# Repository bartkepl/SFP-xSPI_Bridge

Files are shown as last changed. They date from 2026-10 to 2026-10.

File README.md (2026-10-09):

# SFP-xSPI Bridge
## Mostek OCTOSPI / QUADSPI / SPI ↔ SFP na FPGA Gowin GW1N-9

Moduł łączący dwa mikrokontrolery STM32 łączem światłowodowym punkt–punkt, bez stosu IP. Host zapisuje i odczytuje ramki przez OCTOSPI, QUADSPI lub zwykłe SPI; FPGA koduje je w 8b/10b i wysyła przez moduł SFP z prędkością 100 Mbaud, a po drugiej stronie odzyskuje zegar programowo (soft-CDR z nadpróbkowaniem). Tryb przezroczysty UART pozwala użyć pary mostków jako „przedłużacza” portu szeregowego, bez żadnego sterownika.









> **Status:** projekt FPGA ukończony i zweryfikowany w symulacji (testy modułów i testy end-to-end dwóch kompletnych mostków), biblioteka C dla STM32 gotowa i przetestowana na modelu mostka, schemat i PCB rev. A zweryfikowane ([raport](doc/pcb-rev-a.md)), pliki produkcyjne wygenerowane — przed zamówieniem prototypu. Uruchomienie sprzętowe według [planu](doc/sfp-xspi-bridge-plan.md#9-plan-uruchomienia-bring-up).

```
STM32 ══ xSPI ══ GW1N-9 ══ LVDS ══ SFP ~~~ światłowód ~~~ SFP ══ LVDS ══ GW1N-9 ══ xSPI ══ STM32
```

---

## Płytka

<!-- Rendery generuje pcb/gen_media.kicad_jobset -->

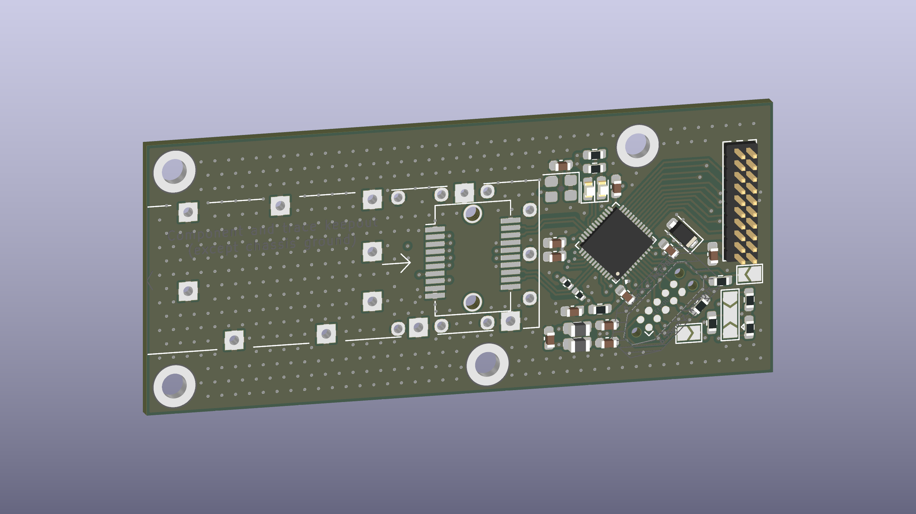
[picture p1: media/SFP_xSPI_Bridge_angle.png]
SFP-xSPI Bridge — widok pod kątem


| Góra (TOP) | Dół (BOTTOM) |
|---|---|
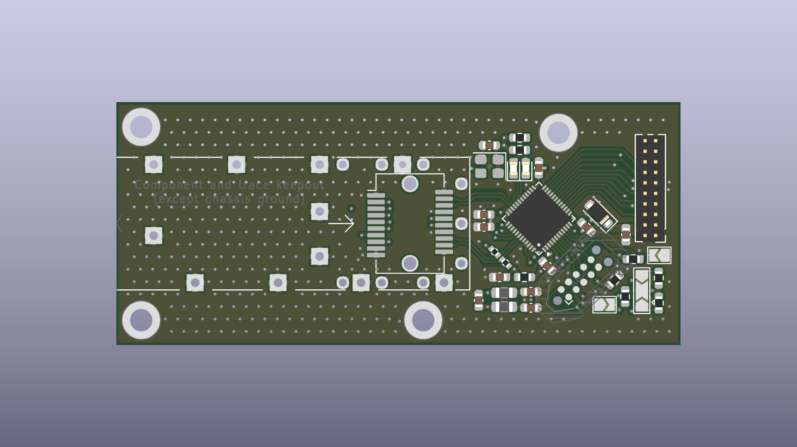
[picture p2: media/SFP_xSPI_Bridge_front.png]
TOP
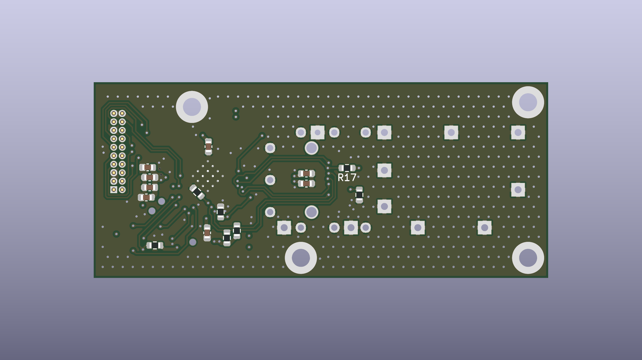
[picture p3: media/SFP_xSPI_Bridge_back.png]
BOTTOM
|  |  |

Płytka 4-warstwowa (JLC04161H-7628): pary LVDS na warstwie zewnętrznej nad ciągłą masą, płaszczyzna 3,3 V na warstwie wewnętrznej. Na płytce: klatka SFP, złącze hosta 2 × 10 (raster 1,27 mm), złącze programowania Tag-Connect TC2050 i zworka wyboru trybu. Zasilanie wyłącznie 3,3 V z hosta.

Wygenerowane PDF-y: [schemat](prod/sch/SFP_xSPI_Bridge.pdf) · [PCB](prod/pcb/SFP_xSPI_Bridge.pdf) · [interaktywny BOM](prod/ibom/SFP_xSPI_Bridge_ibom.html).

---

## Najważniejsze cechy

- **Łącze 100 Mbaud 8b/10b** przez standardowy moduł SFP bez wewnętrznego CDR (100BASE-FX / OC-3 lub 1000BASE-X, MM / SM, duplex lub BiDi).
- **Programowy odzysk zegara** — 4× nadpróbkowanie serializerami IDES8 (400 Msps), śledzenie fazy z histerezą, tolerancja odchyłki częstotliwości do ok. ±3900 ppm; oba końce na niezależnych generatorach, bez bufora elastycznego.
- **Ramki z CRC-32** (1–1024 B treści, pole TYPE do multipleksowania strumieni), kontrola przepływu XON/XOFF i gotowość odbiornika w sekwencji bezczynności — dane nie giną przy wolnym odbiorcy.
- **Interfejs hosta wzorowany na SPI NOR** — instrukcja i adres na 1 linii, dane na 1, 4 lub 8 liniach, SDR, tryb 0, SCLK do 40 MHz; współpracuje z OCTOSPI / XSPI / QUADSPI w trybie pośrednim i ze zwykłym SPI.
- **Spójne rejestry** — zatrzask przy opadnięciu CS, zapis stosowany po podniesieniu CS; FIFO TX 4 KiB i RX 8 KiB, przerwanie `HOST_IRQ_N`.
- **Tryb przezroczysty UART** — zworka lub rejestr; 8N1, 115 200 bit/s domyślnie, do ok. 3 Mbit/s, opcjonalnie RTS/CTS.
- **Zarządzanie modułem SFP** — I2C master w FPGA: pamięć A0h / A2h, automatyczny odczyt diagnostyki DDM, sygnały TX_DISABLE / TX_FAULT / LOS / MOD_ABS.
- **Diagnostyka łącza** — liczniki błędów kodu, CRC, długości, ramkowania, przepełnień i utrat synchronizacji; pętla zwrotna wewnątrz FPGA i echo ramek.
- **Biblioteka C dla STM32** konfigurowana przez `#define`, z portami HAL dla OCTOSPI, XSPI, QUADSPI i SPI.

---

## Specyfikacja

| Parametr | Wartość |
|---|---|
| FPGA | Gowin GW1N-UV9QN48C6/I5 (GW1N-9C), konfiguracja AUTOBOOT z wewnętrznej pamięci Flash |
| Łącze | 100 Mbaud, 8b/10b, ramki z CRC-32, bez retransmisji (błędy zgłaszane hostowi) |
| Przepustowość | do ok. 9,9 MB/s treści (ramki 1024 B) |
| Interfejs hosta | SPI 1-x-1, QSPI 1-0-4, OCTOSPI 1-0-8; SDR, tryb 0, SCLK ≤ 40 MHz |
| Bufory | FIFO TX 4 KiB, FIFO RX 8 KiB (BSRAM) |
| Tryb UART | 8N1, 115 200 bit/s (do ok. 3 Mbit/s), opcjonalnie RTS/CTS |
| Moduły SFP | INF-8074i, bez wewnętrznego CDR; SFP+ nieobsługiwane |
| Złącze hosta | 2 × 10, raster 1,27 mm: 3,3 V, SCLK, CS, IO0…IO7, DQS, IRQ, RST |
| Zasilanie | 3,3 V, ok. 0,45 A (moduł SFP do 300 mA) |
| PCB | 4 warstwy, 68 × 29,3 mm, 1,6 mm |
| Zajętość FPGA | 4483 LUT/ALU (52 %), 7 z 26 BSRAM; `clk_sys` 50 MHz (Fmax 56 MHz) |

---

## Architektura

```
             xSPI (SCLK ≤ 40 MHz)                                       LVDS 100 Mbaud
  STM32 ════════════════════════╗                                   ╔════════════════ SFP
                                ▼                                   │
          xspi_slave ─▶ csr_regs ─┬─▶ FIFO TX ─▶ framer + CRC ─▶ 8b/10b ─▶ OSER8 ─▶ TLVDS_OBUF ─▶ TD±
                                  │
                                  ├─◀ FIFO RX ◀─ deframer + CRC ◀─ 8b/10b ◀─ comma align ◀─ soft-CDR ◀─ IDES8 ◀─ RD±
                                  │
                                  ├─▶ I2C master + DDM ─▶ SFP SCL / SDA
                                  └─▶ sygnały SFP, LED, HOST_IRQ_N

  tryb UART:  UART_RX ─▶ pakietyzacja (ramki TYPE 0x01) ─▶ FIFO TX      FIFO RX ─▶ UART_TX
  zegary:     CLK_25M ─▶ rPLL 200 MHz (serializery) ─▶ CLKDIV /4 ─▶ clk_sys 50 MHz (logika)
```

Decyzje projektowe z uzasadnieniem: [rejestr ADR](doc/adr/README.md). Pełna koncepcja (piny, zegary, warstwa fizyczna, PCB, moduły, komendy, rejestry, uruchomienie): [`doc/sfp-xspi-bridge-plan.md`](doc/sfp-xspi-bridge-plan.md).

### Arkusze schematu

| Arkusz | Plik | Zawartość |
|---|---|---|
| root | [SFP_xSPI_Bridge.kicad_sch](pcb/SFP_xSPI_Bridge.kicad_sch) | połączenia hierarchiczne, otwory montażowe |
| EXT_IO | [ext_io.kicad_sch](pcb/ext_io.kicad_sch) | FPGA (zasilanie, konfiguracja, magistrala hosta), złącze hosta J3, Tag-Connect J2, zworki, TVS |
| SFP | [sfp.kicad_sch](pcb/sfp.kicad_sch) | klatka SFP, filtry zasilania modułu, terminacja i bias RX, generator 25 MHz, diody LED |

---

## Dokumentacja

| Dokument | Zawartość |
|---|---|
| [Interfejs hosta (datasheet)](doc/datasheet/index.md) | wyprowadzenia J3, parametry czasowe, komendy xSPI, mapa rejestrów, tryb UART, przykłady |
| [Biblioteka C (STM32)](doc/firmware.md) | konfiguracja, porty HAL, API, weryfikacja |
| [Koncepcja konstrukcji](doc/sfp-xspi-bridge-plan.md) | architektura, przydział pinów, zegary, PCB, moduły, uruchomienie |
| [Weryfikacja płytki rev. A](doc/pcb-rev-a.md) | DRC / ERC, zgodność z przydziałem pinów i INF-8074i, pary LVDS, zasilanie, pliki produkcyjne |
| [Projekt FPGA](doc/vhdl/index.md) | moduły VHDL, testbenche, symulacja, wyniki syntezy |
| [Testy end-to-end](doc/e2e/index.md) | dwa mostki połączone łączem: SPI, QSPI, OSPI, UART — z przebiegami |
| [Decyzje (ADR)](doc/adr/README.md) | kontekst, warianty i konsekwencje decyzji projektowych |

Dokumentacja jako serwis MkDocs (`mkdocs` 1.6, `mkdocs-material` 9.x):

```
python -m mkdocs serve        # podgląd: http://127.0.0.1:8000
```

---

## Szybki start

**FPGA** — Gowin EDA (projekt `vhdl/sfp_bridge/sfp_bridge.gprj`, VHDL-2008):

```
cd vhdl/sfp_bridge
gw_sh build.tcl               # synteza, PnR i bitstream
```

Bitstream: `vhdl/sfp_bridge/impl/pnr/sfp_bridge.fs`, programowanie przez JTAG (Gowin Programmer lub openFPGALoader).

**Symulacja** — GHDL 5 (VHDL-2008), na Windows w WSL; modele prymitywów z instalacji Gowin EDA:

```
$env:GOWIN_SIMLIB = "<Gowin EDA>\IDE\simlib\gw1n"   # PowerShell
cd vhdl\sim
.\run_tests.ps1               # wszystkie testbenche; .\view.ps1 <tb> — przebieg w GTKWave
```

**Firmware** — biblioteka w `firmware/sfp_bridge/`: skopiować `config/sfpb_config_template.h` jako `sfpb_config.h`, ustawić transport i uchwyt peryferium, wywołać `sfpb_init(&dev, NULL)`. Testy na PC: `make -C firmware/tests`.

**Bez hosta** — dwa mostki ze zwartą zworką `MODE_SEL` i dwa konwertery USB-UART (115 200 8N1) tworzą przezroczysty kanał szeregowy przez światłowód.

---

## Weryfikacja

| Obszar | Zakres | Wynik |
|---|---|---|
| Moduły FPGA | 24 samosprawdzające testbenche GHDL, testy mutacyjne | PASS |
| Łącze | dwa końce z odchyłką 200 ppm i jitterem, CDR do ±1000 ppm i ±0,3 UI | PASS |
| End-to-end | dwa kompletne mostki (modele prymitywów Gowin): SPI, QSPI, OSPI, UART zworką i rejestrem | PASS |
| Synteza | pełny układ, ograniczenia czasowe spełnione (`clk_sys` 56 MHz, `clk_host` 44 MHz) | OK |
| Biblioteka C | 207 sprawdzeń na modelu mostka, 17 mutacji wykrytych; kompilacja portów dla L4R5, H563, F446, L476, G0B1 | PASS |
| PCB | DRC i ERC bez błędów, przydział pinów 100 % zgodny z `.cst`, pary LVDS w regułach | OK |
| Sprzęt | uruchomienie prototypu rev. A | do wykonania |

---

## Roadmap

- [x] **Koncepcja** — architektura, dobór FPGA i modułów SFP, protokół łącza, interfejs hosta
- [x] **Schemat i PCB rev. A** w KiCad 10
- [x] **FPGA** — wszystkie moduły, integracja, ograniczenia czasowe, testy end-to-end
- [x] **Biblioteka C dla STM32** z testami na modelu mostka
- [x] **Weryfikacja płytki i pliki produkcyjne** rev. A
- [ ] **Zamówienie i montaż** prototypu
- [ ] **Uruchomienie** — konfiguracja FPGA, tryb UART przez światłowód, xSPI, I2C / DDM
- [ ] **Pomiary** — wykres oczkowy RD±, BER ≥ 10¹² bitów, różne moduły i tłumiki optyczne
- [ ] **Rozszerzenia** — 125 Mbaud, kolejna rewizja PCB z uwagami z uruchomienia

---

## Struktura repozytorium

```
.
├── doc/          # dokumentacja (MkDocs): koncepcja, datasheet, ADR, opisy modułów, testy end-to-end
├── firmware/     # biblioteka C dla STM32 (sfp_bridge), przykład, testy na PC
├── media/        # rendery 3D płytki
├── pcb/          # projekt KiCad 10 (schemat hierarchiczny, PCB, reguły DRC, biblioteka lokalna, jobsety)
├── prod/         # pliki produkcyjne: Gerbery (.zip), PDF schematu i PCB, interaktywny BOM
└── vhdl/         # projekt FPGA (Gowin EDA): źródła, ograniczenia, testbenche i skrypty symulacji
```

Pliki produkcyjne generują jobsety KiCad: [gen_prod.kicad_jobset](pcb/gen_prod.kicad_jobset) (PDF, BOM), [gen_gerber.kicad_jobset](pcb/gen_gerber.kicad_jobset) (Gerbery, wiercenia), [gen_media.kicad_jobset](pcb/gen_media.kicad_jobset) (rendery 3D).

---

## Referencje

- Gowin Semiconductor: DS100 (GW1N series), UG114 (GW1N-9 pinout), UG286 (zegary), UG289 (programowalne I/O), UG290 (programowanie i konfiguracja), UG284 (schematy), SUG935 (ograniczenia fizyczne)
- SFF Committee: INF-8074i (SFP MSA), SFF-8472 (diagnostyka modułów SFP)
- IEEE 802.3, klauzula 36 (kod 8b/10b, 1000BASE-X PCS)
- AMD/Xilinx XAPP224, XAPP523 — odzysk danych z nadpróbkowania
- STMicroelectronics: dokumentacja peryferiów OCTOSPI / XSPI / QUADSPI i sterowników HAL STM32Cube

---

## Licencja

[MIT](LICENSE) © 2026 bartkepl

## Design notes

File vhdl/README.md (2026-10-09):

# vhdl

Projekt FPGA mostka SFP-xSPI w Gowin EDA: VHDL-2008, synteza GowinSynthesis, układ GW1N-UV9QN48C6/I5 (GW1N-9C, `gw1n9c-003`).

```
constraints/
  sfp_bridge.cst           przydział pinów i standardy I/O
  sfp_bridge.sdc           ograniczenia czasowe (zegary, grupy asynchroniczne, opóźnienia xSPI)
sfp_bridge/
  sfp_bridge.gprj          projekt Gowin EDA
  build.tcl                budowa wsadowa (gw_sh)
  impl/                    wyniki syntezy i PnR (ignorowane), poza sfp_bridge_process_config.json
  src/pkg/                 bridge_pkg (stałe), code8b10b_pkg (kod 8b/10b)
  src/common/              sync_bit, reset_sync
  src/clk/                 clk_rst (rPLL, CLKDIV, resety), host_clk (DCS)
  src/fifo/                async_fifo
  src/link/                crc32, 8b/10b, tx_framer, rx_deframer, tx_gearbox, tx_phy, rx_phy,
                           cdr_os4x8, comma_align, link_ctrl
  src/uart/                uart_rx, uart_tx, uart_bridge
  src/host/                xspi_slave, csr_regs, frame_echo
  src/mgmt/                i2c_master, sfp_mgmt, leds
  src/top/                 sfp_bridge_top
sim/
  tb/                      testbenche tb_<moduł>.vhd, tb_pkg, e2e_bench (testy end-to-end)
  waves/                   widoki GTKWave (.gtkw)
  sources.txt              kolejność kompilacji do symulacji
  run_tests.ps1 / .sh      uruchamianie testów (GHDL)
  view.ps1                 podgląd przebiegu w GTKWave
  wave_svg.py              rysunki przebiegów testów end-to-end (doc/e2e/img)
  datasheet_svg.py         diagramy datasheetu (doc/datasheet/img)
```

Ustawienia projektu (`impl/sfp_bridge_process_config.json`): VHDL-2008, top `sfp_bridge_top`, piny MSPI jako GPIO (`-use_mspi_as_gpio 1`), konfiguracja AUTOBOOT.

## Budowa

```
cd sfp_bridge
gw_sh build.tcl
```

Bitstream: `sfp_bridge/impl/pnr/sfp_bridge.fs`.

## Symulacja

GHDL 5 (VHDL-2008); na Windows `run_tests.ps1` uruchamia `run_tests.sh` w WSL. Moduły z prymitywami Gowin korzystają z modeli producenta kompilowanych do biblioteki `gw1n`.

| Zmienna | Znaczenie |
|---|---|
| `GOWIN_SIMLIB` | katalog modeli symulacyjnych Gowin EDA: `<Gowin EDA>/IDE/simlib/gw1n` (wymagana) |
| `GHDL_WSL_DISTRO` | dystrybucja WSL z GHDL (domyślnie dystrybucja domyślna) |
| `GTKWAVE` | ścieżka do `gtkwave.exe` dla `view.ps1` (domyślnie `gtkwave` z `PATH`) |

```
cd sim
.\run_tests.ps1               # wszystkie testbenche
.\run_tests.ps1 tb_crc32      # wybrany testbench
.\view.ps1 tb_crc32           # przebieg w GTKWave
```

Opis modułów, wyniki testów i syntezy: [`../doc/vhdl/index.md`](../doc/vhdl/index.md); testy end-to-end: [`../doc/e2e/index.md`](../doc/e2e/index.md).

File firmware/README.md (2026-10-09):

# firmware

Biblioteka C `sfp_bridge` dla STM32 — host mostka SFP-xSPI. C11, bez dynamicznej alokacji, konfiguracja przez `#define` w `sfpb_config.h`, porty HAL dla OCTOSPI, XSPI, QUADSPI i SPI (opcjonalnie DMA) oraz własny transport.

```
sfp_bridge/include/   API (sfp_bridge.h), komendy i rejestry, interfejs transportu
sfp_bridge/config/    szablon sfpb_config.h
sfp_bridge/src/       implementacja
sfp_bridge/port/      porty STM32 HAL
examples/             przykład użycia
tests/                testy na PC z modelem mostka
```

Szybki start:

1. Dodać `sfp_bridge/src/*.c`, `sfp_bridge/port/*.c` i ścieżki `include/`, `src/`, `port/`.
2. Skopiować `sfp_bridge/config/sfpb_config_template.h` jako `sfpb_config.h`, ustawić `SFPB_TRANSPORT` i uchwyt peryferium.
3. `sfpb_init(&dev, NULL)`, w obsłudze EXTI `HOST_IRQ_N` — `sfpb_irq_notify(&dev)`, w pętli głównej — `sfpb_process(&dev, 0)`.

Testy: `make -C tests` (gcc).

Dokumentacja: [`../doc/firmware.md`](../doc/firmware.md); protokół i rejestry: [`../doc/datasheet/index.md`](../doc/datasheet/index.md).

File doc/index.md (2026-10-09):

# SFP-xSPI Bridge

Moduł mostka **OCTOSPI / QUADSPI / SPI ↔ SFP** łączący dwa mikrokontrolery STM32 łączem światłowodowym punkt–punkt, bez stosu IP. Transmisja odbywa się własnym protokołem ramkowym z kodowaniem 8b/10b i programowym odzyskiem zegara (soft-CDR) w FPGA Gowin GW1N-UV9QN48C6/I5. Tryb przezroczysty UART przenosi strumień bajtów między dwoma portami szeregowymi bez sterownika.

```
STM32 <== xSPI ==> GW1N-9 <== LVDS ==> SFP ~~~ światłowód ~~~ SFP <==> GW1N-9 <==> STM32
```

## Dokumentacja

| Część | Zawartość |
|---|---|
| [Koncepcja konstrukcji](sfp-xspi-bridge-plan.md) | architektura, przydział pinów, zegary, warstwa fizyczna i PCB, moduły FPGA, komendy xSPI, rejestry, plan uruchomienia |
| [Interfejs hosta (datasheet)](datasheet/index.md) | wyprowadzenia, parametry czasowe, komendy xSPI, mapa rejestrów, tryb UART |
| [Biblioteka C (STM32)](firmware.md) | konfiguracja, porty HAL, API, weryfikacja |
| [Weryfikacja płytki rev. A](pcb-rev-a.md) | reguły projektowe, zgodność połączeń, pary LVDS, zasilanie, pliki produkcyjne |
| [Projekt FPGA](vhdl/index.md) | struktura projektu, konwencje kodu, symulacja, opisy modułów, wyniki syntezy |
| [Testy end-to-end](e2e/index.md) | dwa kompletne mostki połączone łączem, z przebiegami |
| [Decyzje (ADR)](adr/README.md) | rejestr decyzji projektowych z uzasadnieniem |

## Budowa dokumentacji

```
python -m mkdocs serve     # podgląd: http://127.0.0.1:8000
python -m mkdocs build     # statyczny serwis w site/
```

Wymagania: `mkdocs` 1.6 i `mkdocs-material` 9.x.

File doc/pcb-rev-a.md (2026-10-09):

# Płytka rev. A — weryfikacja projektu

Raport z weryfikacji schematu i PCB rev. A przed wykonaniem prototypu. Zakres: zgodność połączeń z przydziałem pinów FPGA i dokumentacją elementów, reguły projektowe (DRC, ERC), prowadzenie par LVDS, zasilanie i odsprzęganie, wykonalność produkcyjna oraz komplet plików produkcyjnych.

## 1 Opis płytki

| Parametr | Wartość |
|---|---|
| Wymiary | 68,0 × 29,3 mm, 4 otwory montażowe M2,5 (GND) |
| Stos | 4 warstwy, 1,6 mm, JLC04161H-7628: L1 sygnały i pary LVDS, L2 GND, L3 +3V3, L4 sygnały i wylewka GND |
| Schemat | 3 arkusze: główny, `EXT_IO` (FPGA, złącze hosta, programowanie), `SFP` (klatka, filtry, terminacja RX, generator, diody) |
| Elementy | 53: U1 GW1N-UV9QN48C6/I5, J1 klatka SFP, J2 TC2050, J3 2 × 10 / 1,27 mm, Y1 25 MHz, L1/L2 1 µH, D1 TVS, D2/D3 LED, JP1–JP3, 17 rezystorów, 19 kondensatorów, H1–H4 |
| Zasilanie | 3,3 V z hosta (J3, piny 1–2), bez stabilizatora; TVS D1 przy złączu |
| Montaż | ręczny; elementy na obu stronach (na dolnej: 15 elementów pasywnych 0603 — kondensatory odsprzęgające i filtra SFP, część rezystorów) |

## 2 Reguły projektowe

**DRC** (wszystkie poziomy, z ponownym wypełnieniem stref i kontrolą zgodności ze schematem): 0 błędów, 0 niepołączonych elementów, 0 rozbieżności schemat–PCB. Ostrzeżenia:

| Ostrzeżenie | Liczba | Ocena |
|---|---|---|
| `silk_overlap` — nakładające się opisy D2/D3 i R1/JP2 | 6 | kosmetyka nadruku |
| `silk_edge_clearance` — obrys J1 przycięty krawędzią płytki | 3 | wynika z wysięgu klatki poza krawędź; bez wpływu |
| `lib_footprint_mismatch` — U1 | 1 | zamierzone: pole EPAD z przelotkami 0,3 mm zamiast 0,2 mm z biblioteki |

**ERC:** 0 błędów; 3 ostrzeżenia `lib_symbol_mismatch` (symbole zworek lutowanych różnią się od biblioteki) i 1 `multiple_net_names` (GND i EPAD U1 na jednym węźle — zamierzone, EPAD jest masą).

## 3 Połączenia

### 3.1 FPGA

Wszystkie przydziały `IO_LOC` z `vhdl/constraints/sfp_bridge.cst` porównano z sieciami padów U1 w PCB: 25 portów (pary różnicowe po pinie A), **zgodność 100 %**, w tym odwrócona para RD (`sfp_rd_n` na pinie 43, `sfp_rd_p` na 42, kompensowana w `rx_phy`). Bitstream jest budowany z tego samego pliku `.cst`.

| Obszar | Podstawa | Wynik |
|---|---|---|
| Zasilanie U1: VCC 12, 37; VCCX 36; VCCIO 1, 25; VSS 2, 26, EPAD | UG114 (QN48) | zgodne |
| Konfiguracja: MODE (48) 1 kΩ do GND (AUTOBOOT); JTAGSEL_N, RECONFIG_N, DONE — 10 kΩ do 3,3 V; TCK 4,7 kΩ do GND | UG290 (rys. 7-1, tab. 7-3) | zgodne |
| `CLK_25M` na dedykowanym wejściu PLL (35) | UG114, UG286 | zgodne |
| `MODE_SEL` (10): 10 kΩ do 3,3 V (R16), JP3 do GND | [ADR 0006](adr/0006-tryb-uart-przezroczysty.md) | zgodne |

### 3.2 Moduł SFP

| Obszar | Podstawa | Wynik |
|---|---|---|
| Złącze J1, 20 pinów: VeeT 1/17/20, VeeR 9/10/11/14, TD± 18/19, RD± 13/12, VccT 16, VccR 15, sygnały 2–8 | INF-8074i, rys. 3 | zgodne |
| Filtr zasilania: 2 × 1 µH, 0,1 µF przy VccT i VccR, 10 µF na VccR, 10 µF + 0,1 µF po stronie 3,3 V | INF-8074i, rys. 2A | zgodne |
| `SFP_TX_DIS`: pull-up 4,7 kΩ do 3,3 V (R17) — laser wyłączony w czasie konfiguracji FPGA | INF-8074i, rys. 2B | zgodne |
| `SFP_SCL`, `SFP_SDA`: pull-up 10 kΩ (R4, R3) | INF-8074i (4,7–10 kΩ) | zgodne |
| `RATE_SELECT`: 10 kΩ do GND (R8) | [koncepcja](sfp-xspi-bridge-plan.md), 5.1 | zgodne |
| `SFP_TX_FAULT`, `SFP_LOS`, `SFP_MOD_ABS`: wewnętrzne pull-upy FPGA zamiast 4,7–10 kΩ na płytce | INF-8074i, rys. 2B | odstępstwo rev. A — sygnały wolne i filtrowane (50 µs / 10 ms); rezystory w kolejnej rewizji |
| Terminacja RX: R9/R10 49,9 Ω przy pinach 42/43, Vbias 1,20 V (R11 2,1 kΩ / R12 1,2 kΩ, C6) | [ADR 0002](adr/0002-terminacja-rx-zewnetrzna.md) | zgodne; odcinek do odbiornika ok. 3,7 mm (wartość projektowa ≤ 2 mm) — pomijalne przy 100 Mbaud |

### 3.3 Złącza hosta i programowania

- J3 (2 × 10, 1,27 mm): 3,3 V na pinach 1–2, GND 3/5/15/19/20, magistrala xSPI, `HOST_IRQ_N`, `HOST_RST_N` — zgodnie z [koncepcją](sfp-xspi-bridge-plan.md), 5.5.
- J2 (TC2050): układ ARM Cortex 10-pin; AUX przez R7 1 kΩ i JP2 na `JTAGSEL_N` lub `DONE`; nRESET przez JP1 (domyślnie rozwarta) na `RECONFIG_N` — zgodnie z 5.6.

Elementy, dla których pinout oceniono według konwencji obudowy (bez porównania z kartą katalogową w tej weryfikacji): Y1 (generator 3225: 1 EN, 2 GND, 3 OUT, 4 VDD), D1 (SOD-123FL, katoda do 3,3 V), D2/D3 (anoda przez 1 kΩ do 3,3 V, ok. 1,3 mA).

## 4 Pary LVDS

| Para | Długość ścieżek P / N | Różnica | Szerokość / odstęp | Warstwa |
|---|---|---|---|---|
| TD (U1 34/33 → J1 18/19) | 9,43 / 9,76 mm | 0,33 mm | 0,20 / 0,20 mm | F.Cu, bez przelotek |
| RD (J1 13/12 → U1 42/43) | 11,37 / 11,71 mm | 0,33 mm | 0,20 / 0,20 mm | F.Cu, bez przelotek |

Obie pary w całości nad ciągłą płaszczyzną GND (L2). Różnica długości mieści się w regule 0,5 mm (`pcb/SFP_xSPI_Bridge.kicad_dru`, liczona wewnątrz pary); przy UI = 10 ns odpowiada ok. 2 ps i jest pomijalna. Odstęp od innych sieci i wylewek zgodny z regułą 0,5 mm; odcinki niesprzężone przy padach U1, J1 i rezystorach terminacji mieszczą się w limicie 2 mm.

## 5 Zasilanie i odsprzęganie

- Tor 3,3 V: J3 → ścieżka 1,0 mm (F.Cu) i 0,6–0,8 mm (B.Cu) → przelotki do płaszczyzny L3. Pobór szacowany 0,45 A (moduł SFP do 300 mA) — zapas kilkukrotny.
- Każdy pin zasilania U1 ma kondensator 100 nF w odległości 1,5–2,3 mm (C1, C2, C4, C5, C19); Y1 — C12 (3,4 mm); VccT / VccR — C7 / C8 (2,6 mm).
- Płaszczyzna L2 (GND) ciągła poza otworami przelotek. W L3 (+3V3) ścieżki VccR/VccT tworzą szczelinę pod obszarem złącza SFP; nad nią przebiegają wyłącznie wolne sygnały (I2C, LOS, MOD_ABS).
- Przelotki: 494 (490 × 0,6/0,3 mm, 4 × 0,45/0,3 mm), w tym 437 GND — zszycie wylewek L1/L4 z płaszczyzną L2 na całej powierzchni płytki i wzdłuż par LVDS.
- EPAD U1: 16 przelotek 0,3 mm do GND; moc FPGA < 0,5 W, brak innych źródeł ciepła.
- `CLK_25M` (9,7 mm): jedna para przelotek, odcinek na B.Cu; ścieżka powrotna przez płaszczyznę +3V3 odsprzęganą w pobliżu. Przy 25 MHz bez wpływu na działanie.

## 6 Wykonalność produkcyjna

| Parametr | Wartość | Próg technologii (JLCPCB, 4 warstwy) |
|---|---|---|
| Ścieżka / odstęp min. | 0,20 / 0,20 mm | 0,09 / 0,09 mm |
| Otwór min. | 0,30 mm | 0,30 mm bez dopłaty |
| Przelotka min. | 0,45 / 0,30 mm | 0,4–0,45 / 0,3 mm bez dopłaty |
| Via-in-pad | EPAD, bez wypełniania | bez opcji płatnych |
| Odstęp miedzi od krawędzi | ≥ 0,5 mm | 0,2–0,3 mm |

- Klatka J1 wystaje poza krawędź płytki (montaż klatki do panelu urządzenia); wysięg należy porównać z rysunkiem zamawianej klatki ([koncepcja](sfp-xspi-bridge-plan.md), rozdz. 10).
- Brak fiducjali i punktów testowych — zbędne przy montażu ręcznym.

## 7 Pliki produkcyjne

| Plik | Zawartość |
|---|---|
| `prod/SFP_xSPI_Bridge.zip` | Gerbery 4 warstw miedzi, maski, pasty, nadruki, obrys; wiercenia PTH i NPTH (13 plików) |
| `prod/sch/SFP_xSPI_Bridge.pdf` | schemat |
| `prod/pcb/SFP_xSPI_Bridge.pdf` | rysunek PCB |
| `prod/ibom/SFP_xSPI_Bridge_ibom.html` | interaktywny BOM do montażu ręcznego |
| `media/SFP_xSPI_Bridge_{angle,front,back}.png` | rendery 3D |

Pliki generują jobsety KiCad (`pcb/gen_gerber.kicad_jobset`, `gen_prod.kicad_jobset`, `gen_media.kicad_jobset`) z bieżącej wersji schematu i PCB.

## 8 Wynik

Płytka rev. A jest gotowa do wykonania. Połączenia FPGA są zgodne z plikiem ograniczeń bitstreamu, połączenia modułu SFP i filtr zasilania — z INF-8074i; pary LVDS spełniają reguły projektowe; DRC i ERC nie zgłaszają błędów.

Uwagi do kolejnej rewizji (nie blokują rev. A):

1. Pull-upy 4,7–10 kΩ na `SFP_TX_FAULT`, `SFP_LOS`, `SFP_MOD_ABS`.
2. Uporządkowanie nadruku (D2/D3, R1/JP2); nazwa i rewizja płytki na nadruku oraz w tabliczkach arkuszy.
3. Model 3D klatki SFP i numery katalogowe (MPN) w polach symboli.
4. Złącze hosta z kluczem (box header 1,27 mm) albo wyraźne oznaczenie pinu 1.
5. Terminacja RX bliżej pinów 42/43, `CLK_25M` w całości na F.Cu.

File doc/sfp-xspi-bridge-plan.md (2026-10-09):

# SFP-xSPI Bridge — koncepcja konstrukcji

Moduł mostka **OCTOSPI / QUADSPI / SPI ↔ SFP (światłowód)** do łączenia dwóch mikrokontrolerów (STM32) łączem optycznym punkt–punkt, bez stosu IP. Własny, lekki protokół ramkowy z kodowaniem 8b/10b i programowym odzyskiem zegara (soft-CDR) w małym FPGA Gowin. Tryb przezroczysty UART pozwala użyć mostka bez hosta SPI.

| Element | Wybór |
|---|---|
| FPGA | Gowin **GW1N-UV9QN48C6/I5** (GW1N-9, wersja C) — wybór uzasadnia [ADR 0001](adr/0001-fpga-gw1n-9.md) |
| Narzędzia | KiCad 10 (PCB), Gowin EDA (VHDL-2008), GHDL + GTKWave (symulacja, [ADR 0003](adr/0003-weryfikacja-ghdl.md)), C11 (biblioteka STM32) |
| Prędkość linii | **100 Mbaud** (8b/10b → 80 Mbit/s → ok. 9 MB/s danych użytecznych) |
| Interfejs hosta | SPI (1-x-1), QSPI (1-0-4), OCTOSPI (1-0-8), SDR, tryb 0, SCLK ≤ 40 MHz ([ADR 0009](adr/0009-interfejs-hosta.md)) — albo tryb przezroczysty UART ([ADR 0006](adr/0006-tryb-uart-przezroczysty.md)) |
| Protokół łącza | ramki z CRC-32 bez retransmisji, gotowość odbiornika i XON/XOFF w sekwencji bezczynności ([ADR 0005](adr/0005-protokol-lacza.md), [ADR 0008](adr/0008-stan-lacza.md)) |
| Zegar logiki | `clk_sys` = 50 MHz, serializery IDES8/OSER8 przy 200 MHz ([ADR 0007](adr/0007-zegar-systemowy-50mhz.md)) |
| Strona optyczna | moduł SFP (INF-8074i) bez wewnętrznego CDR: 100BASE-FX / OC-3 lub 1000BASE-X (MM/SM, duplex lub BiDi); SFP+ nieobsługiwane |
| Zasilanie | jedno **3,3 V** (wersja UV FPGA, moduł SFP) |

Dokument opisuje przyjęte rozwiązania konstrukcyjne: architekturę, przydział pinów, zegary, warstwę fizyczną i płytkę, projekt FPGA, interfejs hosta, bibliotekę STM32 oraz plan uruchomienia. Uzasadnienia decyzji zawiera [rejestr ADR](adr/README.md), szczegóły programowania — [datasheet interfejsu hosta](datasheet/index.md). Pozycje oznaczone **[DO WERYFIKACJI]** wymagają potwierdzenia na prototypie lub w dokumentacji wybranych elementów (rozdział 10).

---

## 1. Architektura

```
            OCTOSPI/QSPI/SPI                       LVDS 100 Mbaud
  STM32  <=====================>  GW1N-9    <=====================>  SFP  ~~~ światłowód ~~~  SFP <=> GW1N <=> STM32
  (master)   CLK, CS, IO0..7,      (FPGA)     TD±  -> moduł SFP
             DQS, IRQ, RST                   RD±  <- moduł SFP
                                   I2C master ---> SFP EEPROM/DDM (0x50/0x51)
                                   GPIO ---------> TX_DISABLE, TX_FAULT, LOS, MOD_ABS

  tryb UART (zworka MODE_SEL):  urządzenie UART <== RX/TX (IO0/IO1), opcj. RTS/CTS ==> GW1N-9 <== LVDS ==> ...
```

Wewnątrz FPGA:

```
 xSPI slave ─> rejestry/CSR ─┬─> TX FIFO ─> framer ─> CRC32 ─> enc 8b/10b ─> serializer ─> TLVDS_OBUF ─> SFP TD±
  (domena SCLK)              │
                             ├─< RX FIFO <─ deframer <─ CRC check <─ dec 8b/10b <─ comma align <─ soft-CDR <─ IDES8 <─ TLVDS_IBUF <─ SFP RD±
                             │
                             ├─> I2C master + mailbox + autopolling DDM ─> SFP SCL/SDA
                             └─> GPIO SFP, LED, IRQ

 tryb UART: uart_rx ─> pakietyzator (ramki TYPE 0x01) ─> TX FIFO ;  RX FIFO ─> depakietyzator ─> uart_tx
```

Domeny zegarowe:

| Domena | Źródło | Częstotliwość | Co pracuje |
|---|---|---|---|
| `clk_spi` / `clk_host` | pin SCLK od MCU (przez `DCS`; w trybach UART i echa `clk_sys`) | ≤ 40 MHz | slave xSPI, strona hosta FIFO |
| `clk_fast` | PLL | 200 MHz | FCLK serializerów IDES8 / OSER8 |
| `clk_sys` | CLKDIV(/4) z `clk_fast` | 50 MHz | całe łącze: CDR, 8b/10b, framer, CRC, FIFO (strona łącza), I2C, UART, CSR — [ADR 0007](adr/0007-zegar-systemowy-50mhz.md) |

Przejścia między domenami: asynchroniczne FIFO (BSRAM w trybie semi-dual port; wskaźnik odczytu w kodzie Graya, zatwierdzony wskaźnik zapisu przez handshake — [`async_fifo`](vhdl/async_fifo.md)) oraz synchronizatory 2-FF dla pojedynczych bitów ([`sync_bit`](vhdl/sync.md)). Reset: [ADR 0004](adr/0004-strategia-resetu.md).

---

## 2. Kluczowe parametry układu (z DS100, wersja 3.3.3E)

Kolumna GW1N-4 pozostaje dla porównania; układem docelowym jest GW1N-9 ([ADR 0001](adr/0001-fpga-gw1n-9.md)).

| Parametr | GW1N-4 | GW1N-9 | Uwagi |
|---|---|---|---|
| LUT4 / FF | 4608 / 3456 | 8640 / 6480 | |
| BSRAM | 10 × 18 kbit (180 kbit) | 26 × 18 kbit (468 kbit) | |
| PLL | 2 | 2 | |
| User Flash | 256 kbit | 608 kbit | wewnętrzny Flash konfiguracji + user Flash |
| QN48: I/O użytkownika (pary true LVDS) | **40 (9)** | **40 (12)** | QN48F dla GW1N-9: 40 (11) |
| IDES4, max szybkość szeregowa (C6/I5) | 750 Mbps | 750 Mbps | |
| IDES8/10, max (C6/I5) | 1000 Mbps | 1000 Mbps | IDES8/OSER8 pracują przy 400 Msps |
| PLL FIN | 3–400 MHz | 3–400 MHz | |
| PLL VCO (C6/I5) | 400–1000 MHz | 400–1200 MHz | |
| PLL FOUT max (C6/I5) | 500 MHz | 600 MHz | |
| LVDS wyjście VOD / VOS | 250–450 mV / 1,125–1,375 V | jw. | przy RT = 100 Ω |
| LVDS wejście VCM / VTHD | 0,05–2,1 V / ±100 mV | jw. | |
| Oscylator wewnętrzny | 105 MHz (ok. ±7%) | 125 MHz (±5%) | **nie** do łącza |

Ważne ograniczenia z DS100:

- **GW1N-9 wersja C** (GW1N-UV9QN48C6/I5): BSRAM obsługuje tryb dual-port, lecz nie obsługuje szerokości danych 1 i 2 bit. FIFO pozostaje w trybie **semi-dual port** (zapis port A, odczyt port B, osobne zegary).
- **GW1N-9 wersja C:** ograniczenia VCCIO dla Bank0/1/3 nie obowiązują. Wszystkie banki pracują przy 3,3 V.
- Ograniczenie GW1N-4 (piny `IOL10x`/`IOR10x` bez IO logic) nie dotyczy GW1N-9 (UG289, rozdz. 4).
- **UV:** jeżeli w obudowie VCC i VCCX dzielą pin, VCC musi wynosić 2,5–3,3 V. Przy jednym 3,3 V spełnione.
- **True LVDS input** wymaga terminacji 100 Ω. W GW1N-9 wewnętrzna programowalna terminacja 100 Ω jest dostępna **wyłącznie w banku 0** (UG289, rozdz. 3.3.2; atrybut `.cst`: `DIFF_RESISTOR=ON`). Wariantem podstawowym jest terminacja zewnętrzna (5.2, [ADR 0002](adr/0002-terminacja-rx-zewnetrzna.md)); wewnętrzna pozostaje opcją awaryjną.
- Wejście różnicowe (`TLVDS_IBUF`) obsługują wszystkie banki. Wyjście true LVDS (`TLVDS_OBUF`) wyłącznie pary oznaczone w UG114 jako *TRUE*. Prąd wyjścia LVDS25 w GW1N-9: 1,25 / 2 / 2,5 / 3,5 mA (DS100, tab. 2-1).
- Podczas konfiguracji wszystkie GPIO są w stanie wysokiej impedancji ze słabym pull-upem. Uwzględnić w sterowaniu `TX_DISABLE` (pull-up = laser wyłączony, to dobrze).
- **QN48, tryb konfiguracji:** MODE0 jest wewnętrznie zwarty do masy, MODE1 i MODE2 są połączone na pinie 48. Pin 48 w stanie niskim daje `000` = AUTOBOOT, w stanie wysokim `110` = DUAL BOOT (UG290, tab. 5-1). Ze względu na wewnętrzny pull-up pin 48 wymaga **zewnętrznego rezystora do masy**.

---

## 3. Przydział pinów

Numery pinów pochodzą z UG114 (GW1N-9 Pinout, kolumna QN48). Przydział, wszystkie alternatywy z tabeli 3.3 oraz warianty negatywne są sprawdzone syntezą i PnR w Gowin EDA 1.9.11.03 (projekt próbny z rPLL, CLKDIV, serializerami i kompletem portów). Plik ograniczeń: `vhdl/constraints/sfp_bridge.cst`.

Bilans: 41 wyprowadzeń I/O w QN48, z czego 8 to piny konfiguracyjne (3–9, 48), 27 jest przydzielonych (w tym `MODE_SEL`, [ADR 0006](adr/0006-tryb-uart-przezroczysty.md)), 6 pozostaje w zapasie.

Rozkład na obudowie (numeracja przeciwnie do ruchu wskazówek zegara od lewego górnego narożnika): lewa krawędź 1–12, dolna 13–24, prawa 25–36, górna 37–48. Wynikający z tego układ płytki: **złącze hosta przy dolnej krawędzi, klatka SFP przy prawym górnym narożniku, JTAG przy lewej krawędzi**.

```
                   48   47  46  45  44  43  42  41  40  39  38  37
                  MODE SDA SCL  -   -  RDN RDP ABS LOS FLT DIS VCC
     VCCIO0/3  1                                                    36  VCCX
          VSS  2                                                    35  CLK_25M
    JTAGSEL_N  3                                                    34  TD_P
          TMS  4                                                    33  TD_N
          TCK  5                                                    32  LED_ACT
          TDI  6                    GW1N-UV9QN48                    31  LED_LINK
          TDO  7                                                    30  -
   RECONFIG_N  8                                                    29  -
         DONE  9                                                    28  -
     MODE_SEL 10                                                    27  -
   HOST_RST_N 11                                                    26  VSS
          VCC 12                                                    25  VCCIO1/2
                  IRQ  CS  IO0 IO1 IO2 IO3 SCLK DQS IO4 IO5 IO6 IO7
                   13   14  15  16  17  18  19  20  21  22  23  24
```

### 3.1 Tabela sygnałów

Nazwy sieci w schemacie pisane są wielkimi literami, porty VHDL małymi (`SFP_TD_P` ↔ `sfp_td_p`).

| Sygnał | Kier. | Standard I/O | Pin | Bank | Miejsce w UG114 | Uwagi |
|---|---|---|---|---|---|---|
| `SFP_TD_P` | out | LVDS25, DRIVE=3.5 | **34** | 1 | IOR11A (MI/D7) | para z wyjściem true LVDS; funkcja MSPI nieużywana w AUTOBOOT |
| `SFP_TD_N` | out | LVDS25 | **33** | 1 | IOR11B (MO/D6) | |
| `SFP_RD_P` | in | LVDS25 | **42** | 0 | IOT32B | IDES8; terminacja zewnętrzna (5.2), wewnętrzna jako opcja awaryjna; **polaryzacja odwrócona** (3.2, reguła 9) |
| `SFP_RD_N` | in | LVDS25 | **43** | 0 | IOT32A | wejście `I` bufora `TLVDS_IBUF` |
| `CLK_25M` | in | LVCMOS33 | **35** | 1 | IOR5A (RPLL_T_in) | dedykowane wejście prawego PLL |
| `XSPI_SCLK` | in | LVCMOS33 | **19** | 2 | IOB29A (GCLKT_4) | wejście zegara globalnego, środek magistrali; ≤ 40 MHz ([ADR 0009](adr/0009-interfejs-hosta.md)) |
| `XSPI_CS_N` | in | LVCMOS33, pull-up | **14** | 2 | IOB8B | |
| `XSPI_IO0` | inout | LVCMOS33 | **15** | 2 | IOB17A | |
| `XSPI_IO1` | inout | LVCMOS33 | **16** | 2 | IOB17B | |
| `XSPI_IO2` | inout | LVCMOS33 | **17** | 2 | IOB27A | |
| `XSPI_IO3` | inout | LVCMOS33 | **18** | 2 | IOB27B | |
| `XSPI_DQS` | out | LVCMOS33 | **20** | 2 | IOB29B (GCLKC_4) | nieużywany (SDR), stan wysokiej impedancji; rezerwa na tryb DTR |
| `XSPI_IO4` | inout | LVCMOS33 | **21** | 2 | IOB35A | |
| `XSPI_IO5` | inout | LVCMOS33 | **22** | 2 | IOB35B | |
| `XSPI_IO6` | inout | LVCMOS33 | **23** | 2 | IOB39A | |
| `XSPI_IO7` | inout | LVCMOS33 | **24** | 2 | IOB39B | |
| `HOST_IRQ_N` | out | LVCMOS33 | **13** | 2 | IOB8A | open-drain lub push-pull |
| `HOST_RST_N` | in | LVCMOS33, pull-up | **11** | 3 | IOL15B (GCLKC_6) | reset logiki, nie rekonfiguracja |
| `SFP_TX_DIS` | out | LVCMOS33 | **38** | 1 | IOT42B | pull-up wewnątrz modułu (laser wyłączony, dopóki FPGA nie wystawi 0) |
| `SFP_TX_FAULT` | in | LVCMOS33, PULL_MODE=UP | **39** | 1 | IOT42A | brak zewnętrznego pull-upu (rev. A) — wewnętrzny pull-up FPGA |
| `SFP_LOS` | in | LVCMOS33, PULL_MODE=UP | **40** | 1 | IOT37B | jw. |
| `SFP_MOD_ABS` | in | LVCMOS33, PULL_MODE=UP | **41** | 1 | IOT37A | MOD_DEF0; jw. |
| `SFP_SCL` | inout (OD) | LVCMOS33, OPEN_DRAIN | **46** | 3 | IOT12B | MOD_DEF1; pull-up 4,7 kΩ |
| `SFP_SDA` | inout (OD) | LVCMOS33, OPEN_DRAIN | **47** | 3 | IOT12A | MOD_DEF2; pull-up 4,7 kΩ |
| `MODE_SEL` | in | LVCMOS33, PULL_MODE=UP | **10** | 3 | IOL15A (GCLKT_6) | wybór trybu ([ADR 0006](adr/0006-tryb-uart-przezroczysty.md)): otwarta zworka = xSPI, zwarta do masy = UART; pull-up 10 kΩ |
| `LED_LINK` | out | LVCMOS33 | **31** | 1 | IOR12B (MCLK/D4) | aktywny stanem niskim (3V3 → 1 kΩ → LED → pin) |
| `LED_ACT` | out | LVCMOS33 | **32** | 1 | IOR12A (MCS_N/D5) | aktywny stanem niskim |

Piny zapasowe: **27/28** (IOR24, para z wyjściem true LVDS), **29/30** (IOR17, para z wyjściem true LVDS, GCLKT_3), **44/45** (IOT22, bank 0, para z opcją terminacji wewnętrznej); w rev. A niepodłączone (znaczniki no-connect).

Piny konfiguracyjne i zasilania, **nieużywane jako GPIO**:

| Pin | Sygnał | Połączenie |
|---|---|---|
| 3 | `JTAGSEL_N` (także LPLL_T_in) | pull-up 4,7–10 kΩ; AUX programatora przez JP2 (5.6); opcja „Use JTAG as regular IO” wyłączona |
| 4, 5, 6, 7 | `TMS`, `TCK`, `TDI`, `TDO` | złącze TC2050 (5.6); TCK z pull-downem 4,7 kΩ (UG290, tab. 7-3) |
| 8 | `RECONFIG_N` | pull-up 10 kΩ; nRESET programatora przez JP1, domyślnie rozwartą (5.6) |
| 9 | `DONE` | pull-up 10 kΩ (R6); opcjonalnie AUX programatora przez JP2; bez diody LED; `READY` nie jest wyprowadzony w QN48 |
| 48 | `MODE2` + `MODE1` (MODE0 wewnętrznie do masy) | **1 kΩ do masy** (UG290, Figure 7-1) → `000` = AUTOBOOT. Wewnętrzny pull-up do 150 µA (DS100, IPU): 10 kΩ dałoby do 1,5 V, czyli ryzyko odczytu stanu wysokiego i DUAL BOOT |
| 12, 37 | `VCC` | 3,3 V (wersja UV, wewnętrzny stabilizator rdzenia) |
| 36 | `VCCX` | 3,3 V |
| 1 | `VCCIO0` / `VCCIO3` | 3,3 V |
| 25 | `VCCIO1` / `VCCIO2` | 3,3 V |
| 2, 26, EPAD (49) | `VSS` | masa; **EPAD obowiązkowo do masy** — symbol nie ma pinu EPAD, połączenie wykonuje się ręcznie w PCB (5.3.5) |

### 3.2 Reguły przydziału

1. **Wszystkie banki VCCIO = 3,3 V.** LVDS25 (TLVDS) działa przy VCCIO 2,5/3,3 V jako wejście i wyjście (DS100, tab. 2-1, 2-2).
2. **TD wyłącznie na parze z wyjściem true LVDS** (kolumna „LVDS” = TRUE w UG114). Umieszczenie `TLVDS_OBUF` na parze bez tej cechy (np. 45/44, 39/38) kończy się błędem CT1005.
3. **RD na dowolnej parze różnicowej** — wejście `TLVDS_IBUF` obsługują wszystkie banki. Atrybut `DIFF_RESISTOR` jest akceptowany wyłącznie w banku 0 (poza nim błąd CT1118, także przy wartości `OFF`); po przeniesieniu RD poza bank 0 atrybut należy usunąć.
4. **IDES8/OSER8:** HCLK z PLL obejmuje wszystkie banki (PnR: `BANK0_BANK1_HCLK0`, `BANK2_BANK3_HCLK0`); w GW1N-9 nie ma pinów bez IO logic.
5. **`XSPI_SCLK` na pinie GCLKT.** SCLK do 40 MHz nie da się nadpróbkować zegarem `clk_sys`, więc taktuje on bezpośrednio stronę hosta. Pin GCLKC tej samej pary pozostaje zwykłym I/O.
6. **Magistrala xSPI w jednym banku** (bank 2, dolna krawędź) z krótkimi i równymi ścieżkami.
7. **`CLK_25M` na dedykowanym wejściu PLL.** Wejście przez sieć globalną (pin GCLKT) działa, ale dodaje jitter na wejściu PLL.
8. **Piny MSPI (31–34)** pracują jako GPIO dzięki opcji `-use_mspi_as_gpio 1`; wymaga to trybu AUTOBOOT (pin 48 do masy).
9. **Polaryzacja par LVDS może być odwrócona na płytce**, jeśli upraszcza to prowadzenie pary (bez skrzyżowania i bez przelotek). Pin A pary (true) jest zawsze wejściem `I` bufora `TLVDS_IBUF` lub wyjściem `O` bufora `TLVDS_OBUF`; port VHDL przypisany do tego pinu w `.cst` (`IO_LOC "<port>" A,B`) nosi nazwę sieci, która jest do niego podłączona. Odwrócenie kompensuje generyk `INVERT` modułu `rx_phy` / `tx_phy`. Stan w rev. A: **RD odwrócona** (`SFP_RD_N` na pinie A 43, `SFP_RD_P` na pinie B 42, `rx_phy` z `INVERT => true`), **TD bez zmian** (`SFP_TD_P` na pinie A 34).

### 3.3 Alternatywy przydziału

Warianty na wypadek trudności w schemacie lub prowadzeniu ścieżek. Wariant oznaczony „PnR OK” przeszedł syntezę, PnR i generację bitstreamu przy pozostałych pinach bez zmian, o ile w kolumnie warunków nie podano inaczej.

| Sygnał | Podstawowy | Alternatywa | Warunki / koszt | Weryfikacja |
|---|---|---|---|---|
| `SFP_TD_P/N` | 34/33 | **28/27** (IOR24) | prawa krawędź niżej, dalej od SFP | PnR OK |
| | | **30/29** (IOR17) | zajmuje GCLKT_3 | PnR OK |
| | | **11/10** (IOL15) | lewa krawędź; `HOST_RST_N` → np. 28; zajmuje GCLKT_6 | PnR OK |
| | | 13–24 (bank 2) | pary TRUE, ale kolidują z magistralą xSPI | nie zalecane |
| `SFP_RD_N/P` (odwrócona, reguła 9) | 43/42 | **45/44** (IOT22, bank 0) | zachowuje opcję terminacji wewnętrznej | PnR OK (z `DIFF_RESISTOR=ON`) |
| | | **39/38** (IOT42, bank 1) | najbliżej narożnika SFP; tylko terminacja zewnętrzna; `SFP_TX_DIS`/`SFP_TX_FAULT` → 44/45 | PnR OK |
| | | **41/40** (IOT37, bank 1) | tylko terminacja zewnętrzna; `SFP_LOS`/`SFP_MOD_ABS` → 44/45 | PnR OK |
| | | **28/27**, **30/29** (bank 1) | tylko terminacja zewnętrzna | PnR OK |
| `CLK_25M` | 35 | **30** (GCLKT_3) lub **10** (GCLKT_6) | wejście PLL przez sieć globalną, większy jitter | PnR OK (30) |
| | | 3 (LPLL_T_in) | koliduje z `JTAGSEL_N` | nie zalecane |
| `XSPI_SCLK` | 19 | **10** (GCLKT_6) lub **30** (GCLKT_3) | 19 staje się zwykłym I/O banku 2 | PnR OK (oba) |
| `XSPI_IO0..7`, `XSPI_CS_N`, `XSPI_DQS`, `HOST_IRQ_N` | 13–18, 20–24 | **dowolna permutacja** w obrębie 13–24 (poza pinem SCLK) | kolejność bitów ustala `.cst`; logika bez zmian | — |
| Wolne sygnały SFP, LED, `HOST_RST_N` | jak w 3.1 | dowolny pin zapasowy: 10, 27–30, 44, 45 | `OPEN_DRAIN=ON` dla SCL/SDA działa na każdym pinie | — |

Jako alternatyw **nie** wolno użyć pinów 3–9 i 48 (konfiguracja) ani 1, 2, 12, 25, 26, 36, 37 (zasilanie).

---

## 4. Zegary i PLL

```
CLK_25M (25 MHz, ±25 ppm, CMOS 3,3 V)
   └─> rPLL: IDIV=1, FBDIV=8, ODIV=4  → VCO = 800 MHz, CLKOUT = 200 MHz  (clk_fast, HCLK)
          └─> CLKDIV (DIV_MODE="4")   → 50 MHz                            (clk_sys)
```

- 200 MHz FCLK × DDR daje **400 Msps**, czyli dokładnie **4× nadpróbkowanie przy 100 Mbaud**. IDES8 oddaje 8 próbek (2 bity) co takt `clk_sys` (50 MHz) — [ADR 0007](adr/0007-zegar-systemowy-50mhz.md).
- VCO 800 MHz mieści się w zakresie 400–1200 MHz (GW1N-9 C6/I5).
- `CLKDIV` zamiast drugiego wyjścia PLL, żeby `clk_sys` był fazowo powiązany z FCLK gearboxa (wymagane przez IDES/OSER).
- Oba końce łącza pracują na niezależnych generatorach. Różnicę ppm absorbuje sam CDR z nadpróbkowaniem (wydaje 1, 2 lub 3 bity na takt, nominalnie 2), więc **bufor elastyczny nie jest potrzebny**.
- Rozszerzenie do 125 Mbaud: `clk_fast` = 250 MHz, `clk_sys` = 62,5 MHz (VCO 1000 MHz, w zakresie GW1N-9 do 1200 MHz). Prędkość linii jest parametrem pakietu `bridge_pkg` (`LINE_BAUD`), z którego wynikają nastawy PLL.

---

## 5. Warstwa fizyczna (PCB)

### 5.1 SFP

Moduł i złącze zgodne z SFP MSA (INF-8074i). SFF-8431 opisuje elektrykę SFP+ (10 Gb/s) i nie jest podstawą tego projektu. Klatka i złącze 20-pinowe są wspólne dla SFP i SFP+.

**Klasa modułów.** Obsługiwane są moduły SFP bez wewnętrznego CDR: 100BASE-FX / OC-3 (125–155 Mb/s, zakres zgodny z linią 100–125 Mbaud) oraz 1000BASE-X (1,25 Gb/s). Moduły SFP+ (10G) nie są obsługiwane: zwykle zawierają CDR zablokowany na ok. 10 Gbaud i nie są specyfikowane dla 100 Mbaud.

Przyporządkowanie pinów złącza (INF-8074i, Table 1; numeracja zgodna z symbolem `Connector_SFP_and_Cage`):

| Pin SFP | Nazwa (INF-8074i) | Sieć / FPGA | Połączenie |
|---|---|---|---|
| 1, 17, 20 | VeeT | GND | masa nadajnika |
| 2 | TX Fault | `SFP_TX_FAULT` → pin 39 | wyjście OC/OD modułu; w rev. A wewnętrzny pull-up FPGA (`PULL_MODE=UP`), INF-8074i zaleca 4,7–10 kΩ |
| 3 | TX Disable | `SFP_TX_DIS` ← pin 38 | wejście modułu z wewnętrznym pull-upem 4,7–10 kΩ (stan wysoki lub rozwarty = laser wyłączony); pull-up 4,7 kΩ na płytce (R17) utrzymuje laser wyłączony także w czasie konfiguracji FPGA |
| 4 | MOD-DEF2 | `SFP_SDA` ↔ pin 47 | SDA interfejsu 2-wire (EEPROM A0h, DDM A2h); pull-up 4,7–10 kΩ |
| 5 | MOD-DEF1 | `SFP_SCL` ← pin 46 | SCL, maks. 100 kHz; pull-up 4,7–10 kΩ |
| 6 | MOD-DEF0 | `SFP_MOD_ABS` → pin 41 | zwarte do masy w module = moduł obecny; pull-up jak TX Fault |
| 7 | Rate Select | — | **jeden pin**; opcjonalne wejście modułu z wewnętrznym pull-downem > 30 kΩ (niski lub rozwarty = pasmo zmniejszone, wysoki = pełne); 10 kΩ do masy. W SFP+ ten pin nazywa się RS0 |
| 8 | LOS | `SFP_LOS` → pin 40 | wyjście OC/OD modułu; pull-up jak TX Fault |
| 9, 10, 11, 14 | VeeR | GND | masa odbiornika. W SFP+ pin 9 to wejście RS1 — połączenie z masą jest dla modułu SFP+ stanem niskim, więc pozostaje poprawne |
| 12 | RD− | → `SFP_RD_N` (pin 43) | połączenie bezpośrednie; terminacja i bias przy FPGA (5.2) |
| 13 | RD+ | → `SFP_RD_P` (pin 42) | jw.; polaryzacja odwrócona względem pinów A/B pary (3.2, reguła 9) |
| 15 | VccR | 3,3 V przez filtr | filtr odbiornika (poniżej) |
| 16 | VccT | 3,3 V przez filtr | filtr nadajnika (poniżej) |
| 18 | TD+ | ← `SFP_TD_P` (pin 34) | połączenie bezpośrednie |
| 19 | TD− | ← `SFP_TD_N` (pin 33) | jw. |
| — | klatka (cage) | masa obudowy | zgodnie z wytycznymi producenta klatki |

Napięcia pull-upów sygnałów sterujących: 2,0 V … VccT/VccR + 0,3 V; przy zasilaniu 3,3 V pull-upy do szyny 3,3 V spełniają wymaganie.

**Sprzężenie AC.** Sprzężenie AC jest realizowane wewnątrz modułu na TD± i RD±, a kondensatory na płytce hosta nie są wymagane (INF-8074i, Table 1, uwagi 7 i 9). Pary TD i RD łączą się z FPGA bezpośrednio. Ponieważ wyjście RD± modułu jest odcięte stałoprądowo, napięcie wspólne po stronie FPGA ustala dzielnik Vbias (5.2); bez niego wejście LVDS nie ma określonego punktu pracy. Wyjście TD FPGA (VOS ok. 1,2 V) podaje się wprost na wewnętrzne kondensatory modułu.

**Filtr zasilania** (INF-8074i, Figure 2A):

```
                  ┌──[1 µH]──┬──────────── VccT (16)
                  │        0,1 µF
3,3 V ──┬──────┬──┤
      10 µF  0,1 µF
                  └──[1 µH]──┬───────┬──── VccR (15)
                           0,1 µF  10 µF
```

- Dławiki 1 µH, DCR < 1 Ω (spadek napięcia przy 300 mA), prąd znamionowy ≥ 0,5 A.
- Kondensatory 0,1 µF przy pinach VccT i VccR; 10 µF na gałęzi VccR; 10 µF + 0,1 µF po stronie szyny 3,3 V.
- Przy tym filtrze prąd udarowy przy wpięciu modułu na gorąco nie przekracza prądu ustalonego o więcej niż 30 mA. Maksymalny prąd modułu: 300 mA.

**Poziomy sygnałów:**

- TX: GW1N-9 daje VOD 250–450 mV, czyli **500–900 mVppd**. Wejście TD± modułu przyjmuje 500–2400 mVppd, zalecane 500–1200 mVppd (INF-8074i, uwaga 9). Margines przy dolnej granicy jest minimalny, dlatego obowiązuje **DRIVE=3.5** (maksymalny prąd wyjścia LVDS25). Wymaganie minimalnej amplitudy wybranego modułu **[DO WERYFIKACJI]** w jego datasheecie.
- RX: wyjście RD± modułu 370–2000 mVppd przy terminacji 100 Ω (INF-8074i, uwaga 7). VTHD FPGA ±100 mV daje duży zapas. Bias ok. 1,2 V mieści się w VCM 0,05–2,1 V.

### 5.2 Terminacja i bias toru RX

Wariant podstawowy: **terminacja zewnętrzna** ([ADR 0002](adr/0002-terminacja-rx-zewnetrzna.md)).

```
RD+ (SFP 13) ───┬──────────────── FPGA RD_P (pin 42, IOT32B)
              R9 49,9 Ω 1% 0402
                ├── Vbias 1,2 V (R11 2,1 kΩ z 3,3 V / R12 1,2 kΩ do masy, C6 100 nF do masy)
              R10 49,9 Ω 1% 0402
RD− (SFP 12) ───┴──────────────── FPGA RD_N (pin 43, IOT32A)
```

- R9 i R10 umieszcza się bezpośrednio przy pinach 42/43 (odcinek do odbiornika ≤ 2 mm). C6 w węźle Vbias zwiera do masy zakłócenia wspólne.
- Sprzężenie AC jest wewnątrz modułu, więc linie RD± nie mają po stronie płytki określonego napięcia stałego; dzielnik Vbias jest wymagany niezależnie od wariantu terminacji.
- Wariant awaryjny: w miejsce R9/R10 montuje się 10 kΩ (te same footprinty 0402), w `.cst` `DIFF_RESISTOR=ON` (tylko bank 0). Dodatkowe footprinty nie są potrzebne.
- Obie terminacje jednocześnie (49,9 Ω i `DIFF_RESISTOR=ON`) dają ok. 50 Ω i są niedopuszczalne; domyślnie `DIFF_RESISTOR=OFF`.

### 5.3 Płytka drukowana: stackup, reguły i prowadzenie ścieżek

#### 5.3.1 Technologia (JLCPCB, najniższy próg cenowy 4 warstw)

| Parametr | Wartość |
|---|---|
| Liczba warstw / grubość | 4 / 1,6 mm |
| Stackup | **JLC04161H-7628** |
| Miedź zewnętrzna / wewnętrzna | 1 oz (35 µm) / 0,5 oz (15,2 µm) |
| Wykończenie | HASL (bezołowiowy lub ołowiowy) — bez ENIG |
| Przelotki | „Min via hole size/diameter: **0,3 mm / (0,4/0,45 mm)**” (opcja domyślna, bez dopłaty); pokrycie: tented |
| Via-in-pad | bez wypełniania i zaślepiania (bez opcji „Epoxy Filled & Capped”) |
| Kontrola impedancji | nie zamawia się; geometrię wyznacza się obliczeniowo (5.3.3), tolerancja ±10–15% jest bez znaczenia przy 100 Mbaud |

#### 5.3.2 Stackup do wpisania w KiCad

`Board Setup → Board Stackup → Physical Stackup` (warstwy miedzi: 4, grubość płytki 1,6 mm):

| Warstwa | Materiał | Grubość | εr | Przeznaczenie |
|---|---|---|---|---|
| F.Mask | soldermaska | 0,010 mm | 3,8 | |
| **F.Cu (L1)** | miedź 1 oz | 0,035 mm | — | sygnały, **pary LVDS**, elementy |
| Dielectric 1 | prepreg 7628 | 0,2104 mm | 4,4 | |
| **In1.Cu (L2)** | miedź 0,5 oz | 0,0152 mm | — | **GND — płaszczyzna ciągła, bez podziałów** |
| Dielectric 2 | rdzeń FR-4 | 1,065 mm | 4,6 | |
| **In2.Cu (L3)** | miedź 0,5 oz | 0,0152 mm | — | 3V3 — płaszczyzna |
| Dielectric 3 | prepreg 7628 | 0,2104 mm | 4,4 | |
| **B.Cu (L4)** | miedź 1 oz | 0,035 mm | — | sygnały wolne, wylewka GND |
| B.Mask | soldermaska | 0,010 mm | 3,8 | |

Wartości grubości i εr należy potwierdzić w kalkulatorze impedancji JLCPCB dla JLC04161H-7628 przed zamówieniem **[DO WERYFIKACJI]**.

#### 5.3.3 Geometria linii (L1 nad L2 GND)

Obliczenia: solver 2D równania Laplace'a (metoda różnic skończonych), przekrój prostokątny, soldermaska 10–15 µm, εr = 4,4, h = 0,2104 mm, t = 35 µm. Kontrola: linia 50 Ω wychodzi przy szerokości ok. 0,36 mm, zgodnie z danymi publikowanymi dla tego stackupu.

| Linia | Szerokość | Odstęp w parze | Impedancja |
|---|---|---|---|
| **LVDS TD±, RD± — podstawowa** | **0,22 mm** | **0,20 mm** | **ok. 101 Ω różnicowo** |
| LVDS — zwężenie przy U1 (raster 0,4 mm) i J1 | 0,20 mm | 0,20 mm | ok. 105 Ω, odcinek ≤ 1–2 mm |
| sygnał pojedynczy 0,20 mm (xSPI, zegar, sterowanie) | 0,20 mm | — | ok. 66 Ω (niekontrolowana) |
| sygnał pojedynczy 50 Ω (tylko dla odniesienia) | 0,36 mm | — | ok. 50 Ω |

Wrażliwość: zmiana odstępu o ±0,05 mm zmienia impedancję różnicową o ok. ±7 Ω; zmiana szerokości o ±0,02 mm — o ok. ∓3,5 Ω.

#### 5.3.4 Ustawienia w KiCad

**Board Setup → Design Rules → Constraints** (zgodne z JLCPCB, z zapasem):

| Parametr | Wartość |
|---|---|
| Minimalna szerokość ścieżki | 0,20 mm (technologicznie 0,09 mm; 0,20 mm wystarcza wszędzie) |
| Minimalny odstęp (clearance) | 0,20 mm (pady QN48: 0,2 mm przy rastrze 0,4 mm) |
| Minimalny otwór (PTH i przelotka) | **0,30 mm** |
| Minimalna średnica przelotki | 0,45 mm (zalecane 0,6 mm) |
| Minimalny pierścień przelotki | 0,10 mm (0,6/0,3 → 0,15 mm) |
| Odstęp miedzi od krawędzi | 0,5 mm (JLCPCB min. 0,2–0,3 mm) |
| Otwór–otwór | 0,25 mm |
| Soldermaska: poszerzenie / minimalny mostek | 0,05 mm / 0,10 mm |
| Nadruk: grubość linii / wysokość tekstu | ≥ 0,15 mm / ≥ 1,0 mm |

**Board Setup → Net Classes:**

| Klasa | Ścieżka | Clearance | Przelotka | Para różnicowa (szer./odstęp) | Przypisanie sieci |
|---|---|---|---|---|---|
| Default | 0,20 mm | 0,20 mm | 0,6 / 0,3 mm | — | wszystkie pozostałe |
| LVDS | 0,22 mm | 0,20 mm | 0,6 / 0,3 mm (nieużywane) | **0,22 / 0,20 mm** | `/SFP/SFP_TD_*`, `/SFP/SFP_RD_*` |
| PWR | 0,50 mm | 0,20 mm | 0,6 / 0,3 mm | — | `+3V3`, `Net-(J1-VccT)`, `Net-(J1-VccR)` |

**Board Setup → Pre-defined Sizes:** ścieżki 0,20 / 0,22 / 0,30 / 0,50 / 0,80 mm; przelotki 0,6/0,3 i 0,45/0,3 mm; para różnicowa 0,22/0,20 mm.

**Reguły dodatkowe:** plik `pcb/SFP_xSPI_Bridge.kicad_dru`, wczytywany automatycznie obok `.kicad_pcb` (podgląd i edycja: `Board Setup → Design Rules → Custom Rules`). Zawiera:

- przelotki: otwór ≥ 0,3 mm, średnica ≥ 0,45 mm (próg bez dopłaty JLCPCB),
- pary LVDS: szerokość 0,20–0,24 mm (opt. 0,22), odstęp 0,18–0,22 mm (opt. 0,20), odcinek niesprzężony ≤ 2 mm, różnica długości w parze ≤ 0,5 mm, **zakaz przelotek**,
- odstęp par LVDS od innych ścieżek, przelotek i wylewek ≥ 0,5 mm (wylewka GND bliżej pary obniża jej impedancję przez sprzężenie z masą w tej samej warstwie),
- zwężenie przy U1 i J1 (w obrębie courtyardu): szerokość 0,20 mm, odstęp do 0,60 mm.

#### 5.3.5 Zasady prowadzenia

**Pary LVDS (TD: U1 33/34 ↔ J1 19/18; RD: U1 42/43 ↔ J1 12/13):**

- W całości na L1, nad ciągłą płaszczyzną GND na L2; bez przelotek, bez przejść nad krawędzią lub przerwą w L2.
- Router par różnicowych KiCad (`6` lub `Route → Differential Pair`) rozpoznaje pary po sufiksach `_P`/`_N`.
- Dopasowanie długości w parze ≤ 0,5 mm; między parami TD i RD dopasowanie nie jest wymagane. Skew w parze przy 100 Mbaud (UI = 10 ns) jest pomijalny; reguła utrzymuje symetrię dla tłumienia zakłóceń wspólnych.
- Zakręty 45° lub łukowe; meandry wyrównujące przy końcu z krótszą linią.
- Odstęp od innych sygnałów ≥ 0,5 mm (≈ 2× szerokość pary); generator Y1 i linia `CLK_25M` jak najdalej od par.
- Terminacja RX (R9, R10) i węzeł Vbias (R11, R12, C6) bezpośrednio przy pinach 42/43.
- Para TD wychodzi z pinów 33/34 na prawej krawędzi U1, para RD z pinów 42/43 na górnej — obie w stronę klatki SFP przy prawym górnym narożniku U1.

**Magistrala xSPI (U1 13–24 ↔ J3):**

- Ścieżki 0,20 mm na L1 i/lub L4 (L4 odnosi się do płaszczyzny 3V3 — dopuszczalne dzięki odsprzęganiu).
- Wyrównanie długości ±5 mm względem `XSPI_SCLK`; przy 40 MHz i ścieżkach < 50 mm impedancja nie jest kontrolowana.
- Przelotki przy zmianie warstwy uzupełnia się przelotką GND w pobliżu (ścieżka powrotna).

**Zasilanie i odsprzęganie:**

- 3V3 rozprowadza płaszczyzna L3; od złącza J3 do płaszczyzny ścieżka ≥ 0,8 mm lub wylewka, TVS D1 przy złączu.
- Kondensatory 100 nF (C1–C5) przy pinach zasilania U1 (1, 12, 25, 36, 37), każdy z własną przelotką do L2/L3, odległość ≤ 2 mm.
- Filtry SFP (L1/C7 dla VccT, L2/C8/C9 dla VccR, C10–C12 po stronie 3V3) przy klatce J1; dławiki 0805 nieekranowane — kilka mm od par LVDS.
- Generator Y1: 100 nF przy pinie 4, wyjście `CLK_25M` krótkie do pinu 35.

**EPAD U1 (pad 49):**

- Symbol `GW1N-6&9_QN48` z biblioteki lokalnej nie ma pinu EPAD — **pad 49 musi zostać ręcznie połączony z GND** (UG114: „Exposed pad. Connect to ground.”).
- Footprint bez przelotek w padzie (`QFN-48-1EP_6x6mm_P0.4mm_EP4.2x4.2mm`); przelotki 0,3/0,5 mm dodane ręcznie w polu EPAD do L2 GND (w rev. A: 16). Wariant `…_ThermalVias` ma przelotki Ø 0,2 mm, wymagające płatnej opcji JLCPCB.
- Przelotki w padzie bez wypełnienia odprowadzają część lutu; otwór pasty w EPAD dzieli się na 4–9 okien (pokrycie ok. 50–60%). Moc rozpraszana przez FPGA (< 0,5 W) nie wymaga więcej przelotek.

**Pozostałe:**

- Wylewki GND na L1 i L4 zszywane przelotkami GND co ok. 5 mm, szczególnie wzdłuż par LVDS i krawędzi płytki.
- Klatka SFP: otwory wg rysunku producenta wybranej klatki (press-fit), sprawdzić zgodność footprintu `Connector_SFP_and_Cage` z konkretnym numerem katalogowym klatki **[DO WERYFIKACJI]**.
- Zworka lutowana `MODE_SEL`: pin 10 FPGA ↔ GND, pull-up 10 kΩ do 3,3 V ([ADR 0006](adr/0006-tryb-uart-przezroczysty.md)).

### 5.4 Zasilanie

| Odbiornik | Prąd (szac.) |
|---|---|
| Moduł SFP | do 300 mA (INF-8074i) |
| GW1N-UV9 (VCC=VCCX=VCCIO=3,3 V) | ok. 50–100 mA |
| Generator, LED, reszta | ok. 10 mA |
| **Razem** | **ok. 0,45 A → projektować na 0,6–0,8 A** |

- Wejście: J3 piny 1–2 (3V3), TVS D1 SMF3.3A (katoda do 3V3) przy złączu. Bez PTC i koralika — każdy element szeregowy zmniejsza margines napięcia modułu SFP (min. 3,135 V na pinie VccT/VccR).
- Odsprzęganie: 5 × 100 nF przy pinach zasilania FPGA, 7 × 10 µF ceramicznych na szynie 3V3 (ok. 70 µF łącznie), filtry SFP wg 5.1.
- TVS ogranicza ESD i szpilki; nie chroni przed stałym przepięciem (np. 5 V na pinie 3V3) — maksymalne napięcie GW1N-UV to 3,75 V (DS100, tab. 3-1).

### 5.5 Złącze hosta J3 (2 × 10, raster 1,27 mm)

| Pin | Sygnał | Pin | Sygnał |
|---|---|---|---|
| 1 | 3V3 | 2 | 3V3 |
| 3 | GND | 4 | XSPI_SCLK |
| 5 | GND | 6 | XSPI_CS_N |
| 7 | XSPI_IO0 | 8 | XSPI_IO1 |
| 9 | XSPI_IO2 | 10 | XSPI_IO3 |
| 11 | XSPI_IO4 | 12 | XSPI_IO5 |
| 13 | XSPI_IO6 | 14 | XSPI_IO7 |
| 15 | GND | 16 | XSPI_DQS |
| 17 | HOST_IRQ_N | 18 | HOST_RST_N |
| 19 | GND | 20 | GND |

- W trybie UART ([ADR 0006](adr/0006-tryb-uart-przezroczysty.md)) piny 7–10 pełnią funkcje: 7 `UART_RX` (wejście), 8 `UART_TX` (wyjście), 9 `UART_RTS_N` (wyjście, opcja), 10 `UART_CTS_N` (wejście, opcja); zasilanie i masa bez zmian.
- Footprint `PinHeader_2x10_P1.27mm_Vertical` nie ma klucza. Odwrócona wtyczka łączy 3V3 hosta z GND (piny 19/20) — zaleca się złącze z obudową i kluczem (box header 1,27 mm) albo wyraźne oznaczenie pinu 1 na nadruku.
- Rezystory szeregowe na liniach xSPI nie są przewidziane; ewentualne dzwonienie ogranicza się ustawieniem `DRIVE` wyjść FPGA (4/8 mA) i prędkości GPIO po stronie STM32.

### 5.6 Złącze programowania (Tag-Connect TC2050)

Footprint `Tag-Connect_TC2050-IDC-NL_2x05_P1.27mm_Vertical` (J2). Układ zgodny ze złączem ARM Cortex Debug 10-pin, z wykorzystaniem pinu 7 (w standardzie Cortex: klucz, niepodłączony) na sygnał AUX programatora.

| Pin TC2050 | Sygnał | Połączenie w FPGA |
|---|---|---|
| 1 | 3V3 (VTref) | szyna 3,3 V |
| 2 | TMS | pin 4 |
| 3 | GND | |
| 4 | TCK | pin 5; pull-down 4,7 kΩ (UG290, tab. 7-3, uwaga 2) |
| 5 | GND | |
| 6 | TDO | pin 7 |
| 7 | AUX | przez 1 kΩ (R7) na zworkę trójpozycyjną JP2: `JTAGSEL_N` (pin 3) lub `DONE` (pin 9) |
| 8 | TDI | pin 6 |
| 9 | GND (GNDDetect) | |
| 10 | nRESET | przez zworkę JP1 (domyślnie rozwartą) na `RECONFIG_N` (pin 8) |

- **nRESET → `RECONFIG_N`** przeładowuje konfigurację z Flash. `RECONFIG_N` nie może przyjąć stanu niskiego w czasie programowania Flash ani ładowania AUTOBOOT (UG290, rozdz. 7 — ryzyko trwałego uszkodzenia Flash), dlatego połączenie jest domyślnie rozwarte (JP1) i zamykane tylko dla programatora sterującego resetem wyłącznie na żądanie.
- **AUX → `JTAGSEL_N`** przywraca funkcję JTAG pinów 4–7, gdyby bitstream przełączył je na GPIO (działa przy MODE ≠ `001`). **AUX → `DONE`** pozwala programatorowi odczytać stan konfiguracji. Rezystor 1 kΩ chroni oba układy przy różnych stanach zasilania.
- Do samego programowania (SRAM i Flash) wystarczają TCK, TMS, TDI, TDO; przeładowanie po zapisie Flash odbywa się instrukcją JTAG.
- Poziomy logiczne programatora: 3,3 V (bank 3, VCCIO3 = 3,3 V).

### 5.7 Lista elementów (BOM, główne pozycje)

| Ozn. | Pozycja | Źródło / numer | Uwagi |
|---|---|---|---|
| U1 | GW1N-UV9QN48C6/I5 | Mouser | jedyny dystrybutor; dostępność sprawdzić przed zamówieniem |
| J1 | klatka SFP + złącze 20-pin | — | press-fit lub SMT; dopasować do footprintu |
| Y1 | generator 25 MHz CMOS, ±20 ppm, 3225 | LCSC C669088 (YXC OT322525MJBA4SL) | alternatywnie 7050: C669095 |
| L1, L2 | dławik 1 µH, drutowy 0805 | TME Viking NL05KTC1R0 | DCR 0,169 Ω, 1,1 A wg TME (prąd do potwierdzenia w datasheecie) |
| D1 | TVS SMF3.3A, SOD-123FL | LCSC C283866 / C37331473 / C5197392 | VRWM 3,3 V |
| D2 | LED żółtozielona 575 nm, 0603 | LCSC C965805 (XL-1608SYGC-06) | LINK |
| D3 | LED pomarańczowa 601 nm, 0603 | LCSC C965800 (XL-1608UOC-06) | ACT |
| R9, R10 | 49,9 Ω 1%, 0402 | — | terminacja RX |
| R11, R12 | 2,1 kΩ / 1,2 kΩ, 0603 | — | Vbias 1,2 V |
| R14, R15 | 1 kΩ, 0603 | — | LED, ok. 1,4 mA |
| R2 | 1 kΩ, 0603 | — | MODE → AUTOBOOT |
| R13 | 4,7 kΩ, 0603 | — | pull-down TCK |
| J3 | złącze 2 × 10, 1,27 mm | — | preferowane z kluczem |
| J2 | Tag-Connect TC2050-IDC-NL | footprint, bez elementu | kabel TC2050 po stronie programatora |
| JP1, JP2 | zworki lutowane 2- i 3-pozycyjna | — | nRESET → `RECONFIG_N`; AUX → `JTAGSEL_N` / `DONE` (5.6) |
| JP3 | zworka lutowana 2-pozycyjna | — | `MODE_SEL` (pin 10) ↔ GND: zwarta = tryb UART ([ADR 0006](adr/0006-tryb-uart-przezroczysty.md)) |
| R16 | 10 kΩ, 0603 | — | pull-up `MODE_SEL` do 3,3 V |
| R17 | 4,7 kΩ, 0603 | — | pull-up `SFP_TX_DIS` do 3,3 V (laser wyłączony w czasie konfiguracji FPGA) |

---

## 6. Konfiguracja FPGA (Gowin EDA)

| Ustawienie | Wartość |
|---|---|
| Urządzenie | GW1N-UV9QN48C6/I5 (Device: GW1N-9C, `set_device GW1N-UV9QN48C6/I5 -device_version C`) |
| Język | VHDL-2008 (synteza GowinSynthesis); prymitywy Gowin z biblioteki dostarczanej z Gowin EDA |
| Tryb konfiguracji | **AUTOBOOT** z wewnętrznego Flash; programowanie przez JTAG (Gowin Programmer lub openFPGALoader) |
| Dual-purpose pins | JTAG, JTAGSEL_N, RECONFIG_N, DONE, MODE: dedykowane; MSPI jako GPIO (`-use_mspi_as_gpio 1`) |
| Background upgrade | aktualizacja Flash przez JTAG bez przerywania pracy, aktywacja przez `RECONFIG_N` **[DO WERYFIKACJI w UG290 dla GW1N-9C]** |
| Bitstream | kompresja wł., security bit wg potrzeb |
| Constraints (.cst) | IO_TYPE: `LVDS25` dla par TD/RD, `LVCMOS33` dla reszty; DRIVE=3.5 dla TD; DIFF_RESISTOR=OFF dla RD (terminacja zewnętrzna); PULL_MODE=UP dla CS_N, RST_N; OPEN_DRAIN=ON dla SCL/SDA |
| Timing (.sdc) | `create_clock` 25 MHz (`CLK_25M`) i 40 MHz (`XSPI_SCLK`); zegary generowane: `clk_fast` (rPLL ×8), `clk_sys` (CLKDIV ÷4), `clk_host` (wyjście DCS); grupy asynchroniczne {`clk_spi`, `clk_host`} i {`clk_25m`, `clk_fast`, `clk_sys`}; opóźnienia wejść i wyjść xSPI względem zbocza opadającego SCLK ([integracja](vhdl/top.md#ograniczenia-czasowe)) |

Ograniczenia: `vhdl/constraints/sfp_bridge.cst` (piny, standardy I/O) i `vhdl/constraints/sfp_bridge.sdc` (zegary, opóźnienia).

Składnia atrybutów `DRIVE=3.5` (LVDS25) i `DIFF_RESISTOR=ON` jest potwierdzona syntezą i PnR w Gowin EDA 1.9.11.03.

---

## 7. Projekt FPGA (VHDL)

### 7.1 Struktura katalogów

Moduły, testbenche i wyniki syntezy: [projekt FPGA](vhdl/index.md).

```
vhdl/
  constraints/
    sfp_bridge.cst            -- piny, standardy I/O (wspólne dla projektów)
    sfp_bridge.sdc            -- zegary
  sfp_bridge/                 -- projekt Gowin EDA (sfp_bridge.gprj, build.tcl)
  sfp_bridge/src/
    pkg/
      bridge_pkg.vhd          -- stałe: zegary, kody K, identyfikacja
      code8b10b_pkg.vhd       -- tablice i funkcja kodu 8b/10b (jedno źródło dla kodera i dekodera)
    common/
      sync_bit.vhd            -- synchronizator bitu
      reset_sync.vhd          -- mostek resetu domeny (ADR 0004)
    top/
      sfp_bridge_top.vhd
    clk/
      clk_rst.vhd             -- rPLL + CLKDIV + mostki resetu domen
      host_clk.vhd            -- DCS: zegar strony hosta (SCLK / clk_sys)
    host/
      xspi_slave.vhd          -- SPI/QSPI/OCTOSPI slave, dekoder komend
      csr_regs.vhd            -- rejestry kontrolne/statusowe, IRQ
      frame_echo.vhd          -- echo ramek (pętla far-end)
    fifo/
      async_fifo.vhd          -- FIFO na BSRAM semi-dual port, Gray + handshake, commit/abort
    link/
      crc32.vhd               -- CRC-32 (bajtowo)
      enc_8b10b.vhd, dec_8b10b.vhd
      tx_framer.vhd           -- ramki, bezczynność /I/ /P/ /R/ (XON/XOFF, odbiornik niegotowy)
      rx_deframer.vhd         -- kontrola ramek, odrzucanie błędnych, XOFF
      tx_gearbox.vhd          -- symbol 10 bitów → 2 bity na takt, char_en co 5 taktów
      tx_phy.vhd              -- OSER8 (bity powielone 4×) + TLVDS_OBUF
      rx_phy.vhd              -- TLVDS_IBUF + IDES8
      cdr_os4x8.vhd           -- odzysk danych z 4× nadpróbkowania, 8 próbek na takt
      comma_align.vhd         -- wyrównanie do K28.5
      link_ctrl.vhd           -- stan łącza, LOS, liczniki błędów, pętle zwrotne
    uart/
      uart_rx.vhd, uart_tx.vhd
      uart_bridge.vhd         -- pakietyzacja ramek TYPE 0x01, RTS/CTS (ADR 0006)
    mgmt/
      i2c_master.vhd
      sfp_mgmt.vhd            -- skrzynka I2C, odczyt DDM, sygnały SFP
      leds.vhd
  sim/
    tb/                       -- tb_pkg, testbenche tb_<moduł>.vhd (24), e2e_bench
                              --   (testy end-to-end dwóch mostków)
    waves/                    -- widoki GTKWave (.gtkw)
    sources.txt               -- kolejność kompilacji
    run_tests.ps1 / .sh       -- uruchamianie testów (GHDL w WSL)
    view.ps1                  -- podgląd przebiegu
```

### 7.2 Moduły

**`clk_rst`** — [opis](vhdl/clk_rst.md)
- `rPLL` (25 → 200 MHz), `CLKDIV` (/4 → 50 MHz); parametry PLL wyliczane z `LINE_BAUD` w `bridge_pkg`.
- Reset globalny trzymany do `LOCK` PLL; `HOST_RST_N` z filtrem zakłóceń 640 ns; `CTRL.SOFT_RST` kończący się samoczynnie. Reset domeny `clk_sys` przez `reset_sync`; `rst_hard` bez resetu programowego (`MODE_CTRL`, `UART_DIV`), `rst_por` tylko od blokady PLL (`UART_STATUS`); żądanie `arst_n` dla mostka resetu domeny `clk_spi` (reset asynchroniczny, zwalnianie synchroniczne).

**`xspi_slave`** — [opis](vhdl/xspi_slave.md) (domena `clk_host` = SCLK w trybie xSPI, piny zatrzaskiwane na zboczu narastającym, logika na opadającym, CS_N jako asynchroniczny reset maszyny stanów; [ADR 0009](adr/0009-interfejs-hosta.md))
- Fazy: instrukcja (zawsze 1 linia) → opcjonalny adres → dummy → dane, szerokość fazy danych wynika z opkodu (tabela 7.3).
- Próbkowanie na zboczu narastającym SCLK, wystawianie na opadającym (tryb 0).
- Kierunek IO0..7 przełączany po fazie dummy przy odczycie.
- Interfejs do FIFO: zapis bajtów do TX FIFO / odczyt z RX FIFO bez udziału `clk_sys`. Rejestry CSR: zatrzask w domenie `clk_sys` przy opadnięciu CS, odczyt multiplekserem w domenie SCLK ([ADR 0009](adr/0009-interfejs-hosta.md)).

**`csr_regs`** — [opis](vhdl/csr_regs.md) (domena `clk_sys`) — mapa rejestrów w rozdziale 7.4; zatrzask przestrzeni odczytu przy opadnięciu CS, zapis po podniesieniu CS, przerwania, `MODE_CTRL` zachowywany przy resecie programowym.

**`host_clk`** — [opis](vhdl/host_clk.md) — prymityw `DCS`: zegar strony hosta FIFO = `clk_sys` w resecie oraz w trybach UART i echa ramek, SCLK w trybie xSPI; reset strony hosta zawsze na `clk_sys`.

**`frame_echo`** — [opis](vhdl/host_clk.md) — echo ramek (`MODE_CTRL.FRAME_ECHO`): kopiowanie ramek z FIFO RX do FIFO TX po stronie hosta.

**`async_fifo`** — [opis](vhdl/async_fifo.md)
- BSRAM w trybie semi-dual port (zapis port A, odczyt port B, różne zegary); wskaźnik odczytu w kodzie Graya, zatwierdzony wskaźnik zapisu przez handshake (zatwierdzenie przesuwa wskaźnik o całą ramkę).
- Zatwierdzanie i odrzucanie ramki (`commit` / `abort`).
- Flagi: pusty, pełny (dokładne); poziomy zapełnienia (informacyjne, takt opóźnienia).
- Rozmiary: TX 4 KiB (2 bloki), RX 8 KiB (4 bloki — wymagane przez progi XOFF, [ramkowanie](vhdl/framing.md)), tablica dekodera 8b/10b (1 blok). Razem 7 z 26 bloków. Bufor I2C (128 B) jest w pamięci rozproszonej (SSRAM), bo odczyt rejestrów z domeny SCLK wymaga odczytu asynchronicznego.

**`tx_framer`** — [opis](vhdl/framing.md)
- Ramka: `K27.7 (SOF) | TYPE | LEN_H | LEN_L | payload (1..1024 B) | CRC32 (4 B) | K29.7 (EOF)`; FIFO TX zawiera ramki w postaci `TYPE, LEN_H, LEN_L, payload`.
- Poza ramką ciągła bezczynność: para `K28.5 + D16.2` (/I/, XON), `K28.5 + D21.5` (/P/, XOFF) lub `K28.5 + D5.6` (/R/, własny odbiornik niezsynchronizowany — [ADR 0008](adr/0008-stan-lacza.md)).
- Ramkę zaczyna dopiero wtedy, gdy w TX FIFO jest cała (zatwierdzona) ramka i strona przeciwna nie zgłasza XOFF ani niegotowości; ramka rozpoczęta jest wysyłana do końca.

**`crc32`** — [opis](vhdl/crc32.md): CRC-32 IEEE 802.3, przetwarzanie bajtowe, jeden bajt na takt.

**`enc_8b10b` / `dec_8b10b`** — [opis](vhdl/8b10b.md)
- Standardowa tabela 5b/6b + 3b/4b z bieżącym dysparytetem; tablica dekodera wyliczana z funkcji kodera (ROM w BSRAM).
- Dekoder zgłasza flagi `code_err` i `disp_err`.

**`tx_gearbox`, `tx_phy`, `rx_phy`** — [opis](vhdl/phy.md)
- `tx_gearbox`: symbol 10-bitowy co 5 taktów `clk_sys` → 2 bity na takt; impuls `char_en` dla `tx_framer` i `enc_8b10b`.
- `tx_phy`: `OSER8` taktowany `clk_fast` (FCLK) / `clk_sys` (PCLK), każdy bit powielony 4× → `TLVDS_OBUF`.
- `rx_phy`: `TLVDS_IBUF` → `IDES8` (FCLK = 200 MHz, PCLK = 50 MHz) → 8 próbek na takt `clk_sys`.
- Generyk `INVERT` — odwrócenie polaryzacji pary. W rev. A para RD jest odwrócona na płytce (3.2, reguła 9): `rx_phy` z `INVERT => true`, wejścia bufora `rd_p => sfp_rd_n`, `rd_n => sfp_rd_p`; `tx_phy` z `INVERT => false`.

**`cdr_os4x8`** — [opis](vhdl/cdr.md)
- Wejście: 8 próbek na takt (2 bity × 4 próbki). Wykrywanie zboczy między kolejnymi próbkami (także między taktami), liczniki zboczy w czterech klasach fazowych przez okno 32 taktów.
- Decyzja raz na okno: średnie położenie granic bitów względem chwili próbkowania; krok fazy o 1/4 UI przy odchyleniu > 0,625 okresu próbkowania (strefa martwa z histerezą — jitter nie przełącza fazy); osobna reguła dla granic leżących przy chwili próbkowania.
- Śledzenie dryfu: przy zawinięciu fazy wydanie **1 albo 3 bitów** zamiast 2, co kompensuje różnicę ppm (zakres ok. 3900 ppm).
- Wyjście: liczba bitów (1–3) + `bits(2:0)`.

**`comma_align`** — [opis](vhdl/comma_align.md)
- Rejestr przesuwny 12 bitów, wykrywanie wzorca comma (`0011111` / `1100000`) w do 3 położeniach na takt i ustalenie granicy słowa 10-bit.
- Synchronizacja po 4 comma w oczekiwanej pozycji bez błędów dekodera; w synchronizacji granica nie jest przesuwana, utrata po 4 błędach (licznik maleje po 4 poprawnych symbolach) — maszyna stanów jak w 1000BASE-X PCS, ze sprzężeniem zwrotnym z `dec_8b10b`.

**`rx_deframer`** — [opis](vhdl/framing.md)
- Oczekiwanie na SOF, odczyt typu i długości, zapis do RX FIFO, liczenie CRC.
- Błąd (kod/dysparytet, długość, nieoczekiwany znak sterujący, CRC, brak miejsca) → odrzucenie ramki (`abort`) i impuls zdarzenia dla liczników.
- Odbiór stanu strony przeciwnej (gotowość /R/, XON/XOFF); generowanie własnego XOFF z progiem i histerezą (FIFO RX 8 KiB).

**`link_ctrl`** — [opis](vhdl/link_ctrl.md), [ADR 0008](adr/0008-stan-lacza.md)
- Stany: `DOWN` (LOS — o ile nie jest ignorowany, brak modułu lub brak synchronizacji) → `SYNC` (własny odbiornik zsynchronizowany, strona przeciwna nadaje /R/) → `UP`. Ramki są rozpoczynane tylko w stanie UP.
- Sterowanie `tx_framer`: `rx_ready` (gdy 0 — bezczynność /R/) i wstrzymanie nadawania (`tx_hold`).
- Liczniki 32-bit (zawijanie, `CNT_CLR`): błędy kodu i dysparytetu, CRC, długości, ramkowania, przepełnienia, ramki TX/RX, utraty synchronizacji.
- Pętle zwrotne: near-end (bity `tx_gearbox` → wejście `cdr_os4x8`, bez SFP) w `link_ctrl`; far-end jako echo ramek (FIFO RX → FIFO TX, `MODE_CTRL.FRAME_ECHO`, moduł `frame_echo`).

**`i2c_master` + `sfp_mgmt`** — [opis](vhdl/sfp_mgmt.md)
- I2C 100 kHz (INF-8074i), open-drain, wydłużanie SCL przez moduł, limit 25 ms, odblokowanie magistrali (impulsy SCL przy SDA trzymanej przez moduł).
- Skrzynka poleceń: `I2C_DEV`, `I2C_OFFSET`, `I2C_LEN` (1–128), `I2C_CMD` (READ / WRITE), `I2C_STATUS` (BUSY / NACK / TIMEOUT / BAD_CMD), bufor `I2C_BUF` 128 B w pamięci rozproszonej (odczyt asynchroniczny w domenie SCLK, jak zatrzask CSR).
- Odczyt DDM co `DDM_PERIOD` × 100 ms (domyślnie 1 s), od 300–400 ms po włożeniu modułu: bajty 96–110 z A2h w jednym poleceniu; kopia temperatury, Vcc, prądu lasera, mocy TX i RX (little-endian) oraz bajtu 110, aktualizowana w całości po udanym odczycie.
- Filtry `MOD_ABS` (10 ms), `LOS` i `TX_FAULT` (50 µs); zmiana stanu generuje przerwanie `SFP_CHG`. `SFP_TX_DIS` = 1 w czasie resetu.

**`leds`** — [opis](vhdl/top.md) — LINK: świeci przy `UP`, miga 2 Hz przy `SYNC`, zgaszona przy `DOWN`; ACT: błysk 30 ms z przerwą 30 ms przy ramce TX/RX; diody aktywne stanem niskim.

**`sfp_bridge_top`** — [opis](vhdl/top.md) — integracja wszystkich modułów, wybór trybu (UART / echo / xSPI) i multipleksowanie pinów J3, odwrócona para RD (`rx_phy` z `INVERT`), ograniczenia czasowe z zegarami generowanymi PLL / CLKDIV / DCS; testy end-to-end dwóch mostków: [wyniki](e2e/index.md).

**`uart_rx`, `uart_tx`, `uart_bridge`** — tryb przezroczysty, zob. 7.7.

### 7.3 Zestaw komend xSPI (wzorowany na SPI NOR)

Decyzja i uzasadnienie: [ADR 0009](adr/0009-interfejs-hosta.md). Instrukcja zawsze na 1 linii, adres 8-bit na 1 linii, SDR, tryb 0, najstarszy bit pierwszy; w formacie 1-x-1 dane od hosta na IO0, do hosta na IO1.

| Opkod | Nazwa | Format | Dummy | Dane |
|---|---|---|---|---|
| `0x9F` | READ_ID | 1-0-1 | 0 | 4 B: `0x5B`, `0x5F` (ID), wersja, `0x00` |
| `0x05` | READ_STATUS | 1-0-1 | 0 | rejestr `STATUS_FAST` (powtarzany) |
| `0x0B` | READ_REG | 1-1-1 | 8 | rejestry od adresu, auto-inkrementacja |
| `0x02` | WRITE_REG | 1-1-1 | 0 | do 8 bajtów od adresu, auto-inkrementacja |
| `0x12` / `0x32` / `0x82` | TX_WRITE_1 / _4 / _8 | 1-0-1 / 1-0-4 / 1-0-8 | 0 | bajty ramki do FIFO TX |
| `0x13` / `0x6B` / `0x8B` | RX_READ_1 / _4 / _8 | 1-0-1 / 1-0-4 / 1-0-8 | 8 | bajty ramek z FIFO RX |
| `0x66` | TX_ABORT | 1-0-0 | — | porzucenie niezatwierdzonej ramki |

Zasady:
- Ramki w formacie surowym FIFO: zapis `TX_WRITE_x` — bajty `TYPE, LEN_H, LEN_L, treść`, slave zatwierdza ramkę z ostatnim bajtem treści (ramka może być podzielona na kilka transakcji); odczyt `RX_READ_x` — bajty `TYPE, LEN_H, LEN_L, treść` kolejnych ramek. Przed zapisem host sprawdza `TX_SPACE` / `TX_READY`, przed odczytem `RX_AVAIL` / `RX_LEVEL`.
- Rejestry są zatrzaskiwane przy opadnięciu CS (spójny odczyt w obrębie transakcji), zapisy stosowane po podniesieniu CS. Wymagania: SCLK ≤ 40 MHz (przy odczycie zalecane przesunięcie próbkowania `SSHT`), CS w stanie wysokim ≥ 100 ns między transakcjami.
- Dummy cycles dają FPGA czas na publikację wskaźnika FIFO w domenie SCLK i pobranie pierwszego bajtu.
- Opkody `0x8x` są własne (nie z JEDEC), a STM32 OCTOSPI w trybie indirect przyjmie dowolny opkod.

### 7.4 Mapa rejestrów CSR

Adresy bajtowe, wartości wielobajtowe little-endian ([ADR 0009](adr/0009-interfejs-hosta.md)).

| Adres | Nazwa | R/W | Zawartość |
|---|---|---|---|
| 0x00–0x01 | ID | R | `0x5F5B` |
| 0x02 | VERSION | R | wersja bitstreamu |
| 0x04 | CTRL | R/W | b0 `TX_EN`, b1 `RX_EN`, b2 `LB_NEAR` (pętla near-end), b3 `SFP_TX_DIS`, b4 `LOS_IGNORE`, b6 `CNT_CLR` (zapis 1: kasowanie liczników), b7 `SOFT_RST` (zapis 1: reset mostka); po resecie `0x03` |
| 0x05 | STATUS | R | b0 `LINK_UP`, b1 `SYNC`, b2 `REMOTE_READY`, b3 `XOFF_LOCAL`, b4 `XOFF_REMOTE`, b5 `LOS`, b6 `TX_FAULT`, b7 `MOD_ABS` |
| 0x06 | STATUS_FAST | R | b0 `LINK_UP`, b1 `RX_AVAIL`, b2 `TX_READY`, b3 `TX_EMPTY`, b4 `IRQ`, b5 `MODE_SEL` (stan zworki) |
| 0x07 | IRQ_EN | R/W | maska przerwań |
| 0x08 | IRQ_STAT | R/W1C | b0 `RX_FRAME`, b1 `TX_EMPTY`, b2 `LINK_CHG`, b3 `SFP_CHG`, b4 `I2C_DONE`, b5 `ERR` |
| 0x0A–0x0B | TX_SPACE | R | wolne bajty w FIFO TX |
| 0x0C–0x0D | RX_LEVEL | R | bajty zatwierdzonych ramek w FIFO RX |
| 0x10–0x2F | CNT_* | R | liczniki 32-bit (zawijanie, kasowanie `CTRL.CNT_CLR`): CODE_ERR, CRC_ERR, LEN_ERR, FRAMING_ERR, RX_OVF, FRAMES_TX, FRAMES_RX, SYNC_LOSS |
| 0x30 | I2C_DEV | R/W | adres 7-bit urządzenia I2C; po resecie 0x50 (A0h) |
| 0x31 | I2C_OFFSET | R/W | offset w urządzeniu |
| 0x32 | I2C_LEN | R/W | liczba bajtów 1–128 |
| 0x33 | I2C_CMD | W | 0x01 READ, 0x02 WRITE (odczyt 0) |
| 0x34 | I2C_STATUS | R | b0 `BUSY` (ustawiony już w takcie przyjęcia polecenia), b1 `NACK`, b2 `TIMEOUT`, b3 `BAD_CMD` (`LEN` spoza 1–128, brak modułu, polecenie w czasie `BUSY`; do następnego przyjętego polecenia) |
| 0x40–0x49 | DDM_TEMP, DDM_VCC, DDM_TXBIAS, DDM_TXPWR, DDM_RXPWR | R | kopia A2h bajtów 96–105, wartości 16-bit little-endian |
| 0x4A | DDM_FLAGS | R | kopia A2h bajtu 110 |
| 0x4B | DDM_STAT | R | b0 `VALID` (udany odczyt od włożenia modułu), b1 `NACK`, b2 `TIMEOUT` (ostatni odczyt) |
| 0x4C | DDM_SEQ | R | licznik udanych odczytów DDM (zawijanie) |
| 0x4F | DDM_PERIOD | R/W | okres odczytu DDM × 100 ms; 0 = wyłączony; po resecie 10 |
| 0x50 | MODE_CTRL | R/W | b0 `UART_MODE`, b1 `FRAME_ECHO`, b2 `RTSCTS_EN`; zachowywany przy resecie programowym; zmiana b0 / b1 resetuje mostek |
| 0x51–0x52 | UART_DIV | R/W | takty `clk_sys` na bit UART (434 = 115 200); zachowywany przy resecie programowym (jak `MODE_CTRL`), więc prędkość ustawiona przed przejściem w tryb UART przez `MODE_CTRL` obowiązuje po resecie, który to przejście wywołuje |
| 0x53 | UART_STATUS | R/W1C | b0 `RX_OVF`, b1 `FRAME_ERR`; kasowany tylko przy włączeniu zasilania i przez W1C (przetrwa `HOST_RST_N`, którym host wraca z trybu UART do xSPI) |
| 0x80–0xFF | I2C_BUF | R/W | bufor I2C 128 B: wynik READ, dane do WRITE (od 0x80); czytany bez zatrzasku, stały przy `BUSY` = 0 |

Nieopisane adresy: odczyt 0, zapis ignorowany. `HOST_IRQ_N` = 0, gdy (`IRQ_STAT` ∧ `IRQ_EN`) ≠ 0.

### 7.5 Zasoby (GW1N-9)

Pełny układ po syntezie i PnR (Gowin EDA 1.9.11.03, ograniczenia z `sfp_bridge.sdc`):

| Zasób | Użycie |
|---|---|
| logika (LUT, ALU) | 4483 z 8640 (52 %) |
| rejestry | 2833 z 6480 (44 %) |
| BSRAM | 7 z 26 (FIFO TX 2, FIFO RX 4, tablica dekodera 8b/10b 1) |
| SSRAM (RAM16) | 40 (bufor I2C, bufor `uart_bridge`) |
| rPLL / CLKDIV / DCS | 1 / 1 / 1 |
| `clk_sys` / `clk_host` | wymaganie 50 / 40 MHz, Fmax 56 / 44 MHz |

### 7.6 Prymitywy Gowin (VHDL)

Deklaracje komponentów: `library gw1n; use gw1n.components.all;` (biblioteka z Gowin EDA). Użyte prymitywy: `rPLL`, `CLKDIV`, `DCS`, `TLVDS_IBUF`, `TLVDS_OBUF`, `IDES8`, `OSER8`; bufory trójstanowe (xSPI IO, I2C) są wnioskowane z kodu. Pamięci (FIFO — SDPB, tablica dekodera — pROM) są wnioskowane z kodu; synteza potwierdza mapowanie na BSRAM.

Weryfikacja: GHDL, samosprawdzające testbenche VHDL-2008, przebiegi w GTKWave ([ADR 0003](adr/0003-weryfikacja-ghdl.md), [symulacja](vhdl/symulacja.md)); moduły z prymitywami Gowin z modelami `prim_sim.vhd`. Testbench `tb_cdr_os4x8`: odchyłka częstotliwości do ±1000 ppm, losowy jitter do ±0,3 UI (wymaganie: ±100 ppm, ±0,2 UI).

### 7.7 Tryb przezroczysty UART

Decyzja i uzasadnienie: [ADR 0006](adr/0006-tryb-uart-przezroczysty.md).

- Wybór trybu: zworka `MODE_SEL` (pin 10) próbkowana po resecie — otwarta: xSPI, zwarta do masy: UART; w trybie xSPI dodatkowo bit `UART_MODE` w `MODE_CTRL`.
- Piny J3 w trybie UART: `XSPI_IO0` = `UART_RX` (wejście), `XSPI_IO1` = `UART_TX` (wyjście), opcjonalnie `XSPI_IO2` = `UART_RTS_N` (wyjście), `XSPI_IO3` = `UART_CTS_N` (wejście); pozostałe linie xSPI w stanie wysokiej impedancji, `HOST_IRQ_N` = stan łącza.
- 8N1, domyślnie 115200 baud; inna prędkość (do ok. 3 Mbaud) przez `UART_DIV` w trybie xSPI.
- Pakietyzacja: ramka `TYPE = 0x01` po 64 bajtach lub po przerwie > 2 czasy znaku; odbiór: treść ramek `TYPE = 0x01` na `UART_TX`.
- Moduły: `uart_rx`, `uart_tx`, `uart_bridge` — [opis](vhdl/uart.md); `UART_DIV` = liczba taktów `clk_sys` na bit (434 = 115 200, minimum 8); RTS wstrzymuje nadawcę przy zapełnieniu FIFO TX; multipleksowanie pinów J3 i zegara strony hosta FIFO w `sfp_bridge_top` ([integracja](vhdl/top.md)); RTS (IO2) jest sterowany tylko przy `RTSCTS_EN`, w przeciwnym razie IO2 pozostaje w stanie wysokiej impedancji.

---

## 8. Biblioteka C dla STM32

Biblioteka `sfp_bridge` — [opis](firmware.md). C11, bez dynamicznej alokacji, prefiks `sfpb_`, konfiguracja przez `#define` w `sfpb_config.h`.

```
firmware/
  sfp_bridge/include/   sfp_bridge.h (API), sfpb_regs.h (komendy, rejestry),
                        sfpb_port.h (transport), sfpb_config_default.h
  sfp_bridge/config/    sfpb_config_template.h
  sfp_bridge/src/       sfp_bridge.c (transakcje, rejestry, ramki, zdarzenia,
                        liczniki, UART), sfpb_sfp.c (I2C, identyfikacja, DDM)
  sfp_bridge/port/      sfpb_port_ospi.c, sfpb_port_xspi.c, sfpb_port_qspi.c,
                        sfpb_port_spi.c (HAL + GPIO CS), sfpb_port_stm32.c
  examples/             example_bridge.c
  tests/                testy na PC z modelem mostka (make)
```

- Transport: `SFPB_TRANSPORT_OSPI` / `_XSPI` / `_QSPI` / `_SPI` (porty HAL, opcjonalnie DMA) lub `_CUSTOM` (struktura `sfpb_port_t`: transakcja xSPI, `HOST_RST_N`, zegar ms, opóźnienie). Port domyślny z makr konfiguracji; kolejne mostki — porty budowane w czasie wykonania.
- Funkcje: ramki (`sfpb_send()`, `sfpb_recv()` z obsługą obcięcia), rejestry i stan, przerwania (`sfpb_irq_notify()` z EXTI, `sfpb_process()` z wywołaniami zwrotnymi), liczniki, pamięć modułu SFP i identyfikacja, DDM w jednostkach SFF-8472 z kalibracją wewnętrzną i zewnętrzną, alarmy, tryb UART (`UART_DIV`, RTS/CTS, `UART_STATUS`), echo ramek, reset programowy i sprzętowy.
- Weryfikacja: testy na PC z modelem mostka na poziomie transakcji (207 sprawdzeń, kontrola każdej transakcji z tabelą komend 7.3), test mutacyjny (17 wariantów), kompilacja portów z nagłówkami STM32Cube dla L4R5 (OSPI), H563 (XSPI), F446 / L476 (QSPI), G0B1 (SPI).

---

## 9. Plan uruchomienia (bring-up)

1. Zasilanie, konfiguracja FPGA przez JTAG, odczyt `DONE` (programator przez AUX/JP2 lub pomiar na R6).
2. Bitstream `sfp_bridge` bez modułu SFP: `LED_LINK` zgaszona (stan DOWN), `SFP_TX_DIS` = 1, odpowiedź na `READ_ID` przez SPI (1 linia, 1–5 MHz).
3. **Tryb UART** (zworka `MODE_SEL` zwarta) na dwóch płytkach połączonych patchcordem, po stronie każdej adapter USB-UART i terminal: echo i transfer plików 115200 → 3 Mbaud. Pierwszy test łącza optycznego bez sterownika OCTOSPI.
4. Near-end loopback w FPGA (bez optyki): ramki TX → RX, liczniki błędów = 0.
5. Biblioteka STM32: SPI, potem QSPI i OCTOSPI z rosnącym zegarem do 40 MHz; pomiar marginesu próbkowania (t_V z datasheetu, 4.2).
6. Odczyt identyfikacji modułu SFP przez I2C (producent, numer części) i diagnostyki DDM.
7. **Niska prędkość linii (10–25 Mbaud)** — wariant diagnostyczny: wykres oczkowy na RD±.
8. 100 Mbaud, test BER (pseudolosowe ramki, liczniki, ≥ 10¹² bitów).
9. Test z tłumikiem optycznym i różnymi modułami (MM, SM, BiDi).
10. Opcjonalnie: 125 Mbaud i wyżej.

---

## 10. Punkty do potwierdzenia

Weryfikację schematu i PCB rev. A (reguły projektowe, zgodność z przydziałem pinów i INF-8074i, pary LVDS, pliki produkcyjne) opisuje [raport weryfikacji płytki](pcb-rev-a.md).

Rozstrzygnięcia z dokumentacji producenta są podane w treści wraz ze źródłem (przydział pinów i bilans zasilania QN48 — UG114; terminacja wewnętrzna tylko w banku 0 — UG289, rozdz. 3.3.2; HCLK w GW1N-9C — UG286, rozdz. 2.2; tryb konfiguracji QN48 — UG290, tab. 5-1). Do potwierdzenia pozostają:

| Punkt | Sposób potwierdzenia |
|---|---|
| Stackup JLC04161H-7628: grubości dielektryków i εr (5.3.2) | kalkulator impedancji JLCPCB przed zamówieniem |
| Footprint klatki SFP zgodny z wybraną klatką (otwory press-fit) | rysunek producenta klatki |
| Minimalna amplituda wejścia TD wybranego modułu względem VOD FPGA (500 mVppd min wg INF-8074i) | datasheet modułu, pomiar na prototypie |
| Moduł SFP bez wewnętrznego CDR (moduły z CDR nie pracują przy 100 Mbaud) | datasheet modułu, test |
| Background upgrade Flash przez JTAG w GW1N-9C | UG290, test |
| Parametry czasowe xSPI przy 40 MHz (t_SU, t_V; datasheet 4.2) | pomiar na prototypie z OCTOSPI |
| Pull-upy 4,7–10 kΩ na `SFP_TX_FAULT`, `SFP_LOS`, `SFP_MOD_ABS` (w rev. A wewnętrzne pull-upy FPGA) | kolejna rewizja PCB |
| Zapas czasowy `clk_sys`: Fmax 56 MHz przy celu 60 MHz z [ADR 0007](adr/0007-zegar-systemowy-50mhz.md) | przy zmianach logiki; warunek konieczny dla 125 Mbaud |

## 11. Dokumentacja źródłowa

Dokumenty producentów nie są częścią repozytorium; są dostępne u wydawców.

| Dokument | Wydawca | Zawartość |
|---|---|---|
| DS100 — GW1N series of FPGA Products Data Sheet | Gowin Semiconductor | zasoby, tabela obudów, LVDS DC, gearbox, PLL |
| UG103 — GW1N series Package & Pinout | Gowin Semiconductor | obudowy, opis pinów |
| UG114 — GW1N-9 Pinout | Gowin Semiconductor | przypisanie pinów QN48, pary true LVDS |
| UG286 — Gowin Clock User Guide | Gowin Semiconductor | rPLL, CLKDIV, DCS, HCLK |
| UG289 — Gowin Programmable IO User Guide | Gowin Semiconductor | TLVDS, IDES/OSER, terminacja |
| UG290 — Gowin FPGA Products Programming and Configuration Guide | Gowin Semiconductor | tryby konfiguracji, piny dedykowane |
| UG284 — GW1N series Schematic Manual | Gowin Semiconductor | zasilanie, odsprzęganie, piny konfiguracyjne |
| UG285 — Gowin BSRAM & SSRAM User Guide | Gowin Semiconductor | SDPB, pamięć rozproszona |
| SUG935 — Gowin Design Physical Constraints User Guide | Gowin Semiconductor | składnia .cst |
| INF-8074i — SFP Transceiver | SFF Committee (SNIA) | pinout złącza, sygnały sterujące, poziomy TD/RD, filtr zasilania |
| SFF-8472 — Management Interface for SFP+ | SFF Committee (SNIA) | mapa pamięci A0h / A2h, diagnostyka DDM |
| XAPP224, XAPP523 — Data Recovery, LVDS 4x Asynchronous Oversampling | AMD (Xilinx) | odzysk danych z nadpróbkowania |

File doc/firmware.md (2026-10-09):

# Biblioteka C dla STM32

Biblioteka `sfp_bridge` obsługuje mostek SFP-xSPI z mikrokontrolera STM32: wymianę ramek, rejestry, przerwania, liczniki, pamięć i diagnostykę modułu SFP oraz przezroczysty tryb UART. Pliki: `firmware/sfp_bridge/`, przykład `firmware/examples/example_bridge.c`, testy `firmware/tests/`. Opis protokołu i rejestrów: [interfejs hosta (datasheet)](datasheet/index.md).

## 1 Cechy

- C11, bez dynamicznej alokacji; cały stan w strukturze `sfpb_t` (jedna na mostek, dowolna liczba mostków).
- Konfiguracja w czasie kompilacji przez `#define` w pliku `sfpb_config.h`: transport, liczba linii danych, uchwyty peryferiów, piny, funkcje włączane do kompilacji, limity czasu.
- Gotowe porty HAL: OCTOSPI (`HAL_OSPI`), XSPI (`HAL_XSPI`), QUADSPI (`HAL_QSPI`), SPI z programowym CS (`HAL_SPI`); opcjonalnie DMA. Własny transport przez strukturę `sfpb_port_t`.
- Obsługa wszystkich funkcji mostka: komendy `READ_ID`, `READ_STATUS`, `READ_REG`, `WRITE_REG`, `TX_WRITE_x`, `RX_READ_x`, `TX_ABORT`; rejestry `CTRL` (pętla zwrotna, wyłączenie lasera, `LOS_IGNORE`), przerwania i obsługa zdarzeń z wywołaniami zwrotnymi, liczniki błędów, polecenia I2C (odczyt i zapis pamięci A0h / A2h, identyfikacja modułu), diagnostyka DDM z przeliczeniem jednostek SFF-8472 (kalibracja wewnętrzna i zewnętrzna), progi alarmowe, `UART_DIV`, `MODE_CTRL` (tryb UART, RTS/CTS, echo ramek), `UART_STATUS`, reset programowy i sprzętowy (`HOST_RST_N`).

## 2 Struktura

```
firmware/
  sfp_bridge/
    include/sfp_bridge.h            API
    include/sfpb_regs.h             komendy xSPI, adresy i bity rejestrów
    include/sfpb_port.h             interfejs transportu (sfpb_port_t)
    include/sfpb_config_default.h   wartości domyślne konfiguracji
    config/sfpb_config_template.h   szablon sfpb_config.h
    src/sfp_bridge.c                transakcje, rejestry, ramki, zdarzenia, liczniki, UART
    src/sfpb_sfp.c                  I2C modułu, identyfikacja, DDM
    src/sfpb_internal.h             funkcje wewnętrzne
    port/sfpb_stm32.h               porty STM32 (kontekst, konstruktory)
    port/sfpb_port_stm32.c          wspólna część portów, port domyślny
    port/sfpb_port_ospi.c           HAL_OSPI
    port/sfpb_port_xspi.c           HAL_XSPI
    port/sfpb_port_qspi.c           HAL_QSPI
    port/sfpb_port_spi.c            HAL_SPI + GPIO CS
  examples/example_bridge.c         inicjalizacja, zdarzenia, DDM, sesja UART
  tests/                            testy na PC z modelem mostka
```

## 3 Włączenie do projektu

1. Dodać do projektu pliki `src/*.c` i `port/*.c` oraz ścieżki `include/`, `src/` i `port/`. Pliki portów niewybranych transportów kompilują się do pustych jednostek.
2. Skopiować `config/sfpb_config_template.h` jako `sfpb_config.h` do katalogu na ścieżce include i ustawić co najmniej `SFPB_TRANSPORT` oraz uchwyt peryferium (nazwa zmiennej globalnej z CubeMX, np. `hospi1`).
3. Skonfigurować peryferium w CubeMX zgodnie z tabelą 3.1, `HOST_IRQ_N` jako wejście EXTI (zbocze opadające, podciągnięcie), `HOST_RST_N` jako wyjście GPIO w stanie wysokim.
4. Po inicjalizacji HAL wywołać `sfpb_init(&dev, NULL)` (port domyślny z `sfpb_config.h`), w obsłudze EXTI `sfpb_irq_notify(&dev)`, w pętli głównej `sfpb_process(&dev, 0)`.

Plik konfiguracyjny jest wyszukiwany w kolejności: makro `SFPB_CONFIG_FILE` z wiersza poleceń kompilatora, `sfpb_config.h` na ścieżce include (kompilatory z `__has_include`), brak pliku — wymagane wtedy `SFPB_NO_CONFIG_FILE` (same wartości domyślne).

### 3.1 Ustawienia peryferium

| Parametr | OCTOSPI / XSPI | QUADSPI | SPI |
|---|---|---|---|
| tryb | pośredni (indirect), pamięć typu Micron / standard | pośredni (indirect) | master full-duplex, 8 bit, NSS programowy |
| zegar | ≤ 40 MHz (`ClockPrescaler`) | ≤ 40 MHz | zalecane ≤ 20 MHz |
| tryb zegara | 0 (SCLK niski w spoczynku) | 0 | CPOL = 0, CPHA = 0, MSB first |
| próbkowanie | `SampleShifting` = połowa cyklu | `SampleShifting` = połowa cyklu | zbocze narastające (stąd niższy zegar) |
| CS wysoki między transakcjami | `ChipSelectHighTime` ≥ 100 ns (4 cykle przy 40 MHz) | jw. | zapewniony przez czas wykonania kodu |
| linie IO | IO0…IO7 (`IOSelect` = IO[7:0] w XSPI) | IO0…IO3, bank 1 | MOSI = IO0, MISO = IO1 |

Przy 40 MHz próbkowanie danych mostka na zboczu narastającym ma budżet pół okresu ([datasheet, 4.2](datasheet/index.md#42-wymagania-czasowe-interfejsu-xspi)); dlatego OCTOSPI i QUADSPI pracują z przesunięciem próbkowania, a SPI — z niższym zegarem.

## 4 Konfiguracja

| Makro | Domyślnie | Znaczenie |
|---|---|---|
| `SFPB_TRANSPORT` | `SFPB_TRANSPORT_OSPI` | `_OSPI`, `_XSPI`, `_QSPI`, `_SPI` lub `_CUSTOM` (port przekazywany do `sfpb_init()`) |
| `SFPB_DATA_LINES` | 8 / 4 / 1 wg transportu | linie danych komend `TX_WRITE_x` / `RX_READ_x`; kontrola zgodności z transportem w czasie kompilacji |
| `SFPB_HAL_HEADER` | `"main.h"` | nagłówek HAL układu |
| `SFPB_OSPI_HANDLE`, `SFPB_XSPI_HANDLE`, `SFPB_QSPI_HANDLE`, `SFPB_SPI_HANDLE` | `hospi1`, `hxspi1`, `hqspi`, `hspi1` | uchwyt peryferium portu domyślnego |
| `SFPB_SPI_CS_PORT`, `SFPB_SPI_CS_PIN` | — | CS dla transportu SPI (wymagane) |
| `SFPB_RST_PORT`, `SFPB_RST_PIN` | — | `HOST_RST_N`; bez nich niedostępne `sfpb_hw_reset()` i `sfpb_mode_exit()` |
| `SFPB_USE_DMA`, `SFPB_DMA_MIN_LEN` | 0, 32 | DMA dla faz danych ≥ `SFPB_DMA_MIN_LEN` bajtów |
| `SFPB_HAL_TIMEOUT_MS` | 10 | limit czasu jednego wywołania HAL |
| `SFPB_USE_I2C` | 1 | polecenia I2C, identyfikacja modułu |
| `SFPB_USE_DDM` | 1 | rejestry DDM i przeliczenie jednostek |
| `SFPB_DDM_EXT_CAL` | 1 | kalibracja zewnętrzna SFF-8472 (arytmetyka `float`; wymaga `SFPB_USE_I2C`) |
| `SFPB_USE_FLOAT` | 1 | `sfpb_nw_to_dbm()` (`log10f`) |
| `SFPB_USE_UART` | 1 | `UART_DIV`, `MODE_CTRL`, `UART_STATUS`, echo ramek |
| `SFPB_USE_EVENTS` | 1 | `sfpb_process()` z wywołaniami zwrotnymi; bufor odbiorczy w `sfpb_t` |
| `SFPB_IRQ_MASK_DEFAULT` | `RX_FRAME` \| `LINK_CHG` \| `SFP_CHG` \| `ERR` (0 bez zdarzeń) | `IRQ_EN` po inicjalizacji |
| `SFPB_RX_BUF_SIZE` | 1024 | bufor ramki dla `sfpb_process()` |
| `SFPB_TIMEOUT_MS` | 100 | oczekiwanie na miejsce w FIFO TX w `sfpb_send()` |
| `SFPB_READY_TIMEOUT_MS` | 100 | oczekiwanie na `READ_ID` po resecie |
| `SFPB_I2C_TIMEOUT_MS` | 100 | jedno polecenie I2C |
| `SFPB_EEPROM_WRITE_MS` | 20 | ponawianie poleceń I2C zakończonych `NACK` (cykl zapisu EEPROM) |
| `SFPB_EEPROM_PAGE` | 8 | rozmiar strony EEPROM — zapis nie przekracza granicy strony |
| `SFPB_RESET_PULSE_MS` | 1 | czas impulsu `HOST_RST_N` (filtr mostka 640 ns) |

Kod biblioteki z portem (wszystkie funkcje, `-O2`, Cortex-M4): ok. 6,3 KB; bez I2C, DDM, UART i zdarzeń ok. połowy tej wartości. Pamięć RAM: `sfpb_t` ok. 1,1 KB ze zdarzeniami (bufor ramki `SFPB_RX_BUF_SIZE`), poniżej 100 B bez nich.

## 5 Warstwa portu

Port wykonuje jedną transakcję xSPI (CS niski … CS wysoki): instrukcja 8-bitowa na 1 linii, opcjonalny adres 8-bitowy na 1 linii, cykle dummy, faza danych na 1 / 4 / 8 liniach. W formatach 1-x-1 dane od hosta biegną linią IO0, do hosta — IO1.

```c
typedef struct sfpb_port {
    int      (*xfer)(void *ctx, const sfpb_cmd_t *cmd, uint8_t *data, size_t len);
    void     (*set_reset)(void *ctx, int asserted);   /* HOST_RST_N lub NULL */
    uint32_t (*get_ms)(void *ctx);
    void     (*delay_ms)(void *ctx, uint32_t ms);
    void     *ctx;
    uint8_t  max_lines;                                /* 1, 4 lub 8          */
} sfpb_port_t;
```

- `xfer` zwraca 0 albo wartość ujemną (błąd magistrali) i nie modyfikuje danych w kierunku zapisu.
- Port domyślny (`sfpb_port_default()`) powstaje z makr konfiguracji. Porty dla kolejnych mostków buduje się w czasie wykonania funkcjami `sfpb_port_ospi()`, `sfpb_port_xspi()`, `sfpb_port_qspi()`, `sfpb_port_spi()` z kontekstem `sfpb_stm32_ctx_t` (uchwyt, CS, `HOST_RST_N`); plik portu innego transportu niż `SFPB_TRANSPORT` włącza makro `SFPB_PORT_OSPI` / `_XSPI` / `_QSPI` / `_SPI` = 1.
- Własny transport (inna rodzina MCU, system operacyjny, magistrala współdzielona): `SFPB_TRANSPORT_CUSTOM` i własna struktura `sfpb_port_t`.

```c
static sfpb_stm32_ctx_t ctx_b = { &hospi2, NULL, 0, GPIOC, GPIO_PIN_3 };
sfpb_port_t port_b;
sfpb_port_ospi(&port_b, &ctx_b);
sfpb_init(&bridge_b, &port_b);
```

## 6 API

Funkcje zwracające `int` dają `SFPB_OK` (0) albo kod błędu z rozdziału 7; funkcje stanu (`sfpb_link_up()`, `sfpb_mode_sel()`, `sfpb_sfp_present()`) zwracają 1 / 0 albo kod błędu.

### 6.1 Inicjalizacja i reset

| Funkcja | Działanie |
|---|---|
| `sfpb_init(dev, port)` | inicjalizacja; `port` = NULL — port domyślny. Oczekuje na `READ_ID` (`5B 5F`), odczytuje `VERSION` (`dev->version`), zapisuje `IRQ_EN` i kasuje `IRQ_STAT` |
| `sfpb_wait_ready(dev, ms)` | ponawianie `READ_ID` do skutku lub upływu czasu |
| `sfpb_read_id(dev, &ver)` | `READ_ID` |
| `sfpb_hw_reset(dev)` | impuls `HOST_RST_N`, oczekiwanie na gotowość, odtworzenie `IRQ_EN`; powrót z trybu UART i echa |
| `sfpb_soft_reset(dev)` | `CTRL.SOFT_RST` (FIFO tracone, `MODE_CTRL` i `UART_DIV` zachowane), odtworzenie `IRQ_EN` |
| `sfpb_set_timeout(dev, ms)` | limit czasu `sfpb_send()` |
| `sfpb_set_data_lines(dev, n)` | linie danych 1 / 4 / 8 (≤ `max_lines` portu) |
| `sfpb_strerror(err)` | opis kodu błędu |

### 6.2 Rejestry i stan

| Funkcja | Działanie |
|---|---|
| `sfpb_read_regs(dev, adr, buf, n)` | `READ_REG`, 1–256 bajtów w jednej transakcji (spójny odczyt rejestrów wielobajtowych) |
| `sfpb_write_regs(dev, adr, buf, n)` | `WRITE_REG`, dzielone na transakcje po 8 bajtów |
| `sfpb_read_reg8()`, `sfpb_write_reg8()` | pojedynczy rejestr |
| `sfpb_read_status_fast(dev, &sf)` | `READ_STATUS` (`STATUS_FAST`) |
| `sfpb_get_status(dev, &st)` | `CTRL`, `STATUS`, `STATUS_FAST`, `IRQ_EN`, `IRQ_STAT`, `TX_SPACE`, `RX_LEVEL` w jednej transakcji |
| `sfpb_link_up(dev)`, `sfpb_wait_link(dev, ms)` | stan łącza `LINK_UP` |
| `sfpb_mode_sel(dev)` | stan zworki `MODE_SEL` |
| `sfpb_ctrl_update(dev, maska, wartość)` | odczyt–modyfikacja–zapis bitów 0–4 `CTRL`; skróty: `sfpb_set_tx_enable()`, `sfpb_set_rx_enable()`, `sfpb_set_loopback()`, `sfpb_set_laser_off()`, `sfpb_set_los_ignore()` |

### 6.3 Ramki

| Funkcja | Działanie |
|---|---|
| `sfpb_send(dev, type, data, len)` | ramka 1–1024 B: oczekiwanie na miejsce (`TX_READY` lub `TX_SPACE` ≥ `len` + 3) do limitu czasu urządzenia, zapis nagłówka i treści; przy błędzie transportu w fazie treści — `TX_ABORT` |
| `sfpb_send_timeout(..., ms)` | jw. z własnym limitem; 0 — bez oczekiwania |
| `sfpb_tx_space()`, `sfpb_wait_tx_empty()`, `sfpb_tx_abort()` | stan i sterowanie FIFO TX |
| `sfpb_recv(dev, &type, buf, max, &len)` | jedna ramka bez blokowania (`SFPB_ERR_EMPTY`, gdy brak); ramka dłuższa niż `max` jest odczytywana do końca, w buforze zostaje `max` bajtów, `len` = długość rzeczywista, wynik `SFPB_ERR_TRUNC` |
| `sfpb_recv_timeout(..., ms)` | jw. z oczekiwaniem |
| `sfpb_rx_level()` | `RX_LEVEL` |

Odbiór czyta `RX_LEVEL` tylko wtedy, gdy wyczerpie bajty znane z poprzedniego odczytu; ramka zajmuje dwie transakcje `RX_READ_x` (nagłówek, treść). Wysłanie ramki to `READ_STATUS` i dwie transakcje `TX_WRITE_x`.

### 6.4 Przerwania i zdarzenia

| Funkcja | Działanie |
|---|---|
| `sfpb_irq_enable(dev, maska)` | `IRQ_EN`; maska jest odtwarzana po każdym resecie |
| `sfpb_irq_read_clear(dev, &stat)` | odczyt `IRQ_STAT` i skasowanie odczytanych bitów (W1C) |
| `sfpb_irq_notify(dev)` | z obsługi EXTI `HOST_IRQ_N`; ustawia tylko znacznik |
| `sfpb_set_callbacks(dev, &cb, user)` | wywołania zwrotne: `rx_frame`, `link_change`, `sfp_change`, `tx_empty`, `i2c_done`, `error` |
| `sfpb_process(dev, poll)` | po zgłoszeniu przerwania (lub zawsze przy `poll` ≠ 0): `IRQ_STAT` + W1C, odbiór wszystkich ramek, wywołania zwrotne; zwraca obsłużone bity `IRQ_STAT` |

`sfpb_process()` po obsłudze sprawdza bit `STATUS_FAST.IRQ`: zdarzenie zgłoszone między odczytem a skasowaniem `IRQ_STAT` utrzymuje `HOST_IRQ_N` w stanie niskim bez nowego zbocza, więc znacznik jest ustawiany ponownie. Zmiana modułu SFP (`SFP_CHG`) unieważnia zapamiętane stałe kalibracji DDM. Wywołanie `error` otrzymuje `SFPB_ERR_LINK` dla bitu `ERR` (szczegóły w licznikach), `SFPB_ERR_TRUNC` i `SFPB_ERR_PROTO` z odbioru.

### 6.5 Liczniki

`sfpb_read_counters(dev, &cnt)` — osiem liczników 32-bitowych w jednej transakcji (`cnt.n.crc_err` lub `cnt.v[SFPB_CNT_CRC_ERR]`); `sfpb_clear_counters(dev)` — `CTRL.CNT_CLR` z zachowaniem pozostałych bitów `CTRL`.

### 6.6 Moduł SFP

| Funkcja | Działanie |
|---|---|
| `sfpb_sfp_read(dev, adr7, offset, buf, len)` | odczyt pamięci urządzenia I2C (`SFPB_SFP_A0` = 0x50, `SFPB_SFP_A2` = 0x51), `offset` + `len` ≤ 256, polecenia po 128 B |
| `sfpb_sfp_write(dev, adr7, offset, buf, len)` | zapis stronami `SFPB_EEPROM_PAGE`; polecenie zakończone `NACK` (cykl zapisu poprzedniej strony) ponawiane przez `SFPB_EEPROM_WRITE_MS` |
| `sfpb_sfp_info(dev, &info)` | identyfikacja A0h 0–95: typ, złącze, kodowanie, prędkość nominalna, długość fali, producent, numer części, rewizja, numer seryjny, data, typ diagnostyki, sumy kontrolne |
| `sfpb_sfp_present(dev)` | obecność modułu (`STATUS.MOD_ABS`) |
| `sfpb_ddm_raw(dev, &raw)` | rejestry DDM mostka (A2h 96–105 i 110, `DDM_STAT`, `DDM_SEQ`) |
| `sfpb_ddm_read(dev, &ddm)` | wartości w jednostkach: m°C, µV, µA, nW; `SFPB_ERR_NO_DDM` przed pierwszym odczytem modułu lub dla modułu bez diagnostyki |
| `sfpb_ddm_alarms(dev, &al)` | flagi alarmów i ostrzeżeń (A2h 112–113, 116–117) |
| `sfpb_ddm_set_period(dev, n)` | okres odczytu DDM × 100 ms (0 — wyłączony) |
| `sfpb_nw_to_dbm(nw)` | moc w dBm |

Kalibracja: przy pierwszym `sfpb_ddm_read()` po inicjalizacji, resecie lub zmianie modułu biblioteka odczytuje bajt 92 A0h. Dla kalibracji zewnętrznej (bit 4) odczytuje stałe A2h 56–91 i stosuje wzory SFF-8472: nachylenie (stałoprzecinkowe 8.8) i przesunięcie dla prądu i mocy nadajnika, temperatury i napięcia oraz wielomian 4. stopnia (`float`) dla mocy odbiornika.

### 6.7 Tryb UART i echo ramek

| Funkcja | Działanie |
|---|---|
| `sfpb_uart_div(baud)` | `UART_DIV` = zaokrąglenie 50 MHz / `baud`; 0 poza zakresem 8–65535 |
| `sfpb_uart_set_baud()`, `sfpb_uart_get_baud()` | `UART_DIV` (oba bajty w jednej transakcji) |
| `sfpb_uart_set_rtscts(dev, on)` | `MODE_CTRL.RTSCTS_EN` bez resetu mostka |
| `sfpb_uart_enter(dev, baud, rtscts)` | `UART_DIV`, potem `MODE_CTRL.UART_MODE` — mostek resetuje się i przechodzi w tryb UART z zadaną prędkością |
| `sfpb_echo_enter(dev)` | `MODE_CTRL.FRAME_ECHO` — odsyłanie odebranych ramek (test łącza z drugiej strony) |
| `sfpb_mode_exit(dev)` | powrót do trybu xSPI przez `HOST_RST_N` (`UART_DIV` wraca do 115 200 bit/s) |
| `sfpb_uart_status(dev, &st, clear)` | `UART_STATUS` z ostatniej sesji UART (`RX_OVF`, `FRAME_ERR`), opcjonalnie W1C |

W trybie UART i echa mostek nie odpowiada na komendy xSPI; biblioteka zwraca wtedy `SFPB_ERR_STATE` bez wykonywania transakcji, aż do `sfpb_mode_exit()` lub `sfpb_hw_reset()`. `UART_STATUS` przetrwa `HOST_RST_N`, więc po powrocie host odczytuje zdarzenia sesji UART.

## 7 Kody błędów

| Kod | Wartość | Znaczenie |
|---|---|---|
| `SFPB_OK` | 0 | powodzenie |
| `SFPB_ERR_IO` | −1 | błąd transportu (HAL) |
| `SFPB_ERR_TIMEOUT` | −2 | warunek nie spełniony w zadanym czasie |
| `SFPB_ERR_PARAM` | −3 | błędny argument |
| `SFPB_ERR_NO_DEVICE` | −4 | `READ_ID` nie zwraca `5B 5F` |
| `SFPB_ERR_EMPTY` | −5 | brak kompletnej ramki w FIFO RX |
| `SFPB_ERR_TRUNC` | −6 | ramka dłuższa niż bufor (reszta pominięta) |
| `SFPB_ERR_NACK` | −7 | I2C: brak potwierdzenia |
| `SFPB_ERR_BAD_CMD` | −8 | I2C: polecenie odrzucone (brak modułu, długość) |
| `SFPB_ERR_I2C_TIMEOUT` | −9 | I2C: SCL przytrzymany, magistrala zablokowana |
| `SFPB_ERR_NOT_SUPPORTED` | −10 | funkcja nieskonfigurowana (np. brak pinu `HOST_RST_N`) |
| `SFPB_ERR_STATE` | −11 | mostek w trybie UART lub echa |
| `SFPB_ERR_NO_DDM` | −12 | moduł bez diagnostyki lub brak danych |
| `SFPB_ERR_PROTO` | −13 | niepoprawny nagłówek ramki w FIFO RX (zalecany reset programowy) |
| `SFPB_ERR_LINK` | −14 | `IRQ_STAT.ERR`: błąd ramki na łączu lub bajt utracony przy pełnym FIFO TX |

## 8 Zasady użycia

- Wywołania dla jednej struktury `sfpb_t` nie mogą przebiegać współbieżnie; w systemie z wątkami dostęp chroni muteks aplikacji. Wyjątek: `sfpb_irq_notify()` (tylko znacznik, wywoływana z przerwania).
- Funkcje oczekujące (`sfpb_send()`, `sfpb_wait_*()`, polecenia I2C) odpytują mostek co 1 ms przez `delay_ms` portu; w systemie RTOS `delay_ms` portu własnego może oddawać procesor.
- Przy `SFPB_USE_DMA` = 1 bufory danych muszą być dostępne dla DMA; na rdzeniach z pamięcią podręczną danych (Cortex-M7, M55) spójność bufora zapewnia aplikacja (obszar niebuforowany lub operacje na pamięci podręcznej). Port czeka na zakończenie DMA aktywnie (stan uchwytu HAL), przerwania DMA i peryferium muszą być włączone.
- Ramki `TYPE` 0x01 są zarezerwowane dla trybu UART ([datasheet, 5.4](datasheet/index.md#54-format-ramki-w-buforach)).

## 9 Przykład

```c
#include "sfp_bridge.h"

static sfpb_t bridge;

static void on_frame(void *user, uint8_t type, const uint8_t *data, uint16_t len)
{
    /* ramka odebrana: type, data[0..len-1] */
}

static const sfpb_callbacks_t cb = { .rx_frame = on_frame };

void app_init(void)
{
    if (sfpb_init(&bridge, NULL) == SFPB_OK) {
        sfpb_set_callbacks(&bridge, &cb, NULL);
    }
}

void HAL_GPIO_EXTI_Falling_Callback(uint16_t pin)    /* HOST_IRQ_N; F4/L4: HAL_GPIO_EXTI_Callback */
{
    sfpb_irq_notify(&bridge);
}

void app_loop(void)
{
    static const char msg[] = "Hello, SFP!";
    sfpb_process(&bridge, 0);
    if (sfpb_link_up(&bridge) == 1) {
        sfpb_send(&bridge, SFPB_TYPE_DATA, msg, sizeof msg - 1);
    }
}
```

Pełny przykład (identyfikacja modułu, DDM, sesja UART z odczytem `UART_STATUS`): `firmware/examples/example_bridge.c`.

## 10 Weryfikacja

**Testy na PC** (`make -C firmware/tests`, gcc, C11, `-Wall -Wextra -Wpedantic -Wconversion -Werror`): biblioteka działa z modelem mostka na poziomie transakcji (`mock_bridge.c`). Model odwzorowuje mapę rejestrów z zatrzaskiem i W1C, FIFO TX z zatwierdzaniem ramek i `TX_ABORT`, FIFO RX, łącze między dwoma modelami i pętlę zwrotną, przerwania, liczniki, silnik I2C z pamięcią A0h / A2h, czasem zajętości i stronicowaniem EEPROM, rejestry DDM, `MODE_CTRL`, `UART_DIV`, `UART_STATUS` i `HOST_RST_N`. Każda transakcja jest sprawdzana z tabelą komend (linie danych, faza adresu, cykle dummy, kierunek, długość `WRITE_REG`). Wynik: 207 sprawdzeń, PASS.

| Grupa | Sprawdzenia |
|---|---|
| inicjalizacja | `VERSION`, `IRQ_EN`, brak mostka (`NO_DEVICE` po limicie czasu), port 4-liniowy, walidacja liczby linii, `sfpb_strerror()` |
| rejestry | zapis 16 B w dwóch transakcjach, odczyt, migawka stanu, oczekiwanie na łącze, modyfikacja bitów `CTRL` bez naruszania pozostałych |
| ramki | 1, 11, 255, 256, 1024 B na 8, 4 i 1 linii; kolejność i typ; obcięcie z zachowaniem następnej ramki; FIFO TX pełne przy braku łącza (limit czasu, granica `TX_SPACE` z nagłówkiem); opróżnienie po zestawieniu łącza; błąd transportu w treści → `TX_ABORT`; niespójny strumień RX → `PROTO` |
| zdarzenia | `LINK_CHG`, wiele ramek w jednym `sfpb_process()`, tryb odpytywania, `SFP_CHG`, `ERR`, odtworzenie `IRQ_EN` po resecie |
| SFP | identyfikacja z obcięciem spacji i sumami kontrolnymi, odczyt 256 B, zapis przez granicę strony z ponawianiem `NACK`, nieznane urządzenie, zajętość EEPROM ponad limit, zablokowany `BUSY`, brak modułu |
| DDM | jednostki przy kalibracji wewnętrznej, temperatura ujemna, kalibracja zewnętrzna (nachylenie, przesunięcie, wielomian mocy RX), moduł bez DDM, alarmy, dBm |
| UART | `UART_DIV` (zaokrąglenie, zakres), RTS/CTS bez resetu, wejście w tryb UART, blokada transakcji, powrót przez `HOST_RST_N`, `UART_STATUS` zachowany i kasowany W1C, tryb echa |
| liczniki | odczyt little-endian, `CNT_CLR` z zachowaniem `CTRL` |

**Test mutacyjny:** 17 wariantów błędów, wszystkie wykrywane — brak cykli dummy `RX_READ`, `WRITE_REG` powyżej 8 bajtów, brak `TX_ABORT`, odwrócona kolejność bajtów, brak odtworzenia `IRQ_EN`, brak rozliczania bajtów RX, sprawdzanie miejsca bez nagłówka, brak W1C, obcięcie zamiast zaokrąglenia `UART_DIV`, brak kasowania RTS/CTS, brak ponawiania `NACK`, zapis przez granicę strony, odwrócona kolejność współczynników wielomianu, zła skala temperatury, polecenie I2C ponad 128 B, pominięcie ramek w `sfpb_process()`, brak zgłoszenia obcięcia.

**Kompilacja portów** (`arm-none-eabi-gcc`, nagłówki STM32Cube, `-Wall -Wextra -Wconversion -Werror`, z DMA i bez):

| Transport | Układ | Pakiet STM32Cube |
|---|---|---|
| OCTOSPI (`HAL_OSPI`) | STM32L4R5 | FW_L4 1.18.2 |
| XSPI (`HAL_XSPI`) | STM32H563 | FW_H5 1.3.0 |
| QUADSPI (`HAL_QSPI`) | STM32F446, STM32L476 | FW_F4 1.28.3, FW_L4 1.18.2 |
| SPI (`HAL_SPI`) | STM32G0B1 | FW_G0 1.6.3 |

Konfiguracje z wyłączonymi funkcjami (`SFPB_USE_I2C`, `_DDM`, `_UART`, `_EVENTS`, `_FLOAT`, `SFPB_DDM_EXT_CAL` w różnych kombinacjach) kompilują się bez ostrzeżeń. Działanie na sprzęcie wymaga potwierdzenia na płytce rev. A.

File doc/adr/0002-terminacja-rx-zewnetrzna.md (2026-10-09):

# 0002. Terminacja toru RX zewnętrzna, wewnętrzna jako opcja awaryjna

**Stan:** przyjęta · **Data:** 2026-10-08
**Dotyczy:** pcb, vhdl

## Kontekst

Wejście true LVDS wymaga terminacji różnicowej 100 Ω. GW1N-9 ma programowalną terminację 100 Ω wyłącznie w banku 0 (UG289, rozdz. 3.3.2; atrybut `DIFF_RESISTOR`, akceptowany przez Gowin EDA tylko dla pinów banku 0).

Wyjście RD modułu SFP jest typu CML i jest sprzężone pojemnościowo. Po stronie odbiornika wymagane jest zewnętrzne ustalenie napięcia wspólnego (ok. 1,2 V, w zakresie VCM 0,05–2,1 V wejścia FPGA) niezależnie od sposobu terminacji.

## Rozważane warianty

1. **Terminacja wewnętrzna** (`DIFF_RESISTOR=ON`) i bias przez 2 × 10 kΩ do Vbias. Brak odcinka linii między terminacją a odbiornikiem. Wartość i tolerancja rezystancji wewnętrznej nie są specyfikowane w DS100. Wiąże tor RX z bankiem 0.
2. **Terminacja zewnętrzna** 2 × 49,9 Ω 1% (0402) z węzłem środkowym do Vbias i kondensatorem 100 nF do masy. Jeden układ realizuje terminację i bias; kondensator tłumi zakłócenia wspólne. Znana tolerancja. Odcinek linii od rezystorów do pinów ok. 1–2 mm, pomijalny przy czasach narastania 100–200 ps i 100 Mbaud.

## Decyzja

Wariantem podstawowym jest **terminacja zewnętrzna** (wariant 2). W `.cst` obowiązuje `DIFF_RESISTOR=OFF`.

Para RD pozostaje w banku 0 (piny 43/42), aby zachować terminację wewnętrzną jako opcję awaryjną bez zmiany płytki: rezystory 49,9 Ω niemontowane, footprinty 2 × 10 kΩ do Vbias zmontowane, `DIFF_RESISTOR=ON`.

## Konsekwencje

- Płytka zawiera 2 × 49,9 Ω (montowane) i 2 × 10 kΩ (DNP) przy pinach 42/43 oraz dzielnik Vbias z kondensatorem.
- Jednoczesne użycie obu terminacji daje ok. 50 Ω i jest niedopuszczalne.
- Tor RX może zostać przeniesiony poza bank 0 (alternatywy w [koncepcji konstrukcji](../sfp-xspi-bridge-plan.md), tabela 3.3); wtedy atrybut `DIFF_RESISTOR` musi zostać usunięty z `.cst`, a opcja awaryjna przestaje istnieć.

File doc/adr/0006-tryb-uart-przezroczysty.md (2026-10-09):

# 0006. Tryb przezroczysty UART obok trybu xSPI

**Stan:** przyjęta · **Data:** 2026-10-08
**Dotyczy:** pcb, vhdl, firmware, doc

## Kontekst

Mostek jest projektowany jako urządzenie podrzędne hosta STM32 z interfejsem SPI/QSPI/OCTOSPI, wymagające sterownika i konfiguracji. Pożądany jest dodatkowy tryb „przezroczysty”: strumień bajtów podany na UART jednego mostka pojawia się na UART drugiego, bez konfiguracji i bez wiedzy urządzeń końcowych o łączu światłowodowym.

Tryb ten upraszcza także uruchomienie sprzętu: łącze światłowodowe można sprawdzić dwoma adapterami USB-UART i terminalem, przed napisaniem sterownika OCTOSPI.

## Rozważane warianty

**Wybór trybu:** (a) zworka na PCB + rejestr; (b) rejestr z zapisem w Flash użytkownika FPGA; (c) tylko zworka.
**Prędkość UART:** (a) 115200 domyślnie + rejestr; (b) stałe 115200; (c) zworki.
**Sterowanie przepływem:** (a) opcjonalne RTS/CTS; (b) brak.

## Decyzja

- **Wybór trybu — zworka + rejestr.** Pin 10 FPGA (`MODE_SEL`, dotychczas zapasowy, IOL15A/GCLKT_6) z pull-upem: zworka otwarta → tryb xSPI, zwarta do masy → tryb UART. Stan pinu jest próbkowany po resecie. W trybie xSPI rejestr `MODE_CTRL` pozwala przełączyć mostek na UART bez restartu.
- **Prędkość — 115200 8N1 domyślnie**, bez konfiguracji. W trybie xSPI rejestr `UART_DIV` ustawia inną prędkość, do ok. 3 Mbaud.
- **RTS/CTS — opcjonalne**, domyślnie wyłączone, włączane bitem w `MODE_CTRL`.
- **Piny w trybie UART** (złącze J3, bez zmian na PCB poza `MODE_SEL`):

| Sygnał | Pin J3 | Pin FPGA | Kierunek (z punktu widzenia FPGA) |
|---|---|---|---|
| `UART_RX` | 7 (`XSPI_IO0`) | 15 | wejście — dane od urządzenia |
| `UART_TX` | 8 (`XSPI_IO1`) | 16 | wyjście — dane do urządzenia |
| `UART_RTS_N` | 9 (`XSPI_IO2`) | 17 | wyjście — FPGA może przyjmować dane (aktywny niskim) |
| `UART_CTS_N` | 10 (`XSPI_IO3`) | 18 | wejście — urządzenie może przyjmować dane (aktywny niskim) |

  Pozostałe linie xSPI są w trybie UART w stanie wysokiej impedancji; `HOST_IRQ_N` sygnalizuje stan łącza (niski = łącze nieaktywne).

- **Pakietyzacja:** bajty z UART są zbierane w ramkę łącza ([ADR 0005](0005-protokol-lacza.md)) o typie `TYPE = 0x01` (strumień UART). Ramka jest wysyłana po zebraniu 64 bajtów albo po przerwie na linii RX dłuższej niż 2 czasy znaku. Strona odbiorcza wysyła treść ramek typu `0x01` na `UART_TX` w kolejności odbioru.
- **Współpraca trybów:** mostek w trybie xSPI przekazuje ramki `TYPE = 0x01` hostowi jak inne ramki i może je wysyłać, więc host STM32 po jednej stronie może komunikować się z urządzeniem UART po drugiej.

## Konsekwencje

- PCB: zworka lutowana między pinem 10 FPGA a masą oraz rezystor pull-up 10 kΩ do 3,3 V (dodatkowo wewnętrzny pull-up FPGA `PULL_MODE=UP`). Pin 10 przestaje być zapasowy.
- `.cst`: port `mode_sel` na pinie 10.
- Nowe moduły VHDL: `uart_rx`, `uart_tx`, `uart_bridge` (pakietyzator/depakietyzator, RTS/CTS), multipleksowanie pinów J3 w topie; szacunkowo ok. 300 LUT.
- Nowe rejestry CSR: `MODE_CTRL`, `UART_DIV`, `UART_STATUS`.
- Przy różnych prędkościach UART po obu stronach i wyłączonym RTS/CTS dane mogą zostać utracone przy przepełnieniu bufora strony wolniejszej; strata jest zliczana.

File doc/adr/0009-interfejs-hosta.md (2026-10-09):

# 0009. Interfejs hosta: ramki w formacie surowym, rejestry zatrzaskiwane przy CS, zegar strony hosta przez DCS

**Stan:** przyjęta · **Data:** 2026-10-08
**Dotyczy:** vhdl, firmware, doc (zmienia wstępną mapę rejestrów, uzupełnia [ADR 0006](0006-tryb-uart-przezroczysty.md) i [ADR 0008](0008-stan-lacza.md))

## Kontekst

Slave xSPI pracuje w domenie zegara hosta (SCLK), bo przy tej częstotliwości SCLK nie da się nadpróbkować zegarem `clk_sys` ([koncepcja konstrukcji](../sfp-xspi-bridge-plan.md), rozdz. 3). SCLK biegnie wyłącznie w czasie transakcji. Strona hosta FIFO (zapis FIFO TX, odczyt FIFO RX) pracuje na tym samym zegarze, aby przepustowość OCTOSPI (do 50 MB/s) nie wymagała dodatkowego bufora.

Szkic mapy rejestrów zakładał rejestry ramek: `TX_TYPE`, `TX_LEN`, `TX_COMMIT`, `RX_TYPE`, `RX_LEN`, `RX_POP`. Wymagają one operacji na FIFO pomiędzy transakcjami, gdy zegar strony hosta stoi (np. `RX_LEN` wymaga wcześniejszego wyjęcia nagłówka z FIFO). Rejestry sterujące i stanu są natomiast potrzebne w domenie `clk_sys` (`link_ctrl`, UART, I2C), a odczyt rejestru przez xSPI ma tylko kilka taktów SCLK na przejście między domenami. Liczniki 32-bitowe wymagają spójnego odczytu wielobajtowego.

Tryb UART ([ADR 0006](0006-tryb-uart-przezroczysty.md)) i echo ramek ([ADR 0008](0008-stan-lacza.md)) obsługują stronę hosta FIFO z logiki w domenie `clk_sys` — zegar strony hosta zależy więc od trybu.
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

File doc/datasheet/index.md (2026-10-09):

# SFP-xSPI Bridge — interfejs hosta

**Rozdział dokumentacji technicznej: komunikacja SPI / QSPI / OSPI, tryb przezroczysty UART, mapa rejestrów**

Wersja bitstreamu: `VERSION` = 0x01 · płytka rev. A · źródło: kod VHDL `vhdl/sfp_bridge/src` (commit z etapem 10)

---

## 1 Cechy
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

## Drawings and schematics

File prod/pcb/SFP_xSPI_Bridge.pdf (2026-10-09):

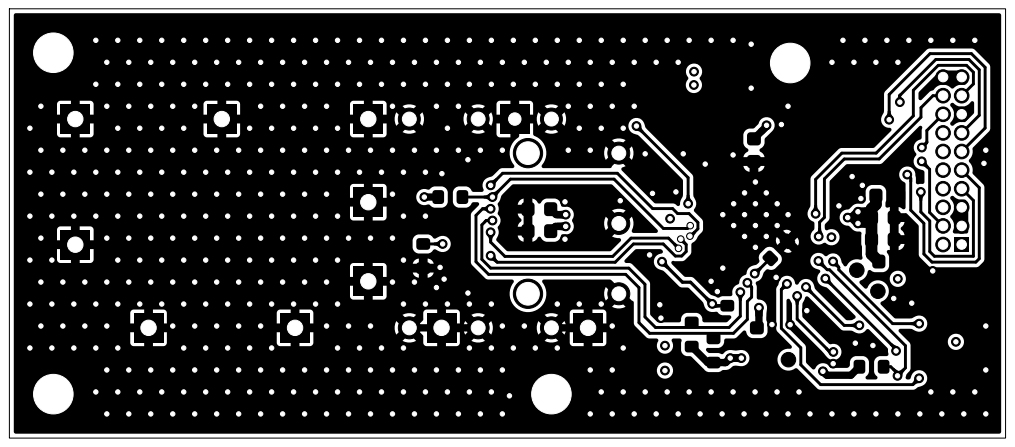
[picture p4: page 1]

Size: A4 | Rev:
KiCad E.D.A. 10.0.7 | Id: 1/6

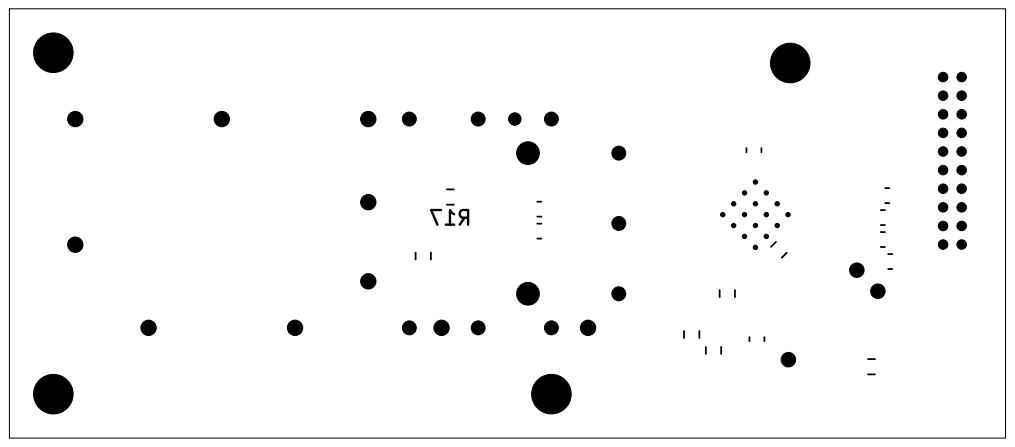
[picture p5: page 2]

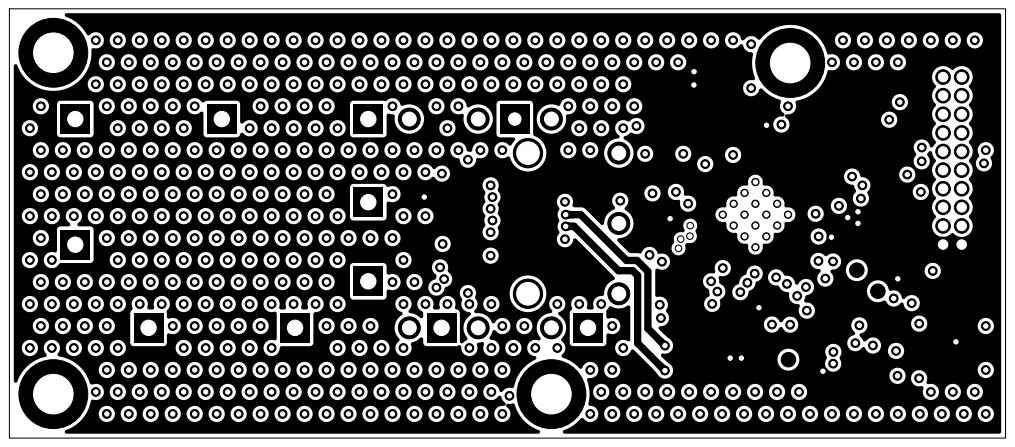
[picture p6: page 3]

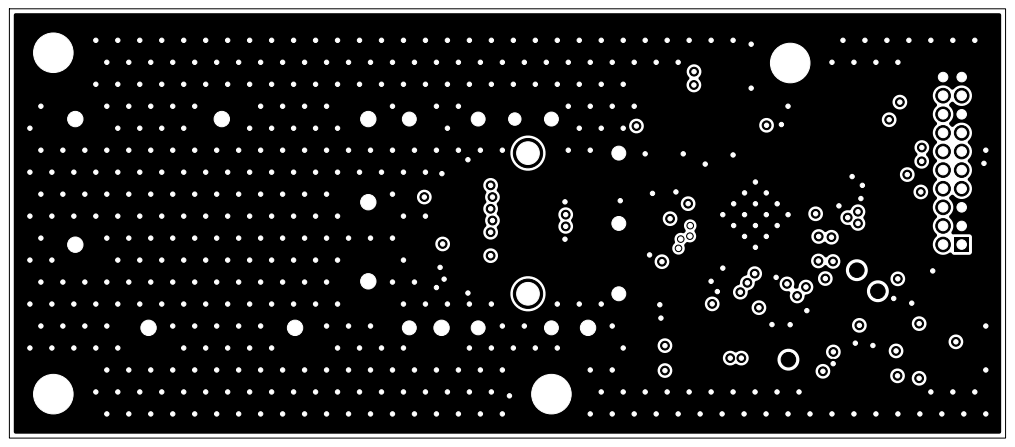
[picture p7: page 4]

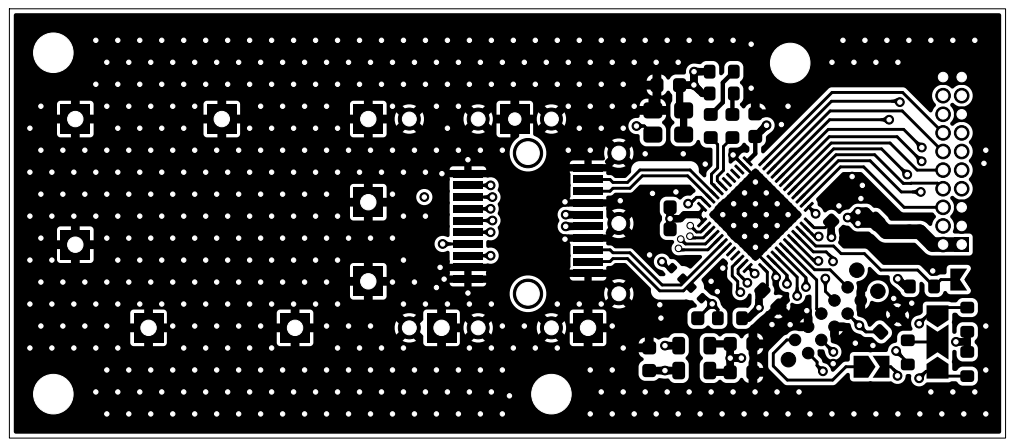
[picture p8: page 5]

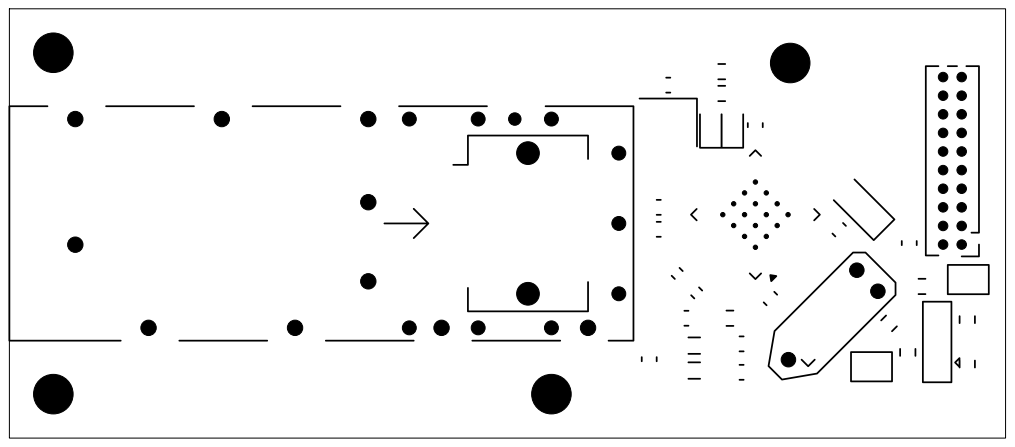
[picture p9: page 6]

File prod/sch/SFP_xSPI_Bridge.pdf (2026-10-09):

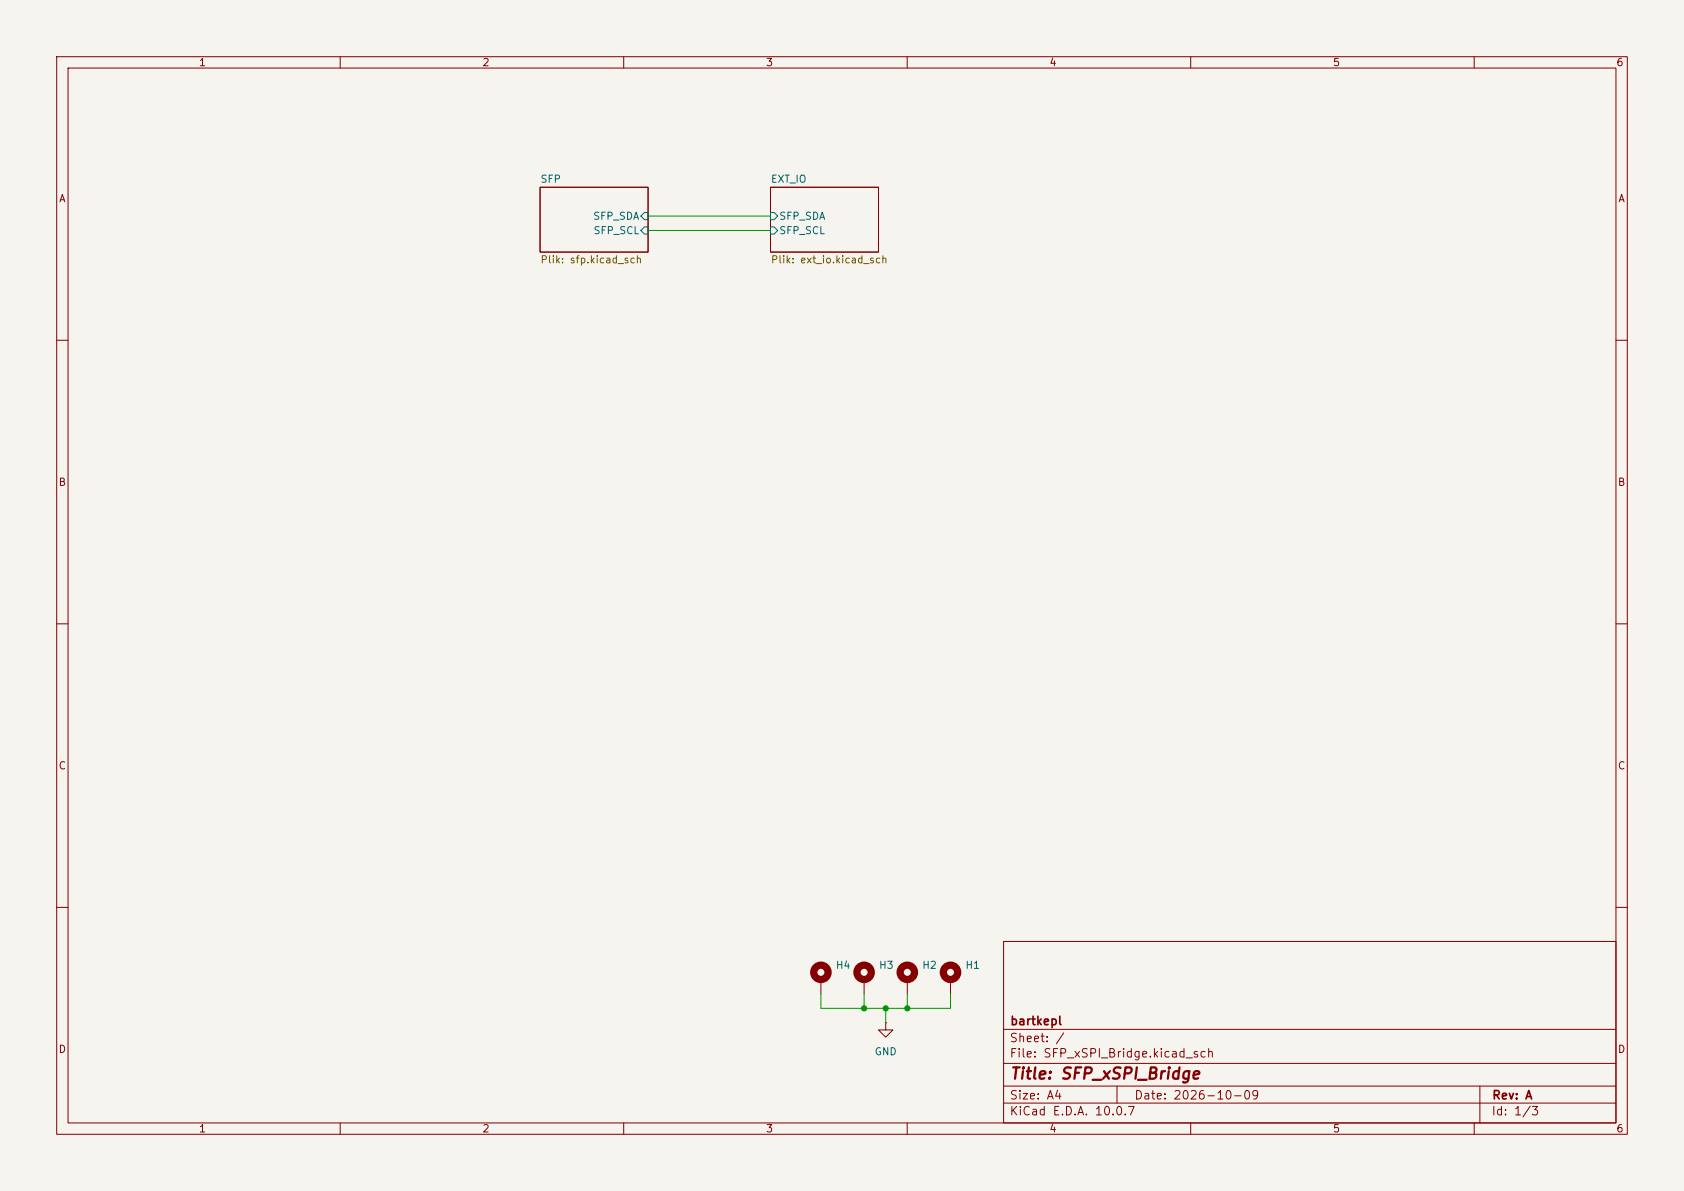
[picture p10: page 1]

Size: A4 | Rev: A
KiCad E.D.A. 10.0.7 | Id: 1/3

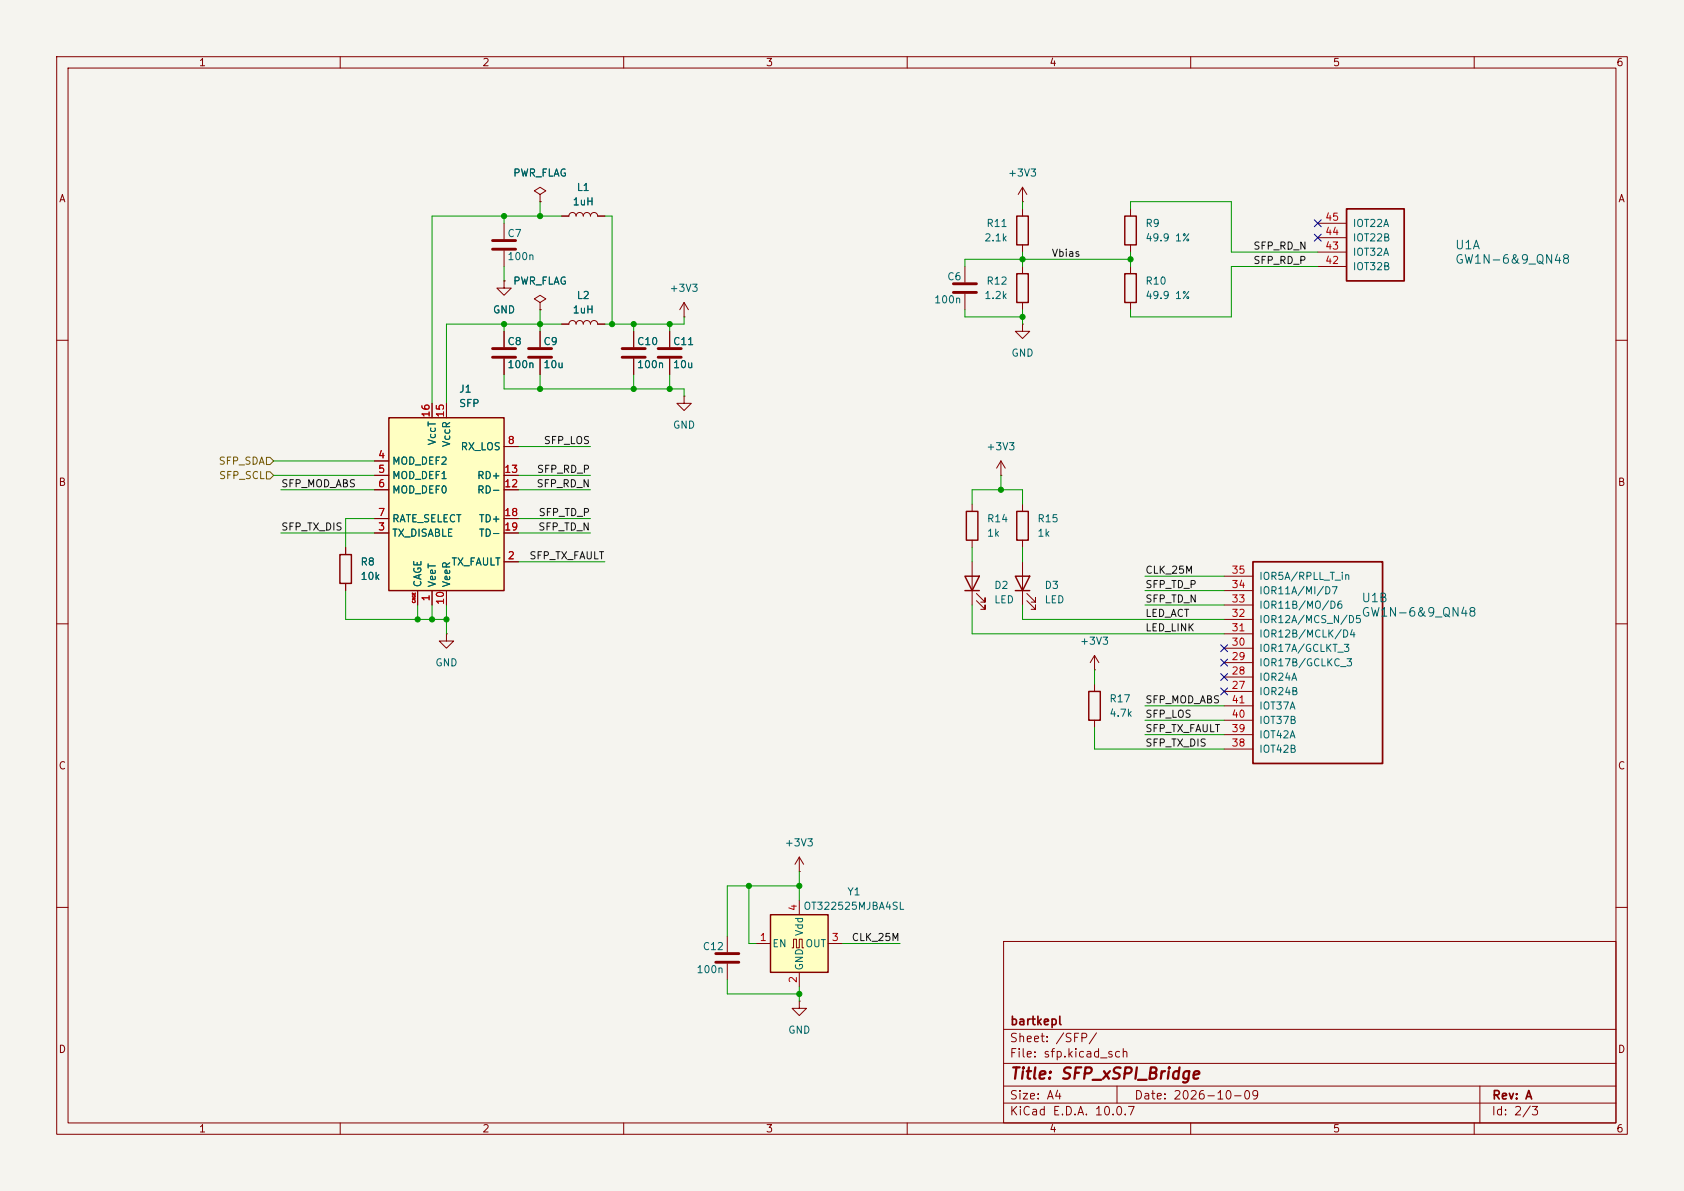
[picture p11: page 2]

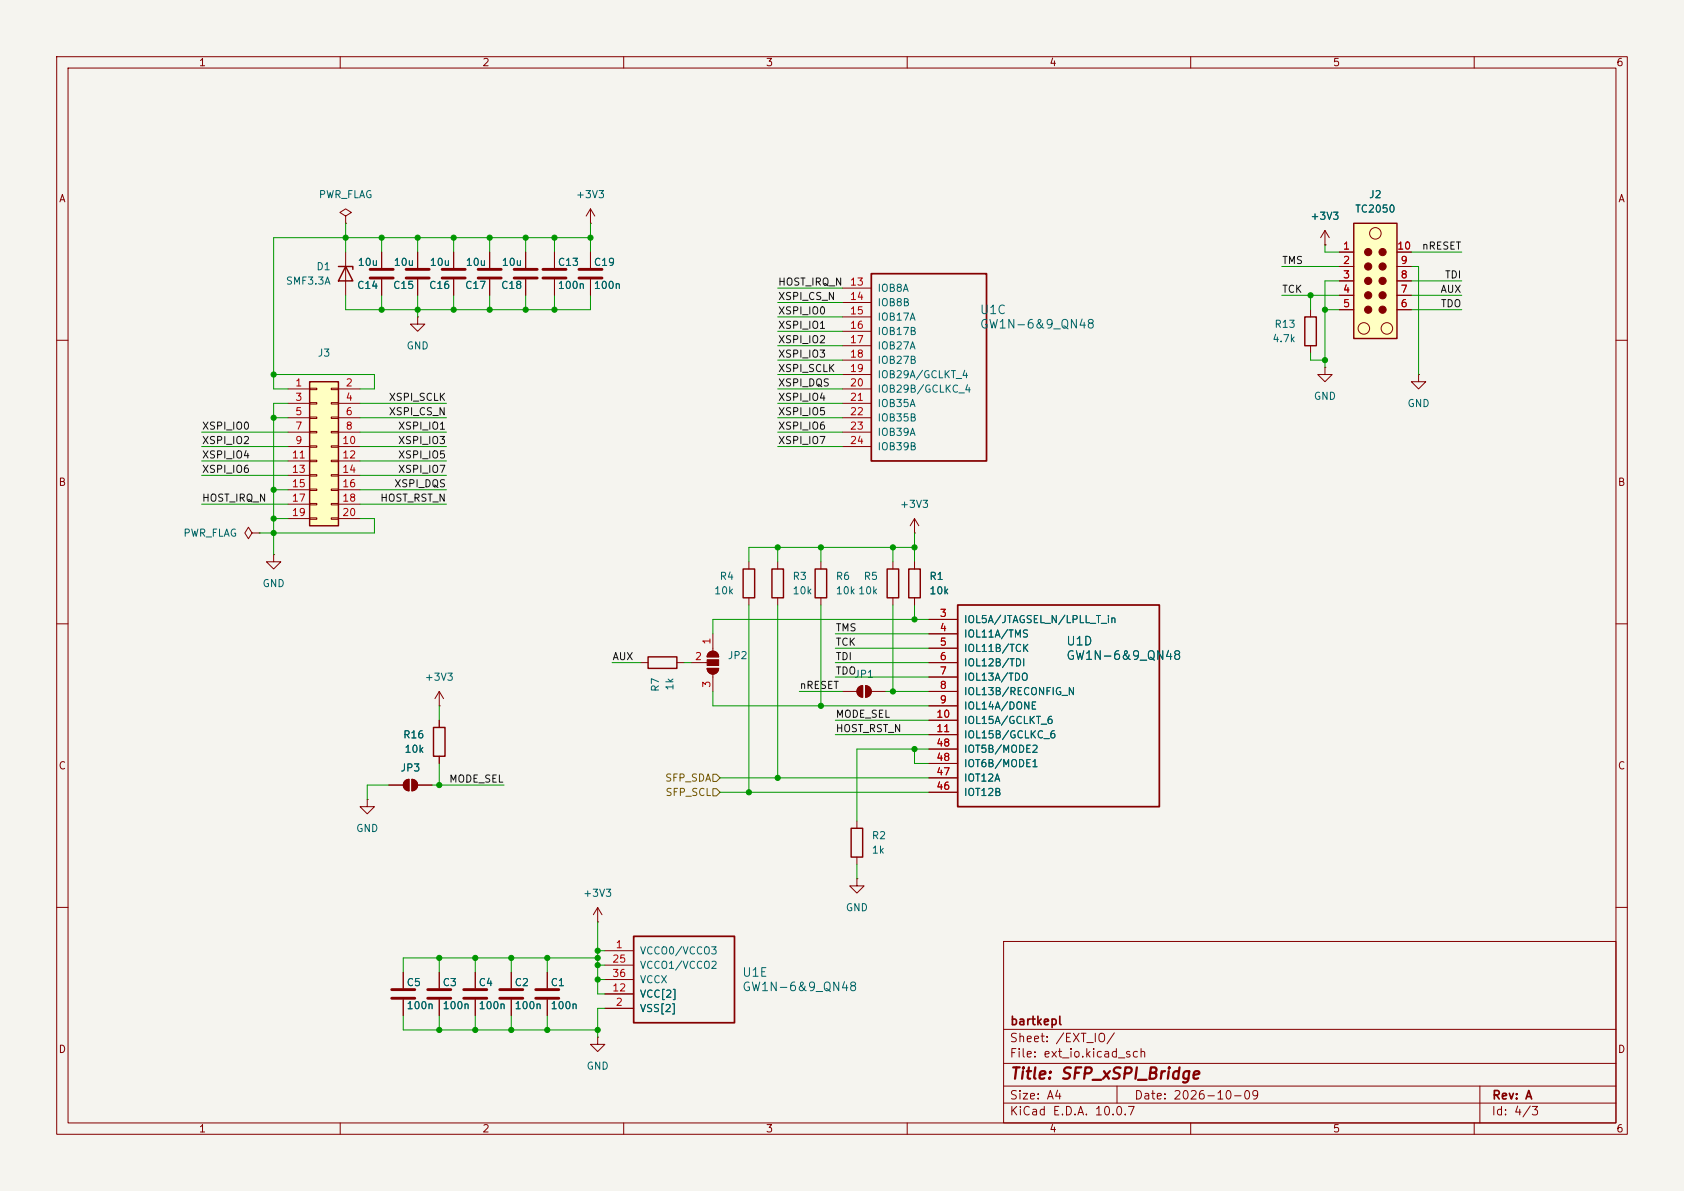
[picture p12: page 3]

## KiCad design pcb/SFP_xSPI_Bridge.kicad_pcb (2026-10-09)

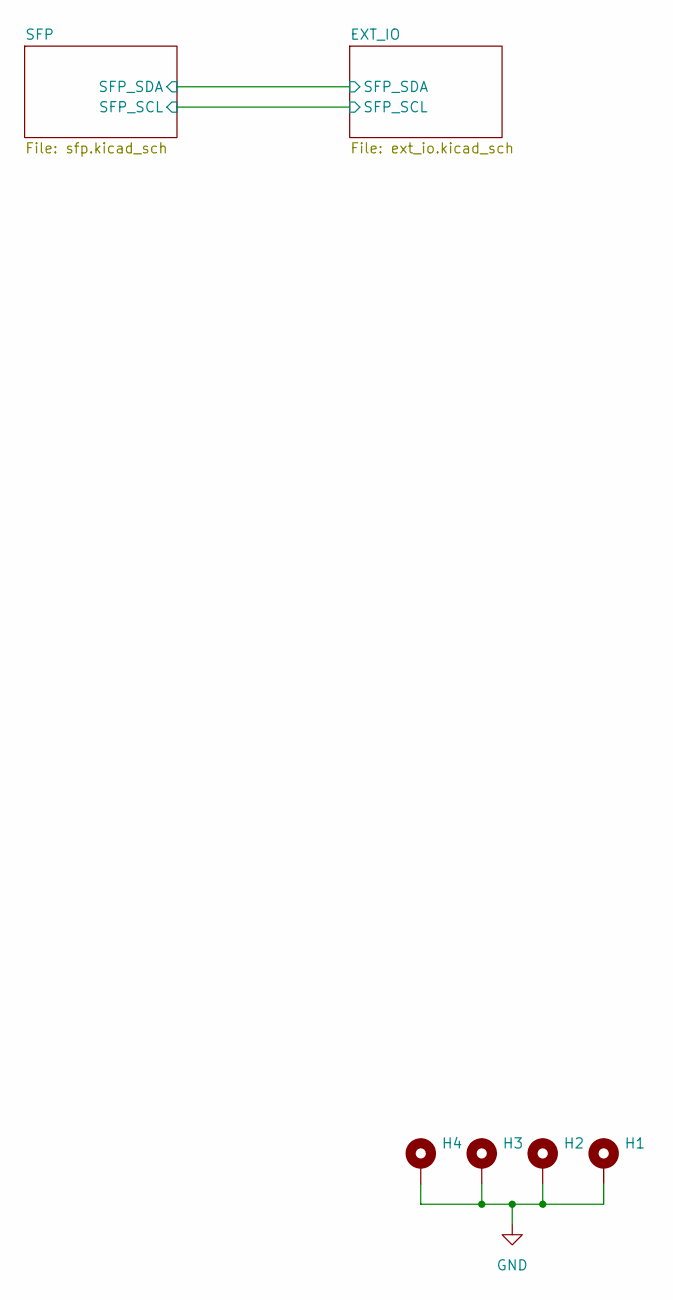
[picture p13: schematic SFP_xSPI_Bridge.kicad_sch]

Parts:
H1, H2, H3, H4: MountingHole_Pad; MountingHole_2.7mm_M2.5_DIN965_Pad

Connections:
GND: H1.1 (1_1), H2.1 (1_1), H3.1 (1_1), H4.1 (1_1); also elsewhere on the board

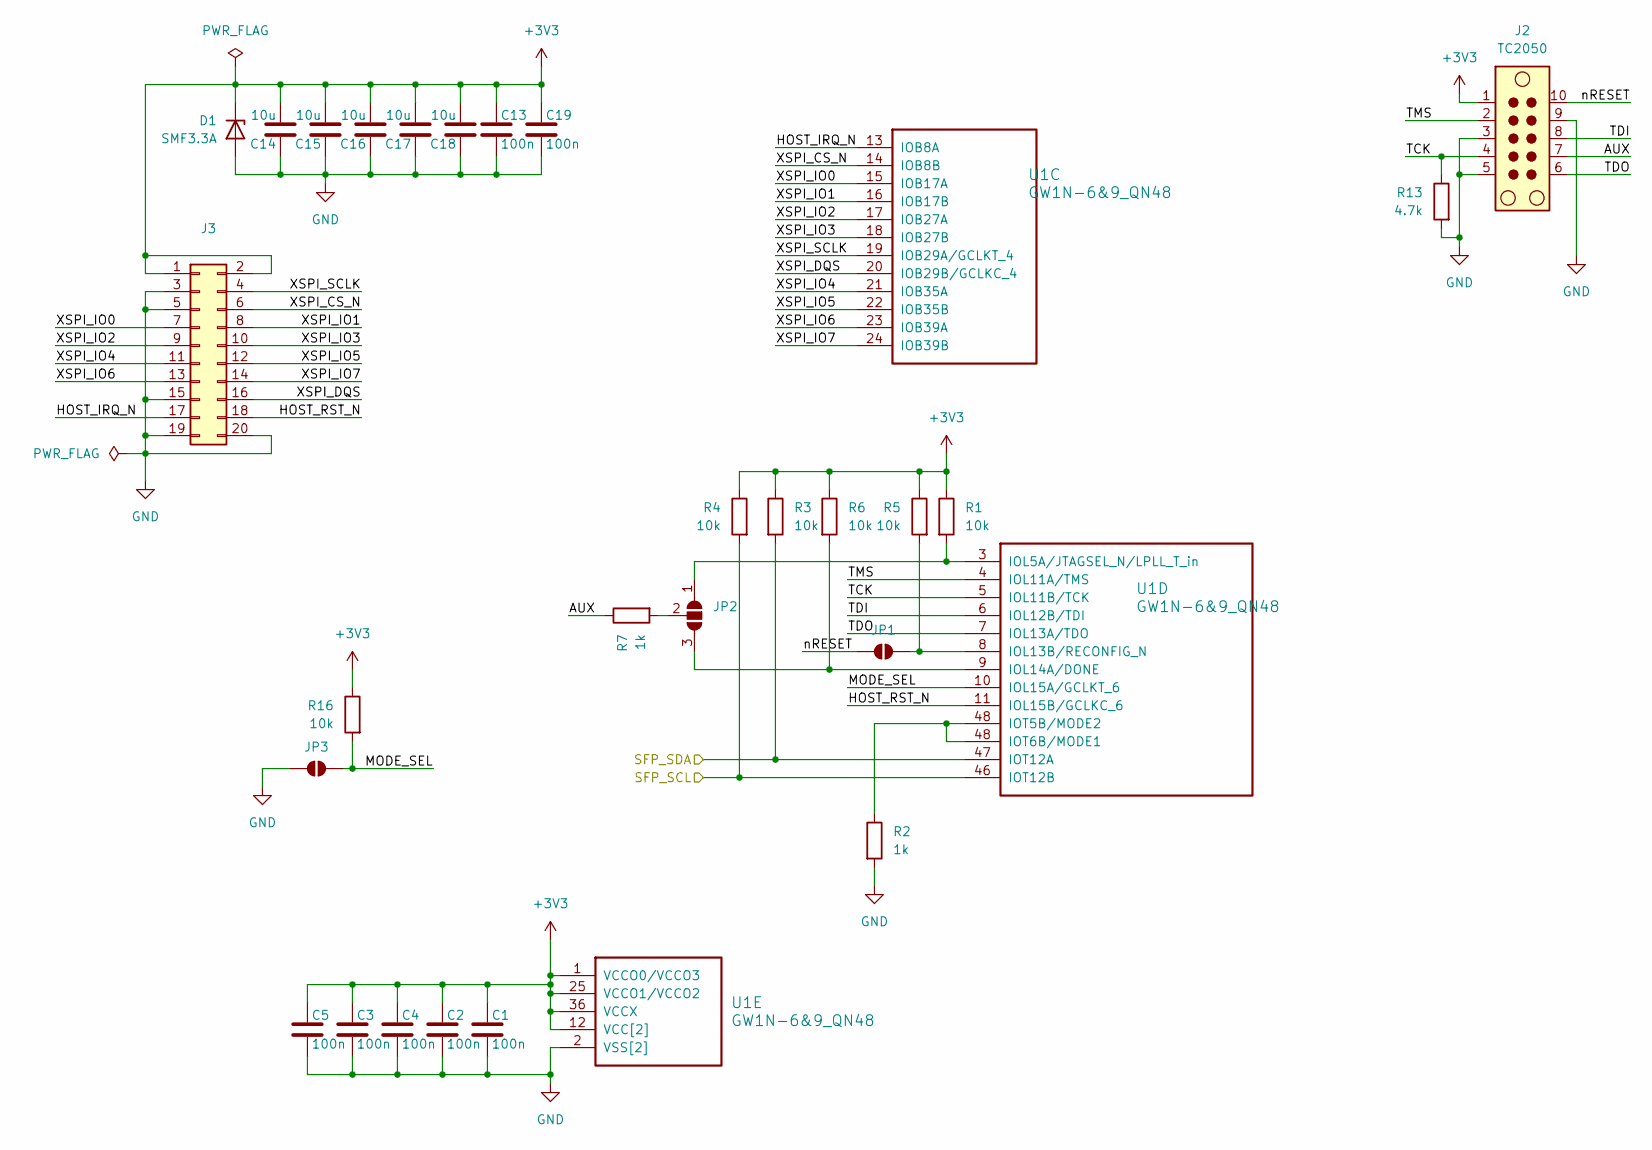
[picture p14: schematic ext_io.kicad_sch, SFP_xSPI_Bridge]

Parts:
C1, C2, C3, C4, C5, C13, C19: 100n; C_0603_1608Metric
C14, C15, C16, C17, C18: 10u; C_0603_1608Metric
D1: SMF3.3A; D_SOD-123F
J2: TC2050; Tag-Connect_TC2050-IDC-NL_2x05_P1.27mm_Vertical
J3: Conn_02x10_Odd_Even; PinHeader_2x10_P1.27mm_Vertical
JP1, JP3: SolderJumper_2_Open; SolderJumper-2_P1.3mm_Open_TrianglePad1.0x1.5mm
JP2: SolderJumper_3_Open; SolderJumper-3_P2.0mm_Open_TrianglePad1.0x1.5mm
R1, R3, R4, R5, R6, R16: 10k; R_0603_1608Metric
R2, R7: 1k; R_0603_1608Metric
R13: 4.7k; R_0603_1608Metric
U1: GW1N-6&9_QN48; QFN-48-1EP_6x6mm_P0.4mm_EP4.2x4.2mm_ThermalVias

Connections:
+3V3: C1.1, C2.1, C3.1, C4.1, C5.1, C13.1, C14.2, C15.2, C16.2, C17.2, C18.2, C19.1, D1.1 (K), J2.1, J3.1, J3.2, R1.1, R3.1, R4.1, R5.1, R6.1, R16.1, U1.1 (VCCO0/VCCO3), U1.12 (VCC[2]), U1.25 (VCCO1/VCCO2), U1.36 (VCCX), U1.37 (VCC[2]); also elsewhere on the board
/EXT_IO/AUX: J2.7, R7.1
/EXT_IO/HOST_IRQ_N: J3.17, U1.13 (IOB8A)
/EXT_IO/HOST_RST_N: J3.18, U1.11 (IOL15B/GCLKC_6)
/EXT_IO/MODE_SEL: JP3.2 (B), R16.2, U1.10 (IOL15A/GCLKT_6)
/EXT_IO/SFP_SCL: R4.2, U1.46 (IOT12B); also elsewhere on the board
/EXT_IO/SFP_SDA: R3.2, U1.47 (IOT12A); also elsewhere on the board
/EXT_IO/TCK: J2.4, R13.1, U1.5 (IOL11B/TCK)
/EXT_IO/TDI: J2.8, U1.6 (IOL12B/TDI)
/EXT_IO/TDO: J2.6, U1.7 (IOL13A/TDO)
/EXT_IO/TMS: J2.2, U1.4 (IOL11A/TMS)
/EXT_IO/XSPI_CS_N: J3.6, U1.14 (IOB8B)
/EXT_IO/XSPI_DQS: J3.16, U1.20 (IOB29B/GCLKC_4)
/EXT_IO/XSPI_IO0: J3.7, U1.15 (IOB17A)
/EXT_IO/XSPI_IO1: J3.8, U1.16 (IOB17B)
/EXT_IO/XSPI_IO2: J3.9, U1.17 (IOB27A)
/EXT_IO/XSPI_IO3: J3.10, U1.18 (IOB27B)
/EXT_IO/XSPI_IO4: J3.11, U1.21 (IOB35A)
/EXT_IO/XSPI_IO5: J3.12, U1.22 (IOB35B)
/EXT_IO/XSPI_IO6: J3.13, U1.23 (IOB39A)
/EXT_IO/XSPI_IO7: J3.14, U1.24 (IOB39B)
/EXT_IO/XSPI_SCLK: J3.4, U1.19 (IOB29A/GCLKT_4)
/EXT_IO/nRESET: J2.10, JP1.1 (A)
GND: C1.2, C2.2, C3.2, C4.2, C5.2, C13.2, C14.1, C15.1, C16.1, C17.1, C18.1, C19.2, D1.2 (A), J2.3, J2.5, J2.9, J3.3, J3.5, J3.15, J3.19, J3.20, JP3.1 (A), R2.2, R13.2, U1.2 (VSS[2]), U1.26 (VSS[2]), U1.49 (EPAD); also elsewhere on the board
unnamed: JP1.2 (B), R5.2, U1.8 (IOL13B/RECONFIG_N)
unnamed: JP2.1 (A), R1.2, U1.3 (IOL5A/JTAGSEL_N/LPLL_T_in)
unnamed: JP2.3 (B), R6.2, U1.9 (IOL14A/DONE)
unnamed: JP2.2 (C), R7.2
unnamed: R2.1, U1.48 (IOT5B/MODE2)

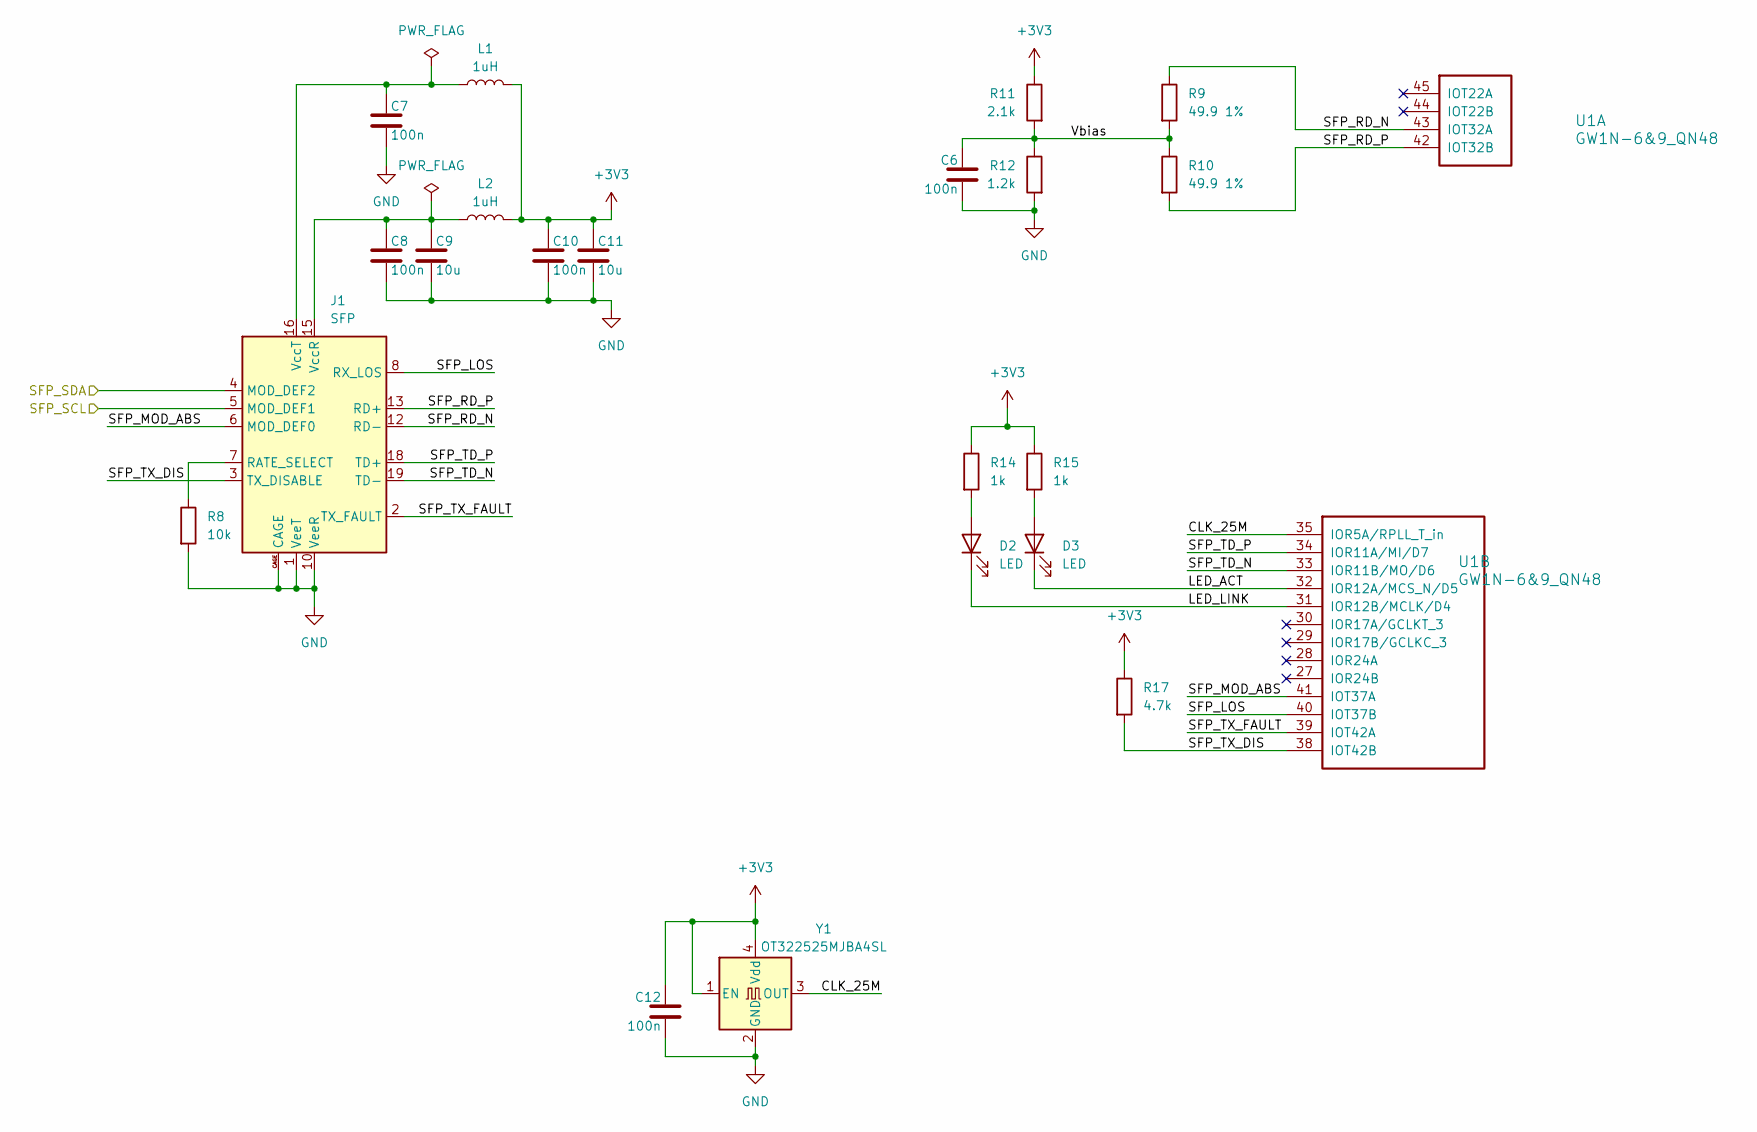
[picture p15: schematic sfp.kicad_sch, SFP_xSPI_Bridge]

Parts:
C6, C7, C8, C10, C12: 100n; C_0603_1608Metric
C9, C11: 10u; C_0603_1608Metric
D2: LED; LED_0603_1608Metric; MPN XL-1608SYGC-06; LCSC C965805
D3: LED; LED_0603_1608Metric; MPN XL-1608UOC-06; LCSC C965800
J1: SFP; Connector_SFP_and_Cage
L1, L2: 1uH; L_0805_2012Metric; MPN NL05KTC1R0
R8: 10k; R_0603_1608Metric
R9, R10: 49.9 1%; R_0402_1005Metric
R11: 2.1k; R_0603_1608Metric
R12: 1.2k; R_0603_1608Metric
R14, R15: 1k; R_0603_1608Metric
R17: 4.7k; R_0603_1608Metric
U1: GW1N-6&9_QN48; QFN-48-1EP_6x6mm_P0.4mm_EP4.2x4.2mm_ThermalVias
Y1: OT322525MJBA4SL; Oscillator_SMD_Abracon_ASE-4Pin_3.2x2.5mm; MPN OT322525MJBA4SL; LCSC C669088

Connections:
+3V3: C10.1, C11.1, C12.1, L1.2, L2.2, R11.1, R14.1, R15.1, R17.1, Y1.1 (EN), Y1.4 (Vdd); also elsewhere on the board
/EXT_IO/SFP_SCL: J1.5 (MOD_DEF1); also elsewhere on the board
/EXT_IO/SFP_SDA: J1.4 (MOD_DEF2); also elsewhere on the board
/SFP/CLK_25M: U1.35 (IOR5A/RPLL_T_in), Y1.3 (OUT)
/SFP/LED_ACT: D3.1 (K), U1.32 (IOR12A/MCS_N/D5)
/SFP/LED_LINK: D2.1 (K), U1.31 (IOR12B/MCLK/D4)
/SFP/SFP_LOS: J1.8 (RX_LOS), U1.40 (IOT37B)
/SFP/SFP_MOD_ABS: J1.6 (MOD_DEF0), U1.41 (IOT37A)
/SFP/SFP_RD_N: J1.12 (RD-), R9.1, U1.43 (IOT32A)
/SFP/SFP_RD_P: J1.13 (RD+), R10.2, U1.42 (IOT32B)
/SFP/SFP_TD_N: J1.19 (TD-), U1.33 (IOR11B/MO/D6)
/SFP/SFP_TD_P: J1.18 (TD+), U1.34 (IOR11A/MI/D7)
/SFP/SFP_TX_DIS: J1.3 (TX_DISABLE), R17.2, U1.38 (IOT42B)
/SFP/SFP_TX_FAULT: J1.2 (TX_FAULT), U1.39 (IOT42A)
/SFP/Vbias: C6.1, R9.2, R10.1, R11.2, R12.1
GND: C6.2, C7.2, C8.2, C9.2, C10.2, C11.2, C12.2, J1.1 (VeeT), J1.9 (VeeR), J1.10 (VeeR), J1.11 (VeeR), J1.14 (VeeR), J1.17 (VeeT), J1.20 (VeeT), J1.CAGE, R8.2, R12.2, Y1.2 (GND); also elsewhere on the board
unnamed: D2.2 (A), R14.2
unnamed: D3.2 (A), R15.2
unnamed: J1.7 (RATE_SELECT), R8.1
unnamed: C8.1, C9.1, J1.15 (VccR), L2.1
unnamed: C7.1, J1.16 (VccT), L1.1

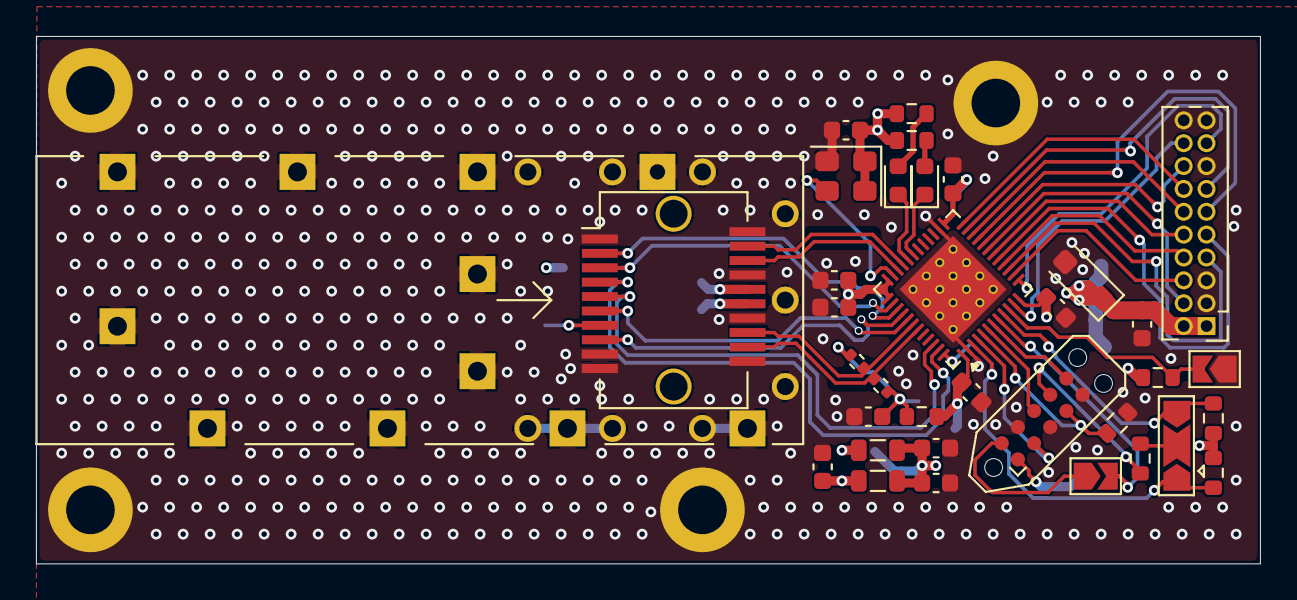
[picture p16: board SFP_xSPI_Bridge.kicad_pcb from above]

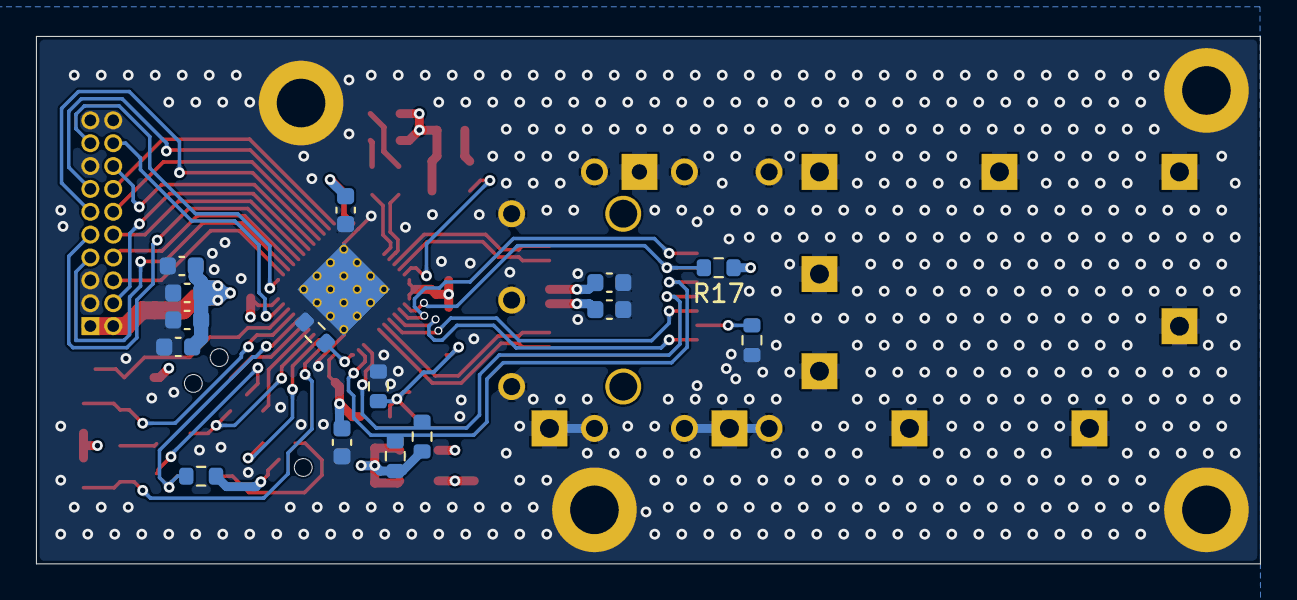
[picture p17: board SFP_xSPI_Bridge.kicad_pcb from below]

Board: 4 copper layers, 68.0 x 29.3 mm, 53 parts (15 on the bottom side), 46 nets.

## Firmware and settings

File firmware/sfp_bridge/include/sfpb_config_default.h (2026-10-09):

/*
 * sfpb_config_default.h - compile-time configuration of the SFP-xSPI bridge
 * library: the user file sfpb_config.h (template: config/sfpb_config_template.h)
 * followed by the defaults of everything it does not define.
 *
 * The user file is found in this order:
 *   1. SFPB_CONFIG_FILE defined on the compiler command line
 *      (e.g. -DSFPB_CONFIG_FILE=\"my_cfg.h\"),
 *   2. sfpb_config.h on the include path (when the compiler has __has_include),
 *   3. none - SFPB_NO_CONFIG_FILE must then be defined to confirm the defaults.
 *
 * SPDX-License-Identifier: MIT
 */
#ifndef SFPB_CONFIG_DEFAULT_H
#define SFPB_CONFIG_DEFAULT_H

#if defined(SFPB_CONFIG_FILE)
#include SFPB_CONFIG_FILE
#elif defined(__has_include)
#if __has_include("sfpb_config.h")
#include "sfpb_config.h"
#elif !defined(SFPB_NO_CONFIG_FILE)
#error "sfpb_config.h not found (copy config/sfpb_config_template.h) or define SFPB_NO_CONFIG_FILE"
#endif
#elif !defined(SFPB_NO_CONFIG_FILE)
#include "sfpb_config.h"
#endif

/* ---- Transport -------------------------------------------------------------- */
#define SFPB_TRANSPORT_CUSTOM  0   /* port supplied by the application          */
#define SFPB_TRANSPORT_OSPI    1   /* HAL_OSPI  (L4+, L5, U5, H7A3/B3, H72x...)  */
#define SFPB_TRANSPORT_XSPI    2   /* HAL_XSPI  (H5, H7R/S, N6, U5 new HAL...)   */
#define SFPB_TRANSPORT_QSPI    3   /* HAL_QSPI  (F4, F7, H7, L4, G4)             */
#define SFPB_TRANSPORT_SPI     4   /* HAL_SPI + GPIO chip select (any STM32)     */

#ifndef SFPB_TRANSPORT
#define SFPB_TRANSPORT SFPB_TRANSPORT_OSPI
#endif

/* Data lines of the frame commands (TX_WRITE_x / RX_READ_x): 1, 4 or 8. */
#ifndef SFPB_DATA_LINES
#if SFPB_TRANSPORT == SFPB_TRANSPORT_QSPI
#define SFPB_DATA_LINES 4
#elif SFPB_TRANSPORT == SFPB_TRANSPORT_SPI
#define SFPB_DATA_LINES 1
#else
#define SFPB_DATA_LINES 8
#endif
#endif

#if (SFPB_DATA_LINES != 1) && (SFPB_DATA_LINES != 4) && (SFPB_DATA_LINES != 8)
#error "SFPB_DATA_LINES must be 1, 4 or 8"
#endif
#if (SFPB_TRANSPORT == SFPB_TRANSPORT_QSPI) && (SFPB_DATA_LINES > 4)
#error "QUADSPI supports at most 4 data lines"
#endif
#if (SFPB_TRANSPORT == SFPB_TRANSPORT_SPI) && (SFPB_DATA_LINES != 1)
#error "SPI transport supports 1 data line only"
#endif

/* HAL header of the target (CubeMX projects: main.h includes stm32xxxx_hal.h). */
#ifndef SFPB_HAL_HEADER
#define SFPB_HAL_HEADER "main.h"
#endif

/* Peripheral handles of the default port (CubeMX global names). */
#ifndef SFPB_OSPI_HANDLE
#define SFPB_OSPI_HANDLE hospi1
#endif
#ifndef SFPB_XSPI_HANDLE
#define SFPB_XSPI_HANDLE hxspi1
#endif
#ifndef SFPB_QSPI_HANDLE
#define SFPB_QSPI_HANDLE hqspi
#endif
#ifndef SFPB_SPI_HANDLE
#define SFPB_SPI_HANDLE hspi1
#endif
/* SPI chip select (GPIO output, idle high) - required for the SPI transport:
 *   #define SFPB_SPI_CS_PORT GPIOA
 *   #define SFPB_SPI_CS_PIN  GPIO_PIN_4                                         */

/* HOST_RST_N (optional GPIO output, idle high). Without it hardware reset,
 * leaving the UART / echo mode and sfpb_uart_exit() are not available:
 *   #define SFPB_RST_PORT GPIOB
 *   #define SFPB_RST_PIN  GPIO_PIN_0                                            */

/* HAL call timeout of one transaction [ms]. */
#ifndef SFPB_HAL_TIMEOUT_MS
#define SFPB_HAL_TIMEOUT_MS 10u
#endif

/* DMA for data phases of at least SFPB_DMA_MIN_LEN bytes (the DMA channel and
 * its interrupt configured by CubeMX; data buffers must be DMA-accessible and,
 * on cores with a data cache, cache-maintained by the application). */
#ifndef SFPB_USE_DMA
#define SFPB_USE_DMA 0
#endif
#ifndef SFPB_DMA_MIN_LEN
#define SFPB_DMA_MIN_LEN 32u
#endif

/* ---- Features --------------------------------------------------------------- */
#ifndef SFPB_USE_I2C            /* SFP module memory: read / write, serial ID     */
#define SFPB_USE_I2C 1
#endif
#ifndef SFPB_USE_DDM            /* digital diagnostics (DDM_* registers)           */
#define SFPB_USE_DDM 1
#endif
#ifndef SFPB_DDM_EXT_CAL        /* SFF-8472 external calibration (float math)      */
#define SFPB_DDM_EXT_CAL 1
#endif
#ifndef SFPB_USE_FLOAT          /* float helpers (dBm conversion)                  */
#define SFPB_USE_FLOAT 1
#endif
#ifndef SFPB_USE_UART           /* UART_DIV, MODE_CTRL, UART_STATUS, echo          */
#define SFPB_USE_UART 1
#endif
#ifndef SFPB_USE_EVENTS         /* sfpb_process() with callbacks (HOST_IRQ_N)      */
#define SFPB_USE_EVENTS 1
#endif

#if SFPB_USE_DDM && !SFPB_USE_I2C && SFPB_DDM_EXT_CAL
#error "SFPB_DDM_EXT_CAL needs SFPB_USE_I2C (calibration constants are read from A2h)"
#endif

/* IRQ_EN written by sfpb_init() (SFPB_IRQ_* bits). */
#ifndef SFPB_IRQ_MASK_DEFAULT
#if SFPB_USE_EVENTS
#define SFPB_IRQ_MASK_DEFAULT (SFPB_IRQ_RX_FRAME | SFPB_IRQ_LINK_CHG | SFPB_IRQ_SFP_CHG | SFPB_IRQ_ERR)
#else
#define SFPB_IRQ_MASK_DEFAULT 0u
#endif
#endif

/* Receive buffer of sfpb_process() (bytes; frames longer are dropped). */
#ifndef SFPB_RX_BUF_SIZE
#define SFPB_RX_BUF_SIZE SFPB_MAX_PAYLOAD
#endif
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

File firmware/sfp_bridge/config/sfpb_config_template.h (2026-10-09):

/*
 * sfpb_config.h - configuration of the SFP-xSPI bridge library.
 *
 * Copy this file as sfpb_config.h to a directory on the include path of the
 * application and adjust. Every option left undefined takes the default from
 * include/sfpb_config_default.h.
 */
#ifndef SFPB_CONFIG_H
#define SFPB_CONFIG_H

/* ---- Transport ---------------------------------------------------------------
 * SFPB_TRANSPORT_OSPI   HAL_OSPI  (STM32L4+, L5, U5, H7A3/B3, H72x/73x)
 * SFPB_TRANSPORT_XSPI   HAL_XSPI  (STM32H5, H7R/S, N6)
 * SFPB_TRANSPORT_QSPI   HAL_QSPI  (STM32F4, F7, H7, L4, G4)
 * SFPB_TRANSPORT_SPI    HAL_SPI + GPIO chip select (any STM32)
 * SFPB_TRANSPORT_CUSTOM own sfpb_port_t passed to sfpb_init()                  */
#define SFPB_TRANSPORT       SFPB_TRANSPORT_OSPI

/* Data lines of TX_WRITE / RX_READ: 8 (OSPI/XSPI), 4 (QSPI), 1 (SPI). */
#define SFPB_DATA_LINES      8

/* HAL header (CubeMX: main.h). */
#define SFPB_HAL_HEADER      "main.h"

/* Peripheral handle of the default port (name of the CubeMX global). */
#define SFPB_OSPI_HANDLE     hospi1
/* #define SFPB_XSPI_HANDLE  hxspi1 */
/* #define SFPB_QSPI_HANDLE  hqspi  */
/* #define SFPB_SPI_HANDLE   hspi1  */
/* #define SFPB_SPI_CS_PORT  GPIOA       SPI transport: chip select */
/* #define SFPB_SPI_CS_PIN   GPIO_PIN_4 */

/* HOST_RST_N (optional): hardware reset, return from the UART / echo mode. */
/* #define SFPB_RST_PORT     GPIOB */
/* #define SFPB_RST_PIN      GPIO_PIN_0 */

/* DMA for data phases >= SFPB_DMA_MIN_LEN bytes (DMA set up in CubeMX). */
#define SFPB_USE_DMA         0
/* #define SFPB_DMA_MIN_LEN  32 */

/* ---- Features (1 = compiled in) ---------------------------------------------- */
#define SFPB_USE_I2C         1    /* SFP memory, serial ID                      */
#define SFPB_USE_DDM         1    /* digital diagnostics                        */
#define SFPB_DDM_EXT_CAL     1    /* external calibration (float)               */
#define SFPB_USE_FLOAT       1    /* sfpb_nw_to_dbm()                           */
#define SFPB_USE_UART        1    /* UART mode, echo, UART_STATUS               */
#define SFPB_USE_EVENTS      1    /* sfpb_process() + callbacks                 */

/* IRQ_EN after sfpb_init() and after every reset. */
/* #define SFPB_IRQ_MASK_DEFAULT (SFPB_IRQ_RX_FRAME | SFPB_IRQ_LINK_CHG | SFPB_IRQ_SFP_CHG | SFPB_IRQ_ERR) */

/* Receive buffer inside sfpb_t used by sfpb_process() (max. payload 1024). */
/* #define SFPB_RX_BUF_SIZE  1024 */

/* ---- Timeouts [ms] ------------------------------------------------------------- */
/* #define SFPB_TIMEOUT_MS        100   TX space wait of sfpb_send()             */
/* #define SFPB_READY_TIMEOUT_MS  100   READ_ID after a reset                    */
/* #define SFPB_I2C_TIMEOUT_MS    100   one I2C command                          */
/* #define SFPB_EEPROM_WRITE_MS    20   NACK retries after an EEPROM write       */
/* #define SFPB_EEPROM_PAGE         8   EEPROM page size                         */
/* #define SFPB_HAL_TIMEOUT_MS     10   one HAL transfer                         */

#endif /* SFPB_CONFIG_H */

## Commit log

2026-10-07 pcb: pusty projekt KiCad
    [SFP_xSPI_Bridge.kicad_pcb, SFP_xSPI_Bridge.kicad_sch]
2026-10-08 pcb: schemat - wersja robocza (FPGA, modul SFP, zlacza)
    [SFP_xSPI_Bridge.kicad_sch, ext_io.kicad_sch, misc.kicad_sch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]
2026-10-08 pcb: schemat rev. A
    [SFP_xSPI_Bridge.kicad_pcb, SFP_xSPI_Bridge.kicad_sch, ext_io.kicad_sch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]
2026-10-08 doc: przeglad schematu, parametry PCB (stackup JLC04161H-7628, geometria LVDS, klasy sieci), BOM; pcb: reguly DRC; vhdl: wewnetrzne pull-upy SFP
2026-10-08 adr: 0006 tryb przezroczysty UART; doc: plan (MODE_SEL pin 10, rejestry UART); vhdl: port mode_sel w .cst i topach
2026-10-08 doc: aktualizacja README i planu (stan projektu, tryb UART, protokol, zegar 50 MHz, struktura vhdl, BOM JP3/R16, rejestry, bring-up)
2026-10-08 vhdl: cdr_os4x8 (odzysk danych z nadprobkowania 4x, 8 probek na takt) z testbenchem (ppm, jitter); sim: model linii t_line w tb_pkg; doc: opis CDR
2026-10-08 vhdl: tb_link_loopback (pelne lacze dwoch koncow na poziomie bitow, 200 ppm, jitter, ramki w obu kierunkach); doc: etap 4 zakonczony
2026-10-08 vhdl: uart_rx, uart_tx (8N1, dzielnik UART_DIV) z testbenchem; doc: tryb UART
2026-10-08 vhdl: uart_bridge (ramki TYPE 0x01, bufor 64 B, przerwa 2 znaki, RTS/CTS) z testbenchem; doc: etap 7 zakonczony
2026-10-08 vhdl: xspi_slave (SPI/QSPI/OSPI SDR, ramki surowe, logika na zboczu opadajacym) z testbenchem; async_fifo: PUB_STABLE, WR/RD_FALLING, wr_commit_prev; adr: SCLK <= 40 MHz
2026-10-08 vhdl: host_clk (DCS, zegar strony hosta) i frame_echo z testbenchem; doc: etap 9 zakonczony
2026-10-08 pcb: regula odstepu par LVDS obejmuje przelotki i wylewki
2026-10-08 pcb: rozmieszczenie i czesc routingu, odwrocona para RD, reguly i klasy sieci
    [SFP_xSPI_Bridge.kicad_pcb, SFP_xSPI_Bridge.kicad_sch, ext_io.kicad_sch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]
2026-10-08 vhdl: i2c_master i sfp_mgmt (skrzynka I2C, odczyt DDM, sygnaly SFP) z testbenchem; doc: etap 8 zakonczony, mapa rejestrow 0x30-0x4F
2026-10-09 vhdl: sfp_bridge_top (integracja, tryby UART/echo/xSPI, mux J3), leds, sdc z zegarami generowanymi; testy end-to-end SPI/QSPI/OSPI/UART dwoch mostkow
2026-10-09 pcb: routing par LVDS, zasilania i magistrali xSPI
    [SFP_xSPI_Bridge.kicad_pcb, ext_io.kicad_sch, sfp.kicad_sch]
2026-10-09 pcb: regula skew LVDS liczona wewnatrz pary (within_diff_pairs)
2026-10-09 pcb: otwory montazowe, zakonczenie routingu rev. A
    [SFP_xSPI_Bridge.kicad_pcb, SFP_xSPI_Bridge.kicad_sch, sfp.kicad_sch]
2026-10-09 doc: rozdzial datasheetu interfejsu hosta (xSPI, UART, mapa rejestrow) z diagramami
2026-10-09 vhdl: UART_STATUS kasowany tylko przy wlaczeniu zasilania (rst_por), test e2e trybu UART wybranego rejestrem z odczytem UART_STATUS po HOST_RST_N, dokumentacja
2026-10-09 firmware: biblioteka C dla STM32 (sfpb_) konfigurowana przez define - porty HAL OSPI/XSPI/QSPI/SPI, ramki, rejestry, zdarzenia, liczniki, I2C i DDM SFP, tryb UART i echo; testy na PC z modelem mostka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
2026-10-09 repo: skrypty symulacji bez sciezek lokalnych (zmienne srodowiskowe), jobsety KiCad, build.tcl, autor w LICENSE
2026-10-09 pcb: rev. A - obrys, strefy, pull-up SFP_TX_DIS, via stitching, usuniete puste arkusze; pliki produkcyjne: gerbery (zip), PDF schematu i PCB, iBOM, rendery 3D
    [SFP_xSPI_Bridge.kicad_pcb, SFP_xSPI_Bridge.kicad_sch, ext_io.kicad_sch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]
